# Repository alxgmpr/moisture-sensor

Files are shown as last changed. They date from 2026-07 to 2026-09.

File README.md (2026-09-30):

# moisture-sensor

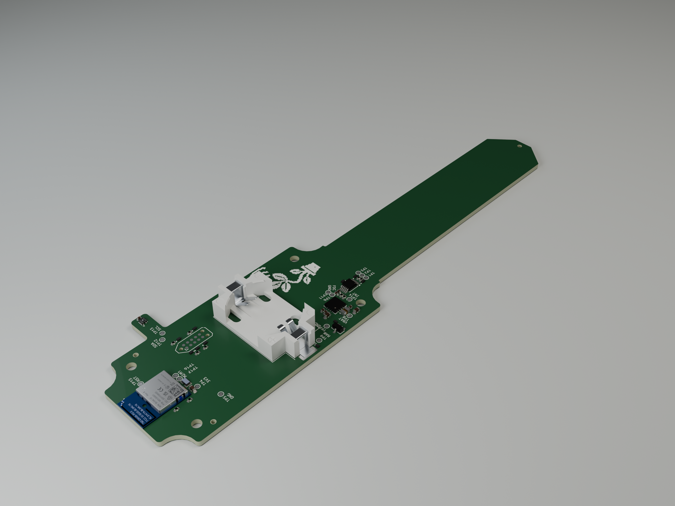
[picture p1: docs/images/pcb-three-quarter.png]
Three-quarter PCB render with the MCU module in the foreground


A CR2032-powered Bluetooth soil-moisture sensor with two capacitive sensing zones. An FDC1004 capacitance-to-digital converter measures the probe, an Ezurio BL54L15 (nRF54L15) broadcasts BTHome v2 readings for Home Assistant, and an SHT40 adds temperature and humidity. Configuration and firmware updates happen over BLE.

**Status:** experimental prototype, firmware 0.2.28. SENSE2 shows a weaker response in soil than SENSE1 ([investigation](docs/sense2-investigation-2026-09-25.md)). Moisture percentages are relative to provisional dry/wet endpoints, and battery life and soil accuracy are not yet characterized.

## How it differs

**Y** = included in the device; **N** = not included. Connectivity reflects stock firmware (the BLE sample for b-parasite); other firmware or an external host can add capabilities.

| Feature | This project | [Seeed XIAO](https://wiki.seeedstudio.com/xiao_soil_moisture_sensor/) | [Adafruit STEMMA](https://www.adafruit.com/product/4026) | [Chirp!](https://wemakethings.net/chirp/) | [b-parasite](https://github.com/rbaron/b-parasite) |
| --- | :---: | :---: | :---: | :---: | :---: |
| Capacitive soil sensing | Y | Y | Y | Y | Y |
| Two independently read soil-sensing zones | Y | N | N | N | N |
| Dedicated capacitance-to-digital converter IC | Y | N | N | N | N |
| Operates without an additional controller | Y | Y | N | Y | Y |
| BLE moisture broadcasting in supplied firmware | Y | N | N | N | Y |
| Wi-Fi reporting in supplied firmware | N | Y | N | N | N |
| Onboard coin-cell power support | Y | N | N | Y | Y |
| Onboard AA battery power support | N | Y | N | N | N |
| Relative humidity measurement | Y | N | N | N | Y |
| Audible watering alarm | N | N | N | Y | N |

## Block diagram

```mermaid
flowchart LR
    BAT[CR2032] --> PMIC[nPM2100<br/>power management]
    PMIC --> MCU[BL54L15<br/>nRF54L15 + BLE]
    PMIC -- switched rail --> FDC[FDC1004<br/>capacitance-to-digital]
    FDC -- SENSE1 --- P1[Soil zone 1]
    FDC -- SENSE2 --- P2[Soil zone 2]
    FDC -- I²C --> MCU
    SHT[SHT40<br/>temp / humidity] -- I²C --> MCU
    MCU -- BTHome v2 / SMP --> HA[Home Assistant<br/>Web Bluetooth dashboard]
```

## Build

### Hardware

Open [nrf-moisture-sensor.kicad_pro](nrf-moisture-sensor.kicad_pro) in KiCad. The maintained schematic and PCB are authoritative. See the [BOM](BOM.md) and [design rationale](HARDWARE.md).

### Firmware

Requires Nordic nRF Connect SDK v3.2.2. From the repository root, in an SDK-configured environment:

```sh
west build --sysbuild -p always -b bl54l15_dvk/nrf54l15/cpuapp \
  -d firmware/sensor/build firmware/sensor
sh firmware/sensor/tests/run.sh
```

Wiring, signing, OTA, and SWD recovery are in the [sensor firmware guide](firmware/sensor/README.md). The SDK signing key is for development only.

### Browser configuration

```sh
node firmware/sensor/dashboard/serve.mjs
```

Open <http://127.0.0.1:8766> in Chrome or Edge. Connect during the sensor's advertising window, or use **Explore with demo data** without hardware. See the [dashboard guide](firmware/sensor/dashboard/README.md).

## Notes

Investigation records are in [docs/](docs/).

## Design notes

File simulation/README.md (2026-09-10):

# Reliability simulations

## openEMS

`openems/return_path.m` compares the old D8 return (two through-board transitions and bottom routing) with the revised nearby via and In1 ground finger in a controlled source-return fixture. It uses PEC conductors, εr=4.2 FR4 and an artificial return plate 3 mm above the board. It is **not** the assembled PCB, an IEC ESD generator, a semiconductor avalanche model, or the module antenna.

```sh
docker build -t moisture-openems:bookworm simulation/openems
docker run --rm -v "$PWD:/work" moisture-openems:bookworm \
  octave --no-gui --quiet simulation/openems/return_path.m baseline 0.2 /work/tmp/em-baseline
docker run --rm -v "$PWD:/work" moisture-openems:bookworm \
  octave --no-gui --quiet simulation/openems/return_path.m revised 0.2 /work/tmp/em-revised
```

The completed runs use openEMS 0.0.35 from Debian bookworm, 118,048 cells, 0.0539 ps time steps and stop below −40 dB residual energy. Floating-point mesh duplicates are rounded before smoothing. Initial discarded runs had an unused excitation or insufficient time span; those are not used in the reported comparison.

Results and exact XML inputs: `docs/reliability-2026-09-07/openems/`. In the 200–500 MHz band the revised fixture shows lower apparent inductance, but no independent mesh convergence run was completed. The baseline's negative extracted resistance near the upper frequency limit is a numerical artifact in a passive model. Do not use these curves to specify clamp voltages, ESD survival, radiated emissions, or antenna matching. A decay criterion alone does not validate port extraction.

## Electrostatic probe sweep

`electrostatics/solver.py` solves 2-D finite-volume electrostatics and passes a parallel-plate field/charge check. `probe_sweep.py` sweeps ideal lossless exterior εr=1/5/20/40 and εr=3 coating of 0.2/0.6/1.0 mm around a 20 mm wide, 1.6 mm thick board. It includes a 16 mm electrode and surrounding four-layer equipotential shield, with no backing copper below the electrode. Charge per length is multiplied by the 30 mm electrode length.

```sh
.venv-cq/bin/python -m unittest discover -s simulation/electrostatics
.venv-cq/bin/python simulation/electrostatics/probe_sweep.py
```

This needs NumPy/SciPy. It omits end fringing, the other electrode, lossy/conductive soil, exact shield cutouts and a finite-impedance shield driver. Reducing grid spacing from 0.2 to 0.1 mm changes results by up to 9.5%; moving the grounded outer boundary from 30 to 50 mm changes them by up to 24.6%. These are sensitivity calculations, not a calibrated moisture prediction. The strong boundary dependence is a reason to measure the finished probe.

A separate conservative surface-coupling calculation in the reliability report covers conductive material immediately outside the coating. Do not apply the benign lossless sweep to saline or conductive wet soil.

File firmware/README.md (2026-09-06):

# Firmware — DK fire-tests

The nRF Moisture Sensor uses BL54L15 453-00001R. See [the module port requirements](BL54L15-port.md); these DK test targets remain unchanged.

Bench tests that run on an **nRF54L15 DK (PCA10156)**, not on our board. They
exist to settle the pin assignment in [HARDWARE.md](../HARDWARE.md) §6 before
the board is fabricated, because those three claims are datasheet readings and
each one moves pins if it is wrong.

Nothing else in the bring-up list can be tested on the DK. Its board-controller
PMIC is not the production nPM2100 and is not on the nRF54L15's bus — see
[NEXT-STEPS.md](../NEXT-STEPS.md) for the DK limitations.

For the BTHome BLE beacon firmware (also DK-only, not a fire-test), see
[bthome-sensor/](bthome-sensor/README.md).

Each test declares its own expected outcome and reports an `*** UNEXPECTED ***`
line when the result disagrees. A negative control that quietly passes is the
result we most need to notice.

## What is being tested

| | Test | Pins | Expect | Claim |
|---|---|---|---|---|
| T1 | `pin-assignment` baseline | SCL P1.11, SDA P1.10 | PASS | our pinout works at all |
| T2 | `pin-assignment` t2 | SCL P1.14, SDA P1.10 | **FAIL** | TWIM SCL needs a dedicated clock pin (Table 77) |
| T3 | `pin-assignment` t3 | SCL P1.11, SDA P0.04 | **FAIL** | peripherals cannot cross ports (§8.8.3) |
| T4a | `systemoff-wake` baseline | P0.04 | wakes | P0 is a wake source (Table 40) |
| T4b | `systemoff-wake` t4b | P2.08 | **cannot arm** | P2 has no SENSE/DETECT/GPIOTE (Table 40) |

T2 and T3 are the tests that matter. T1 only establishes that the harness works
— without it a failure in T2 proves nothing, because it could just be bad
wiring.

## Bench setup

**Set VDD:nRF to 3.3 V in Board Configurator before anything else.**

There is no fixed 3.3 V rail on this board. P6 and the P4 test points carry
VDD:nRF, the programmable 1.8-3.3 V rail, and **the factory default is 1.8 V** —
so an unconfigured DK reads 1.8 V everywhere and there is no 3.3 V to find. The
only fixed supply on the GPIO headers is the 5.0 V on P30/P31/P32 pin 1.

There is no CLI for this: `nrfutil device` exposes board-controller firmware
programming but not the voltage. Open nRF Connect for Desktop, install/open
**Board Configurator**, select the DK, set VDD to 3.3 V, apply. It persists
across power cycles (DK guide §2.9).

**Do not power the breakout from the 5 V pin instead.** Its onboard regulator
would pull SDA/SCL up to 3.3 V against an nRF still running at 1.8 V, which
breaches the VDD + 0.3 V pin limit.

Running the set at 1.8 V would still be valid — none of the three rules under
test is voltage-marginal, and the BME280 die is in spec down to 1.71 V. But it
is not our design point, so a marginal result would be harder to read, and most
breakouts have an LDO on VIN that will not regulate from 1.8 V.

For T1–T3 you need an I²C target. The firmware speaks **BME280/BMP280**,
probing 0x76 and 0x77 and accepting either chip ID. Wire it to header P1:

| Breakout | DK | |
|---|---|---|
| VIN / VCC | VDD:nRF — P6 header (jumper fitted) or a P4 test point, **after** setting it to 3.3 V | not the 5 V on P30/P31/P32 |
| GND | any GND | |
| SCL | P1.11 (T1, T3) / P1.14 (T2) | |
| SDA | P1.10 (T1, T2) / P0.04 (T3) | |

An SHT4x would have been the better target — the SHT45-AD1F is in our BOM
(HARDWARE.md §5), so it would have doubled as driver bring-up, and its 2-byte
CRC gives protocol-level corruption detection. The BME280 has no CRC, so it is
purely a bus target. See "Integrity checking" below.

**Pull-ups.** The overlays do not enable the internal ones, because the board
uses external 4.7 kΩ at 400 kHz and that is the design point under test. Fit
4.7 kΩ to 3.3 V on both lines. Most breakouts carry their own 10 kΩ — that is
a different operating point and a weaker test, so remove them or fit the 4.7 kΩ
in parallel and note what you actually ran.

**Do not press Button 3** during T3 or T4a — it is on P0.04, and a press shorts
the line.

### Integrity checking without a CRC

The BME280 has no checksum, so a corrupt byte is indistinguishable from a real
one at the protocol level. Each pass therefore re-reads the 26-byte factory
calibration block (0x88..0xA1) and compares it against the copy taken at
startup. That block is constant for the life of the part, so any difference is
the bus rather than the sensor — and 26 bytes of known-good data catches more
than a single register would. Mismatches are counted separately from bus
errors, because they mean different things: a NAK is a bus that did not work, a
mismatch is a bus that lied.

Each pass also writes two registers before reading, so a pin that only fails in
one direction still shows up.

## Building and flashing

From `firmware/`, with an nRF Connect SDK environment active:

```bash
west build -p -b nrf54l15dk/nrf54l15/cpuapp pin-assignment
```

```bash
west build -p -b nrf54l15dk/nrf54l15/cpuapp pin-assignment -- -DEXTRA_DTC_OVERLAY_FILE=t2.overlay -DEXTRA_CONF_FILE=t2.conf
```

```bash
west build -p -b nrf54l15dk/nrf54l15/cpuapp pin-assignment -- -DEXTRA_DTC_OVERLAY_FILE=t3.overlay -DEXTRA_CONF_FILE=t3.conf
```

```bash
west build -p -b nrf54l15dk/nrf54l15/cpuapp systemoff-wake
```

```bash
west build -p -b nrf54l15dk/nrf54l15/cpuapp systemoff-wake -- -DEXTRA_DTC_OVERLAY_FILE=t4b.overlay -DEXTRA_CONF_FILE=t4b.conf
```

Then `west flash` and read the console at 115200.

**The console is VCOM1, not VCOM0** — `uart20` is the DK guide's "UART1" on
P1.04/P1.05. On macOS that is the higher-numbered `/dev/cu.usbmodem*` of the
pair. VCOM0 stays silent and looks identical to a dead board.

Flashing without west, from a hex built in the container:

```bash
nrfutil device program --firmware merged.hex --options chip_erase_mode=ERASE_ALL && nrfutil device reset
```

## Reading the results

**T3 is a runtime test.** All five configurations build clean under NCS v3.2.2
— neither dtc nor the pinctrl layer rejects the port crossing, so nothing in
the toolchain knows about §8.8.3. If the rule is real, only the silicon
enforces it.

**T4b's expected result is `-ENOTSUP` from
`gpio_pin_interrupt_configure()`**, not a silent non-wake. A pin that refuses
to arm is a much stronger result than a pin that fails to wake, which is also
what a loose jumper looks like.

**T4a needs the debugger detached.** In Debug Interface mode System OFF is
emulated (datasheet §5.2.1): the CPU keeps running and the device never really
sleeps. The firmware prints a warning if it detects it got past `sys_poweroff()`.

A partial pass in T1–T3 counts as a failure. An intermittent bus is exactly what
a violated timing rule looks like, and it is not something we can design around.

## Results

Run on the DK with a BME280 (chip ID 0x60 at 0x76), VDD:nRF at 3.3 V, the
breakout's own pull-ups, 20 passes per case.

| Case | Pins | Expected | Actual | |
|---|---|---|---|---|
| T1 | SCL P1.11, SDA P1.10, 400 kHz | PASS | **PASS** 20/20 | harness is good |
| T2 | SCL P1.14, SDA P1.10, 400 kHz | FAIL | **PASS** 20/20 | rule not reproducible |
| T2-fast | SCL P1.14, SDA P1.10, 1 MHz | FAIL | **PASS** 20/20 | still not, at the TWIM ceiling |
| T3-control | i2c30, SCL P0.03, SDA P0.04 | PASS | **PASS** 20/20 | sensor + P0.04 wire good |
| T3 | i2c22, SCL P1.11, SDA P0.04 | FAIL | **FAIL** -ENODEV | port rule enforced |
| T4a | wake from P0.04 | wakes | **WOKE** `RESET_LOW_POWER_WAKE` | P0 wakes |
| T4b | wake from P2.08 | cannot arm | **-ENOTSUP** | P2 cannot |

### The port rule holds (§8.8.3)

T3 is the one that would have broken a board. A peripheral-domain TWIM
(`i2c22`) cannot reach a low-power-domain pin (P0.04). The control is what
makes this stand up: same sensor, same P0.04 wire, `i2c30` instead of `i2c22`,
and it passes 20/20. Both lines were verified to carry external pull-ups with
`pin-probe` immediately before the T3 run, so "no device" is not a loose wire.

**Keep SDA and SCL on the same port.** Confirmed by experiment, not just by
reading.

### The clock-pin rule is not reproducible here (Table 77)

A non-clock pin works as TWIM SCL at 400 kHz and at 1 MHz, which is the TWIM
ceiling on this part. There is no faster I²C test available, so via TWIM the
requirement cannot be made to bite at all.

**This does not mean the requirement is void.** Table 77 is a timing-margin
claim — clock pins are "optimized to ensure correct timing between the clock
and data signals". A pass shows the margin was not consumed at this rate, at
room temperature, on 10 cm of jumper wire. Process corners, temperature, and a
real PCB are all outside what was tested.

Worth noting Table 77 also requires a clock pin for SPIM `SCK`, and SPIM00 runs
at 32 MHz where pin-to-pin skew genuinely matters. The requirement is plausibly
dimensioned by the fastest peripheral and applied across the table. That is a
hypothesis these results are consistent with, not something they establish.

**Design call: keep P1.11.** It costs nothing and satisfies a documented
requirement, and a room-temperature bench test that did not fail is not
evidence against one. What the result buys is a known-large margin at our
400 kHz operating point, so deviating later would be a low-risk deliberate
choice rather than a blind one.

### The wake rules hold (Table 40)

T4a produced a genuine System OFF wake from P0.04 — `RESET_LOW_POWER_WAKE` on
the following boot, which only a real wake sets, and the emulated-System-OFF
warning never fired. T4b returned `-ENOTSUP` from
`gpio_pin_interrupt_configure()`: P2 will not even arm a level sense. That is
the stronger of the two possible negative results, since a refusal cannot be
confused with a floating pin.

**PMIC_INT stays on P0.00.**

### Was this worth doing?

Not as much as it looked when proposed. All four claims confirmed what we had
already read and already designed to, so the pinout is unchanged. The prior
probability that Nordic's tables were correct was high, and a test that can only
return "yes, you were right" carries little information.

What it did buy: the pinout is demonstrated rather than assumed; there is now a
working container build, flash and console path plus `pin-probe`, all of which
real bring-up needs and all cheaper to debug against a known answer; two bench
traps are documented; and the clock-pin margin turns out to be large.

The untested risk is entirely in the power chain — boost configuration and the
LDOSW gate for `+3V3_FDC_SW`. Those are our topology decisions rather than
claims established by these DK tests, and they need the production PMIC on the
bench (or the nPM2100 evaluation hardware).

### Bench traps that cost time

- **The P1 header's 00-03 positions are parenthesized on the silkscreen** and
  are not connected without modification (P1.00/P1.01 need SB3-SB6, P1.02/P1.03
  are NFC1/NFC2 and need 0 Ω resistors). P0.00-P0.04 are *not* parenthesized.
  Wiring "03" and "04" on the P1 header instead of the P0 header lands on
  P1.03 (not connected) and P1.04 (`uart20` TXD, the console).
- **The P6 jumper feeds VDD:nRF.** With it out, the SoC is unpowered while the
  debugger stays alive on USB 5 V, and `nrfutil device reset` fails with "debug
  port unavailable" rather than anything mentioning power.
- **Each GPIO header carries its own `VDD:IO` pin** — buffered VDD:nRF, so
  3.3 V once configured, and a more convenient supply for a breakout than P6.
- **`sys_poweroff()` makes the device unprogrammable.** T4a sleeps 5 s then
  enters System OFF, and a device in System OFF does not answer the debugger —
  the next flash simply fails. Press RESET and program inside the 5 s window,
  or `nrfutil device recover`. T4b returns early and never sleeps, so it is
  safe to leave on the board.
- To put the DK back in a sane state, build and flash the stock sample:
  `west build -p always -b nrf54l15dk/nrf54l15/cpuapp $ZEPHYR_BASE/samples/hello_world`.
  It prints on VCOM1.
- Two failures in a row here were bench faults, not results. `pin-probe` exists
  because `-ENODEV` and a loose wire are the same reading; run it before
  banking any negative result.

## What to do with an unexpected result

T2 or T3 passing means the corresponding rule in HARDWARE.md §6 is not what we
read it to be. That does not immediately free the pin — it means the reading is
unreliable and all three need re-checking against the datasheet before the
pinout is frozen. Note it in NEXT-STEPS.md rather than acting on it directly.

## Build status

All five configurations compile under **NCS v3.2.2** and the resolved
devicetree was checked against the intent in each case — `psels` decode to the
pins named in the table above, and the negative controls really do carry
`CONFIG_TEST_EXPECT_*=n`.

**Run on hardware so far:** T1 boots on the DK, `i2c22` initialises, and the
probe correctly reports `-ENODEV` at both addresses with nothing wired. That
exercises the no-device path and shows the harness reports honestly. No test
in the table has produced a real result yet — that needs the BME280 attached.

Notes on choices that the board DTS forced:

- **`i2c22`, not `i2c20`.** UARTE20 and TWIM20 are the same peripheral
  instance, and `uart20` is the Zephyr console on this board.
- **The console is `uart20` on P1.04/P1.05** — the DK guide's "UART1", not the
  P0 UART. P0.00–P0.03 are still claimed by `uart30`, which the board DTS also
  enables, so they stay off limits for a different reason.
- Node labels used by the overlays (`led1` = P1.10, `led3` = P1.14,
  `button3` = P0.04) were read from `nrf54l15dk_common.dtsi`, not assumed.

Editors will flag the Zephyr includes as missing until a build generates
`compile_commands.json`. That is the language server, not the code.

## Reproducing the build without an NCS install

The toolchain image is amd64-only, so this runs under emulation on Apple
silicon — slow but workable for apps this size.

```bash
docker volume create ncs-src && docker run --rm --platform linux/amd64 -v ncs-src:/workdir -w /workdir ghcr.io/nrfconnect/sdk-nrf-toolchain:v3.2.2 'west init -m https://github.com/nrfconnect/sdk-nrf --mr v3.2.2 . && west update --narrow -o=--depth=1'
```

```bash
docker run --rm --platform linux/amd64 -v ncs-src:/workdir -v ncs-build:/builds -v "$PWD:/fw" -w /workdir ghcr.io/nrfconnect/sdk-nrf-toolchain:v3.2.2 'source /opt/toolchain-env.sh; export ZEPHYR_BASE=/workdir/zephyr; west build -p always -b nrf54l15dk/nrf54l15/cpuapp -d /builds/t1 /fw/pin-assignment'
```

The image's entrypoint is `bash -c`, so the whole command has to be one quoted
string — `docker run … uname -m` runs `uname` with `$0` set to `-m`.

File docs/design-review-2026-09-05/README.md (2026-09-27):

# nRF Moisture Sensor — design review, 2026-09-05

The existing 0.4/0.5 mm 3V3 traces have ample modeled current capacity for this board. The significant unresolved power issues are effective capacitance, CR2032 droop, PMIC mode/power limits and radio supply ripple. I²C uses the correct module pads. A smaller outline is feasible to explore, but the proposed lower-right module location cannot simply replace the present placement without mechanical/RF changes.

## Work completed

| Task | Result |
|---|---|
| Sweep checkpoint before edits | `0a7771b`; design, libraries, scripts and review records preserved; scratch/caches omitted |
| Rename | KiCad project/schematic/PCB/rules now `nrf-moisture-sensor`; displayed title **nRF Moisture Sensor**; current tools and tests updated |
| Copper/current review | [Actual widths, polygons, vias, stackup, reproducible sweeps and bench procedure](../power-review-2026-09-05/README.md) |
| Module pins and capacitor review | [Exact pin mapping, capacitor inventory, manufacturer evidence](../component-review-2026-09-05/README.md) |
| Schematic readability | [A2 schematic PDF](../schematic-review-2026-09-05/nrf-moisture-sensor-schematic.pdf), section labels, corrected PMIC graphics; electrical netlist unchanged |
| Shrink assessment | [30 mm trim feasibility](shrink-feasibility.md) and [dimensioned concept](shrink-concept.png); live outline and module placement retained |
| BOM synchronization | [BOM.md](../../BOM.md) regenerated from [KiCad-exported source fields](product-bom.csv) |
| Final verification | Zero DRC errors, zero unconnected items, zero schematic parity issues; zero ERC errors; 43 tests and 261 subtests pass |

The repository directory remains `/Users/alex/moisture-sensor` so the active workspace and existing local integrations continue to resolve. Open `nrf-moisture-sensor.kicad_pro` for future editing. Old root fabrication outputs were moved to `tmp/pre-rename-fabrication`; historical reports/backups retain their original names. No fabrication package was released.

## Findings that affect the design

- **3V3:** actual outer-layer traces are 0.4/0.5 mm on 35 µm copper. IPC-2221 screening gives approximately 1.23/1.45 A at a 10°C temperature rise; deliberately reduced geometry gives 0.89/1.05 A. These are model results, not certified board ratings. The long SHT branch is approximately 4.1–7.5 mV at 100 mA, excluding trunk, return and supply droop.
- **Stackup:** modeled from the board's 35/15.2/15.2/35 µm copper. JLC's standard four-layer designation does not uniquely determine dielectric construction; confirm the selected stack when ordering.
- **I²C:** U1.35 is P1.11/SCL and U1.28 is P1.10/SDA. This is valid for TWIM22. Module land numbering does not imply fixed adjacent pairs; no pin swap is needed.
- **C21:** current 10 µF 0402 selection has insufficient demonstrated DC-bias margin against the 3.5 µF effective minimum. Typical curve plus tolerance screening gives about 3.2 µF at fresh-cell voltage. Qualify or revise it before release.
- **C23:** the exact 22 µF VINT capacitor's worst-case biased value remains unqualified. Obtain the exact manufacturer curve/model and include tolerance, temperature and aging.
- **VOUT:** C3+C25+C27 are 12.3 µF nominal, 14.75 µF at positive production tolerances before bias, temperature and module loading. The effective upper limit is 15 µF. C26/C28 belong to the LDOSW branch from VINT and must not be directly added to VOUT.
- **Peak loads:** nPM2100's 450 mW limit corresponds to about 136 mA at 3.3 V under its specified conditions. The SHT45 heater alone can require 100 mA; stagger radio/heater operation and characterize the real battery. Bulk bypass cannot sustain its 100 ms–1 s heater pulse.
- **Radio:** validate ≤10 mV ripple at the module. HP-mode scheduling and transient behavior need prototype measurements; width calculations cannot establish this.
- **Size:** cutting at Y=70 mm would reduce overall length from 155 to 125 mm. The examined lower-right module placement conflicts with battery-terminal antenna clearance and leaves only 0.2 mm to the mounting-hole edge. A coupled placement/enclosure redesign is required.

## Board cleanup and rule rationale

1. Connected isolated J4 ground pad 3 with a 0.2 mm local trace and 0.5/0.2 mm via; refill verifies connectivity.
2. Removed the overlap between GND via-stitching generator regions while preserving every existing generated via. Future generator areas are disjoint.
3. Renamed the extra board-only fiducial FID4, synchronized FID1–FID3 descriptions, corrected a back-layer text mirror, and moved one conflicting C13 silk segment to fabrication graphics.
4. Made the +3V3 pour explicitly solid-connected to its pads. Its previous zero-clearance, no-pad-connect geometry was not evidence of an open circuit, but obscured the intended connection style.
5. Removed retired bare-chip RF/clock net assignments and added the missing protected probe/debug/battery net classes. This exposed previously unenforced SENSE rules at the local input fanout.
6. Kept the long sensing-channel 0.6 mm separation, 1 mm ground spacing and 3 mm switching separation. A bounded 3.35 × 3.3 mm front-side `FDC_InputFanout` area permits 0.2 mm local SENSE escapes at U3/R30/R31. The two sides of each series input resistor are the same sensing channel and use 0.2 mm separation, rather than being mistaken for separate channels. The existing U3 pad-to-pad package exemption remains last in rule precedence. These are geometric exceptions, not a noise/crosstalk qualification.
7. Moved the 0.4 mm GND diagonal beside the FDC input pads onto B.Cu with two 0.6/0.3 mm vias, preserving its width and endpoints and removing the front-layer sense-to-ground spacing conflict. All-track DRC and refill pass.

No capacitor values, GPIO assignments, module placement, sensing electrode geometry or board outline were changed.

## Verification and limits

- [Final DRC](final-drc.json): **0 errors, 0 unconnected, 0 parity**, with zone refill and all-track error checking enabled. **10 footprint-library mismatch warnings remain** (C13, C21–C27, U2, U4). Customized board copies should be reconciled with approved local library variants before manufacturing; do not blindly replace their geometry.
- [Final ERC](final-erc.json): **0 errors, 10 existing capacitor-symbol library-copy warnings**. These do not imply disconnected nets, but remain library maintenance work.
- [Tests](tests.txt): **43 passed, 261 subtests passed**. Initial failures were stale net-class settings and incomplete expected bare-copper model coverage; recorded in [baseline output](tests-baseline.txt).
- [Schematic preservation](../schematic-review-2026-09-05/verification.json): all **58 nets**, **44 component values/footprints**, and pin numbers/names/types match the baseline.
- [Layer overview](layers-overview.png) and individual [SVGs](layers/) were exported from the final filled board and visually reviewed. The [assembled 3D preview](assembled-preview.png) includes U1 via a review-only copy with its JLC-stage DNP flag removed. The manufacturing source keeps that flag. This is a visual assembly check, not a numerical solid-interference or enclosed RF analysis; the actual cell, screws and enclosure require physical validation.
- [Source hashes](source-sha256.json) identify the final reviewed KiCad sources. Current sweeps are analytical screening only. No hardware, thermal FEA or validated converter transient simulation was run.

## Remaining tasks

1. Qualify C21/C23 and total module-loaded VOUT effective capacitance; revise the reservoir selection if it cannot meet the limits.
2. Implement/verify module firmware pinctrl, regulator mode scheduling, FDC sequencing and heater/radio mutual exclusion as appropriate.
3. Run the bounded battery/load/ripple/I²C bench procedure in the component and power reports, including cold/depleted cells and bus back-power behavior.
4. Reconcile remaining footprint and capacitor-symbol library-copy warnings without overwriting deliberate land changes.
5. Develop a smaller placement jointly with antenna clearance, holder, mounting and sensor-airflow/enclosure constraints; then reroute and repeat DRC/ERC/RF qualification.

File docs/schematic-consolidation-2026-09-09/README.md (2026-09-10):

> Subsequent status: Alex updated the PCB and the regenerated JLC export has zero unconnected items and zero schematic parity issues. See [Rev A checkpoint](../rev-a-checkpoint/README.md). This document records the earlier schematic-only step.

# Consolidated schematic implementation

Implemented all agreed BOM optimizations in `nrf-moisture-sensor.kicad_sch`.
PCB file and routing are unchanged by this work; Alex will update the board.

- C21/C23 now match C3: CL10A106MA8NRNC / C96446, 10 µF 25 V X5R.
  **Their assigned footprints change from 0402 to 0603.**
- C26 now matches C25: CL05A225MQ5NSNC / C12530, 2.2 µF 6.3 V X5R, 0402.
- D1/D2/D3 now match D4–D10: TPD1E01B04DPYR / C779389; symbol library IDs
  and datasheet fields also updated. Existing DPY footprint retained.
- R30/R31 now match the four I²C pull-ups: 0402WGF4701TCE / C25900, 4.7 kΩ.
- U4 is SHT40-AD1B-R2 / C2909890, without the integrated membrane. Existing
  four-pad SHT4x footprint without a central solder pad is retained.
- R1 and C13, their isolated wires/labels and C13's GND symbol are removed.
  Former SWD_RST labels now use NRESET, directly joining U1.7, U2.10, R35.2
  and TP15.1. Keep D7 and R35. The PCB update must bridge former R1 rather
  than leave its series path open. Schematic notes updated to match.

## Verification

- Before/after exported KiCad XML netlists compared pin-by-pin: the only net
  changes are deletion of R1/C13 and merging SWD_RST into NRESET. All other
  component-pin connectivity is preserved.
- ERC: **zero errors, nine existing library-symbol mismatch warnings**.
  Baseline had zero errors and eleven warnings. See [ERC](erc.json).
- Grouped native BOM export has **14 assembly purchase lines**, four capacitor
  SKUs, one diode SKU and two resistor SKUs. U1 remains JLC-stage DNP for manual fit.
  [Review BOM](JLC-BOM-review.csv) and [full product BOM](Product-BOM.csv).
- Rendered schematic exported and visually inspected at module/reset, PMIC,
  sensors and protection sections. No new overlapping changed-value text found.
- PCB SHA-256 before and after this work is identical. No PCB parity/DRC claim:
  board update remains outstanding by user instruction.

The existing suite includes checks of the previous exact reservoir selection and
old schematic/PCB parity; these have not been changed to conceal the intentional
handoff mismatch. Use the netlist/ERC evidence above for this schematic-only step.
Finish board synchronization before updating the coupled board expectations and
running fabrication validation.

Capacitor choices implement the requested development plan; effective-capacitance
corner checks, startup/ripple and sensing measurements remain outstanding as
recorded in the [design decision](../dev-bom-consolidation-2026-09-09.md).
The BOM files here are schematic review exports, not a new routed fabrication package.

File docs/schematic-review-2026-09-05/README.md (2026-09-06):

# Schematic readability review — 2026-09-05

The editable project is `nrf-moisture-sensor.kicad_sch`, titled **nRF Moisture Sensor**. A printable review is `nrf-moisture-sensor-schematic.pdf`; `after/overview.png` and four cropped images show the final layout.

## Changes

- Repacked the previous mostly empty A1 sheet onto A2. Removed an empty legacy section.
- Added consistent colored functional frames for the radio, module support, SWD, crystal/battery, power, protection, and sensors.
- Made hidden rail names visible, hid internal power reference designators, moved overlapping SHT45 and inductor values, and removed duplicate test-point value text.
- Included C28 inside the sensing group, explicitly distinguished the main 3.3 V and switched FDC supplies, and labeled reset support, I2C pull-ups, the primary-cell restriction, and module assembly intent.
- Corrected the nPM2100 symbol's graphical pin direction/body arrangement and widened pin spacing. Pin names now appear inside the body; connection locations and attached objects moved together. Updated `lib/nordic/NPM2100-QEAA.kicad_sym` to match the embedded symbol.
- Kept the existing DNP attribute on U1; its red cross denotes hand fitting after JLC assembly, as noted on the sheet.

## Verification

`verify_netlist.py` compares before/after exported XML netlists. All **58 nets, 44 component values/footprints, and library pin numbers/names/types are identical**. It writes `verification.json` and fails on any difference.

Final ERC: **0 errors, 10 warnings**. All ten are existing `Device:C_Small` library-copy mismatches; the intentional custom capacitor graphics differ from the installed stock symbol. There is no PMIC library-copy mismatch after synchronizing its project library. No electrical connections, component values, footprints, or PCB placement were changed by this readability pass.

Visual inspection included the original overview, four final regional crops, and repeated revisions of the PMIC, support, and sensor sections. The before/after XML and SVG exports are retained for review.

This pass verifies graphical cleanup and preservation of the existing circuit. Datasheet adequacy, rail current capacity, and physical prototype testing are separate reviews.

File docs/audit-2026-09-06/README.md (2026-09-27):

# Board protection, derating and EMC audit — 2026-09-06

The current board passes connectivity checks, but I would not release it as a qualified field product yet. The most actionable additions to the previous reviews are the probe ESD return routing, exposed shield protection, firmware restrictions imposed by the tied shield outputs, and the mismatch between the actual probe copper and the documented sensing geometry.

This is a read-only design audit: no maintained schematic, PCB, BOM, or firmware was changed. KiCad application replacement was coordinated with the updating task. Fresh checks used KiCad 10.99.0-3619-g0ef48b972f. No hardware measurement or full electromagnetic simulation is claimed.

## Findings, in priority order

### 1. Probe ESD returns take a long route through the sensing area — P1, confirmed geometry

D8/D9 at y112.2 sit below the solid electronics ground boundary at y106.9. Their ground vias do **not** drop directly into a ground plane there: both inner layers are SHLD in this region. D8 ground runs 1.96 mm on F.Cu, through a via, 3.82 mm on B.Cu, through another via, then onward to ground. D9 returns through about 5.43 mm of F.Cu before joining that path. This contradicts the older protection report's description of local vias returning directly to In1 ground.

Those conductors can be perfectly connected at DC while allowing substantial ESD ground bounce. ESD current also crosses the analog input region. Relocate the clamp/resistor boundary toward the electronics ground, or deliberately provide a short, broad ground return corridor and recalculate the sensing parasitics. Do not simply convert probe shield vias to ground. Validate both polarities with the finished coating and the FDC powered on and off.

Evidence: [fresh copper layers](layers.png), [geometry extraction](geometry.txt), current D8/D9 ground traces and vias at (68.8,110.238616) and (71.5,107.538616) mm.

### 2. D10 does not establish safe shield-pin voltage — P1, unresolved protection coordination

The netlist connects D10, TP3, U3.1 and U3.6 directly. Unlike the CIN paths, it has no series current limiter. The fitted TPD1E01B04DPY is a bidirectional transient suppressor, not a 3.3 V precision clamp: typical breakdown is 6.4 V, with typical TLP clamp levels of 7 V at 1 A and 15 V at 16 A. Its IEC component rating does not certify this circuit. The exact DPY capacitance is 0.20 pF typical / 0.23 pF maximum at the stated test point; the older 0.18 pF description belongs to DPL. [TI suppressor datasheet](https://www.ti.com/lit/ds/symlink/tpd1e01b04.pdf).

FDC analog pins are limited to −0.3…VDD+0.3 V and 3 mA input current. Review secondary protection and the residual waveform at the IC, especially with VDD discharged. R30/R31 help CIN protection, but 5.1 kΩ is not proof of compliance: for illustration, (15−0.3)/5100 ≈ 2.88 mA when unpowered, before overshoot and tolerance. A resistor also does not establish pin voltage unless a clamp conducts. [TI FDC1004 datasheet](https://www.ti.com/lit/ds/symlink/fdc1004.pdf).

Do not add a large shield resistor blindly: it can spoil shield tracking. Compare revised protection on prototypes against sensing noise, drift and ESD recovery. Ordinary resistor wattage does not establish nanosecond pulse survival.

### 3. C21 is still marginal; C23 and total VOUT remain unqualified — P1

The current source still selects these exact capacitors:

| Node | Parts | Check / action |
|---|---|---|
| VBAT | C21 10 µF 6.3 V X5R, CL05A106MQ5NUNC; C22 1 nF | Require ≥3.5 µF effective. Exact-part typical DC-bias graph gives roughly 40% retention at fresh-cell voltage: 10×0.40×0.8≈3.2 µF, before further allowances. Qualify or revise C21. |
| VINT | C23 22 µF 6.3 V X5R, GRM155R60J226ME11D; C24 1 nF | Require ≥3.5 µF effective. At −20% tolerance it needs ≥19.9% retention before temperature/aging allowance. Exact guaranteed minimum is not established by the retrieved information. |
| VOUT | C3 10 µF + C25 2.2 µF + C27 0.1 µF, plus module | 12.3 µF nominal external; 14.75 µF at positive listed tolerances before bias/temperature/module. Check the complete 0.7–15 µF effective range. This upper screening bound is not proof of failure. |
| FDC switched rail | C26 1 µF X7R + C28 0.1 µF X7R | Values appropriate; C28 is nearer U3.8. This branch comes from VINT through LDOSW and is not directly included in the VOUT sum. Test turn-on load independently. |

Re-inspected the [exact C21 characteristic plot](../component-review-2026-09-05/c21-characteristics.png). Its separate biased-temperature graph is less pessimistic than multiplying separate typical curves, so the calculation above is a screening concern, not a guaranteed failing lot. Obtain combined bias/temperature behavior and aging allowance. Samsung confirms the selected part is 0402, ±20%, X5R to +85°C; do not infer a +125°C product rating from the sensor ICs. [Samsung part page](https://product.samsungsem.com/mlcc/CL05A106MQ5NUN.do).

The 6.3 V capacitors have useful voltage-rating margin on 3.3 V rails, but voltage rating and effective capacitance are separate checks. Sources: local [Nordic hardware guidelines](../../doc/datasheets/nPM2100_HW_Design_Guidelines_nwp_058.pdf), §3.2–3.4, and [nPM2100 datasheet](../../doc/datasheets/nPM2100_Datasheet_v1.0.pdf), Table 10. Component lookup confirmed C23 identity, not its bias curve. Larger capacitance belongs on VBAT/VINT when justified; arbitrary extra VOUT bulk is inappropriate.

### 4. Firmware-dependent safeguards are not implemented in the checked application — P1

[main.c](../../firmware/bthome-sensor/src/main.c) calls `sim_values()` and advertises the result. It has a SoC watchdog, but no actual PMIC/sensor sequence in this path. The [port requirements](../../firmware/BL54L15-port.md) are requirements, not implementation evidence.

The sensor implementation needs to establish 3.3 V before enabling FDC; configure LDOSW as a load switch; force and settle HP for measurement/radio; enforce heater/radio load policy; handle a stuck I²C bus with bounded timeouts; and implement low-cell lockout/retry behavior. Configure the PMIC watchdog/recovery deliberately and reapply configuration after PMIC power-cycle resets. SYSGDEN is grounded, disabling the startup boot monitor. A host watchdog reset alone does not necessarily clear a wedged always-powered peripheral. Test reset causes and recovery, including SHT bus lock and interrupted PMIC writes.

U3.1 and U3.6 are tied together: permit single-ended measurements only; do software subtraction if needed. Differential mode drives the shield outputs for different channels. Also, the FDC's independent 6 V SDA/SCL absolute maximum does **not** specify unpowered leakage. Measure the off-rail voltage/current and obtain manufacturer confirmation before claiming zero back-powering. [TI FDC1004 datasheet](https://www.ti.com/lit/ds/symlink/fdc1004.pdf), §§5.1, 5.6 and 6.3.1.

### 5. Battery capability, fault containment and heater policy need a defined cell — P1 for field release

No fuse, PTC, battery-side current cutoff or sustained overvoltage cutoff is fitted. Q1 blocks reverse insertion; it is not a fuse or complete reverse-current barrier. D1 is directly across the raw cell, and C21/D2 are upstream of the PMIC. A short there bypasses downstream load-switch protection. Do not interpret the PMIC's valley-current limiter as a guaranteed battery safety current cutoff. Review the exact cell's short-circuit behavior and the entire fault path.

A fuse/PTC is a **conditional design decision**, not automatically mandatory or automatically useful. Its guaranteed clearing/trip curve must operate at available cold/depleted-cell fault current while tolerating normal converter pulses and acceptable series drop. A PTC that never trips provides little protection. If fitted, place protection sufficiently close to the positive contact to cover downstream shunts; an upstream D1 short would otherwise remain unprotected. Consider an independently acting low-leakage disconnect if fault tests require it. Do not use a narrow PCB trace as an improvised fuse.

J4.1 connects directly to +3V3: treat it as VTref only. External powering/backfeed with a cell installed requires a separately validated power path; Q1 alone does not guarantee no charging of the primary cell. Specify CR2032 chemistry and exclude rechargeable lookalikes with higher voltage.

The heater can dominate the cell load: 100 mA at 3.3 V is 330 mW, requiring about 194 mA at 2.0 V with an illustrative 85% efficiency, before other loads. A CR2032 label or holder rating does not establish this capability. Keep the heater disabled until qualified; use the lowest effective setting and allowed duty cycle. See [prior load analysis](../power-review-2026-09-05/README.md) and [SHT4x v7.3 Table 4](../../doc/datasheets/sensirion-sht45/HT_DS_Datasheet_SHT4x_V7.3.pdf).

### 6. Probe field geometry and shield load are not qualified — P2

The current filled copper has **zero projected shield overlap beneath either 16×30 mm electrode on all three lower layers**. Shield surrounds the electrodes; it does not cover their backs. Both inner layers carry SHLD around the probe openings. This differs from LAYOUT.md's continuous backing-shield description and its old 6 pF ground-overlap estimate. It is not automatically wrong for soil sensing, but calibration and backside-object sensitivity must match this actual construction.

Projected shield-fill/ground-fill overlap is also zero in this snapshot; that does not imply zero shield load. Fringing, tracks, exposed outer shield, coating and conductive wet soil remain. For scale only, a hypothetical 600 mm² surface facing a conductor through 0.05 mm of εr=3 coating gives C≈319 pF. That is already comparable to the 400 pF shield capability before other contributions. This is a sensitivity example, not an extracted assembled capacitance. Measure shield amplitude/phase and sensing range in dry/wet/saline media with the final coating and mechanical placement.

R30/R31 also alter the measurement transfer function. At 100 pF their RC is 0.51 µs; validate calibration and settling across actual input range instead of assuming a simple DC RC model proves switched-capacitor accuracy. Inspect coating coverage over edges, vias and TP1–TP3; bare test contacts and moisture tracks can defeat otherwise insulated electrodes. Keep sensor airflow and its membrane free of coating/flux contamination.

### 7. Antenna mechanics and supply noise remain release risks — P1 qualification

The module is at the board edge with all-layer copper exclusion. DRC finds no keepout violation. This does not establish enclosure RF performance: cell/holder metal, screw material, lid, coatings and wet soil are outside those copper rules. The holder model is a visualization substitute, so rendered fit is not physical clearance evidence. The prior mechanical review already identified preferred metal-spacing compromises.

Ezurio requires antenna keepout free of copper and metal hardware and specifies a tight supply-noise condition. Compare the actual assembled module supply against 10 mV during TX/RX; nPM2100 LP/ULP's typical 70 mVpp makes HP scheduling necessary to investigate, not sufficient proof. [Ezurio integration datasheet](https://www.ezurio.com/documentation/datasheet-bl54l10-and-bl54l15-series).

Test closed assemblies with the cell, intended screws and representative soil on low/mid/high radio channels and multiple orientations. Do not add a host antenna choke or matching network: this module has an integrated antenna and no host RF feed. Keep mechanical loads off the module and support the probe shoulder so insertion force does not flex the MLCC/IC region. Enclosure seam capture and weather sealing are still unresolved in the [mechanical review](../../output/product-video/enclosure-review.md).

## Ground planes, beads and common-mode chokes

The electronics have continuous GND on both inner layers, no inner signal/power tracks, and extensive stitching. Preserve that. Multiple connections in a ground plane are useful high-frequency returns, not a reason to cut the plane into stars. In normal battery operation there is no wired earth loop; a debugger, oscilloscope and wet environment can introduce new paths during testing.

Signal transition vias are roughly 1.5–2.8 mm from the nearest ground via in this extraction. Add closer return vias where practical at SWD/clock transitions, prioritizing fast edges, without violating the antenna exclusion. Those distances are a review heuristic, not a compliance threshold. The nPM switch route is short and local; wide power traces are not the main remaining limitation.

| Candidate | Recommendation |
|---|---|
| Ground bead / split analog ground | Do not add. It impedes return current and can worsen coupling. |
| Module-supply bead | Optional tuning provision after measuring spectrum. Check impedance at the actual noise frequencies, DC current/bias, DCR, resonance/damping and load transients. Preserve PMIC local output capacitance and qualify the whole network. |
| Bead in VBAT | Avoid an unmodeled input filter: the coin cell already has high impedance. |
| Beads on CIN/SHLD | Do not add by default; they alter a precision capacitive interface. |
| Common-mode choke | No present external differential data/power cable justifies one. SDA/SCL are not a differential pair. Reconsider at a future cable boundary if common-mode testing identifies a problem. |

Ferrite beads can resonate with ceramic capacitors and lose impedance under DC bias; a nominal “600 Ω at 100 MHz” value is not a cure for low-frequency burst ripple. [Analog Devices AN-1368](https://www.analog.com/en/resources/app-notes/an-1368.html).

## Focused prototype and EMC test plan

1. **Power/derating:** exact capacitor model/lot checks at operating voltage and temperature; cold-start and hot-plug waveforms; emulator voltage/impedance sweeps followed by specified real cells; measure rails at C21/C23/C25/U1/U3/U4. Record extrema, source current and mode transitions. Test heater separately before concurrency.
2. **Sensing:** known reference capacitors, both channels, final coating and dry/wet/saline media; inspect shield tracking, full-scale/CAPDAC headroom, hysteresis, temperature drift and radio-on/off error. Repeat with objects behind the electrodes.
3. **Fault/recovery:** staged current-limited fault characterization, reversed battery, FDC off-state leakage, stuck SDA/SCL, failed startup, brownout and watchdog recovery. Battery abuse/short testing belongs in a controlled fixture using the cell supplier's guidance, not an improvised direct short.
4. **EMI pre-scan:** near-field H/E scans at the PMIC/inductor, digital routes and probe; compare sleep, conversion, TX and heater states. Radiated emissions and receiver performance should include final assembly, operating modes and supply extremes. Watch for false measurements and permanent sleep-current increases, not just resets.
5. **Immunity:** agree product-specific ESD and radiated-RF targets with the lab; exercise accessible battery/debug/probe points and enclosure seams, powered and unpowered. Separate direct strikes from indirect coupling. Choose EFT/surge/conducted-RF tests according to actual external ports and environment; a battery-only board does not automatically need every mains-port test.
6. **Product completion:** validate sealing, insertion/drop/bending and cell retention. If sold as a US consumer product, determine applicability of coin-cell compartment and labeling rules even if shipped without a cell. [CPSC guidance](https://www.cpsc.gov/Business--Manufacturing/Business-Education/Business-Guidance/Button-Cell-and-Coin-Battery). Final RF/EMC obligations depend on intended markets and module integration conditions; module approval alone is not a host-product test report.

## Verification record

- [DRC](drc.json): zero errors, zero unconnected items, zero schematic parity issues; ten footprint-library mismatch warnings.
- [ERC](erc.json): zero errors; ten symbol-library mismatch warnings.
- [Fresh netlist](netlist.xml), [schematic render](schematic.png), [all four copper renders](layers.png), [source hashes](source-sha256.json), [geometry details](geometry.txt).
- The [assembled render](assembled.png) uses a temporary copy with U1’s DNP and position-file exclusion flags cleared for visibility. It is visual inspection only, not solid-interference certification; cell/enclosure geometry is not included.
- Existing library-copy mismatches need reconciliation before manufacturing without overwriting deliberate pad modifications. No new tests were written for this read-only audit.

Recommended next design work: resolve C21, shorten the probe clamp returns, qualify shield protection, and implement the real sensor power/sensor sequence. Then use measurements to decide whether a battery cutoff or module-supply filter is warranted.

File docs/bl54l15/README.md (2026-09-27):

# BL54L15 integration — 2026-09-04

**Actual schematic and PCB migrated; routing handoff, not a fabrication release.**
Alex will hand-route the remaining digital/power connections. All unrelated
net connectivity, outline and retained peripheral placement were checked
against the dirty working-tree snapshot taken before this migration.
See [changed files](changed-files.md), [verification](verification.md), [manufacturing workflow](manufacturing.md),
[current BOM](../../BOM.md) and [firmware requirements](../../firmware/BL54L15-port.md).

## Selected module and verified assets

U1 is **Ezurio 453-00001R**, BL54L15 with integrated PCB antenna,
[DigiKey cut tape 776-453-00001RCT-ND](https://www.digikey.com/en/products/detail/ezurio/453-00001R/26224851).
The BL54L15µ and MHF4 versions are not alternatives. Body is nominally
14 × 10 × 1.6 mm; 39 LGA pads on three sides.

Source of truth is the current [Ezurio BL54L10/BL54L15 datasheet](https://www.ezurio.com/documentation/datasheet-bl54l10-and-bl54l15-series),
accessed 2026-09-04, especially Pin-Out, Power Supply, Mechanical Drawings,
Host PCB Land Pattern and Antenna Keep-Out, Circuit Checklist, PCB Layout and
Surface Mount Modules. This is a living HTML datasheet; the source image
identifiers and hashes are in [source-manifest.json](source-manifest.json).

The project-local symbol is `lib/ezurio.kicad_sym`; the footprint is
`lib/footprints.pretty/Ezurio_BL54L15_453-00001.kicad_mod`.
They were constructed from the manufacturer's pin table and dimensioned
**top-view host land drawing**, not from a similarly named module or the old QFN.
The STEP file `lib/BL54L15_453-00001.step` is the detailed Ezurio model from the
user-supplied 453-00001 trace-antenna ZIP, retained byte-for-byte. The board,
local footprint and model repair mapping use offset (0, -10, 0.40116) mm with
unit scale and zero rotation. This seats the underside lands on the host PCB
and aligns pin 1 and the antenna with the land pattern. See
[model provenance and coverage](model.json) and [mechanical drawing](mechanical-453-00001.pdf).
The old envelope file is retained only for historical snapshots.

## What is integrated and what remains external

| Function | In module | Host action |
|---|---|---|
| SoC main DC/DC | Inductor, filter and DECD/DECA/DECRF support shown inside module power diagram | Remove L1, FB1, C1/C2/C4/C5/C7/C8/C10/C12 and their internal-rail nets |
| Supply bypass | Internal rail decoupling does not replace required host input reservoir | Retain C3, mandatory 10 µF at pad26; 0603 16 V X6S |
| High-frequency clock | 32 MHz crystal; load bank inside SoC | Remove X2 and XC1/XC2; configure internal HFXO loading |
| Low-frequency clock | LFRC and configurable LFXO load banks; no fitted 32.768 kHz crystal | Retain X1 at pads25/24 for timed System OFF wake; tune internal bank |
| RF | Matching network and integrated PCB antenna; no host RF pin | Remove L2/L3/L4/C6/C9/C11, AE1, R27/C29, NT1/NT2 and all RF feed/return nets |
| Reset | Internal pull-up/brownout circuitry | Keep series R1 and C13 filter and J4/PMIC reset topology |
| I²C/programming | SoC interfaces only | Retain R22/R23 pull-ups and all J4 connections |

The CR2032/nPM2100, L10 and C21–C28, FDC1004, SHT45, driven shields, sensing
routes, battery removal corridor and enclosure outline remain. C3/R1/C13 lands
were made standard 0603/0402 to match actual orderable passives.

**Power release gate:** the 3.3 V architecture is retained, but Ezurio's 10 mV
noise/ripple condition is tighter than nPM2100 LP/ULP's typical ripple. Firmware
must hold HP through radio windows and the actual board must be measured.
Direct host VOUT capacitance is 12.3 µF nominal; at +20% that is 14.76 µF before
module capacitance. Effective capacitance includes bias loss and tolerance;
verify the converter's 0.7–15 µF range with the complete load. The published
module block diagram does not specify every component's capacitance, so this
upper-limit check is explicitly unresolved. LDOSW is supplied from VINT, so C26/C28 are not directly part of
the VOUT capacitance sum; assess their startup load separately on VINT. Extra capacitors are not a safe
assumed fix. C23's separate VINT bias qualification remains open from before.

## Pin audit

All used GPIO assignments are preserved. NC means intentionally unconnected
in both schematic and PCB; it does not mean a power pin was omitted.

| Pad | Module function | Sensor net / destination |
|---|---|---|
| 1 | GND | GND |
| 2 | P2.09 | NC |
| 3 | P2.08 | NC |
| 4 | P2.07/SWO | P2.07_SWO / J4.6 |
| 5 | SWDIO | SWDIO / J4.2 |
| 6 | SWDCLK | SWDCLK / J4.4 |
| 7 | nRESET | NRESET / R1.1, C13.1 |
| 8 | P2.02 | NC |
| 9 | P2.00 | NC |
| 10 | P2.01 | NC |
| 11 | P2.04 | NC |
| 12 | P2.05 | NC |
| 13 | P2.03 | NC |
| 14 | P1.03/NFC2 | NC |
| 15 | P1.02/NFC1 | NC |
| 16 | GND | GND |
| 17 | P0.00 | PMIC_INT / U2.5 |
| 18 | P0.01 | NC |
| 19 | P0.02 | NC |
| 20 | P1.07 | MARK1 / TP16 (timing marker) |
| 21 | P1.06 | MARK2 / TP17 (timing marker) |
| 22 | P1.05 | FDC_SDA |
| 23 | P1.04 | FDC_SCL |
| 24 | P1.01/XL2 | XL2 / X1.2 |
| 25 | P1.00/XL1 | XL1 / X1.1 |
| 26 | VDD_nRF | +3V3 / C3.1 |
| 27 | GND | GND |
| 28 | P1.10 | SDA / PMIC, FDC1004, SHT45 |
| 29 | P1.09 | NC |
| 30 | P1.08 | NC |
| 31 | P0.04 | NC |
| 32 | P1.14 | NC |
| 33 | P1.13 | NC |
| 34 | P1.12 | NC |
| 35 | P1.11 | SCL / PMIC, FDC1004, SHT45 |
| 36 | P0.03 | NC |
| 37 | P2.10 | NC |
| 38 | P2.06 | NC |
| 39 | GND | GND |

## Land geometry, orientation and keepouts

See the [current zone simplification](../zone-simplification/README.md): the
antenna rule area now follows only the hatched region in Figure 11.

Local footprint origin is the top-left of the manufacturer's top-view body.
Body x=0..14, y=0..10 mm; the antenna is toward x=14. All lands are
0.45 × 0.60 mm. Pad1 is (11.8,9.497), then pads2..16 step −0.75 mm in x;
left-side pads17..27 are (0.5,8.75) stepping −0.75 mm in y, rotated 90°;
pads28..39 are (0.55,0.503) stepping +0.75 mm in x. Pin39=(8.8,0.503).
The pin-1 dot is beside pad1 on the antenna-side end of the bottom row.

The PCB transforms this with origin **(72,54), rotation90°**:
`board_x=72+local_y`, `board_y=54−local_x`. Thus the body is x72..82, y40..54,
antenna end y40 flush with the host edge, centered at x77. Pin1 is
(81.497,42.2), VDD26=(74,53.5), XL1=(74.75,53.5), XL2=(75.5,53.5).

The manufacturer's hatched keepout is local x9..14, y0..8.5, extended
15 mm beyond local y=0. Figure 11's lower ≥15 mm dimension does not identify
another copper-free region below the pad row. The previously added right-hand
exclusion was an incorrect interpretation and has been removed.

The rotated rule area is x57..80.5, y39..45, on all four copper layers, banning
tracks, vias, pads and fills. Ground extends to the right of x80.5, including
the module ground-land strip. The existing pad-39 notch is retained.

Drawing edge case: pad39's 0.45 mm width reaches local x9.025 while the nominal
keepout starts at x9.0. The rule area has a **0.026 mm notch only at that exact
manufacturer ground land** (board x72.196..72.810), retaining the full land and
avoiding a contradictory pad-in-keepout check. It is not permission to put other
copper in the antenna area. All other copper stays outside the defined areas.
No vias may expose solder mask under the module except the required LGA lands.

The fixed 34 mm sensor is smaller than Ezurio's antenna characterization board.
The outline, 1.6 mm thickness, mounting reliefs and Hammond enclosure were
preserved. Keep antenna-end screws nylon and keep wires, metal coatings and
hardware out of the antenna zone. Manufacturer guidance recommends metal
separation of 40 mm above/below and 30 mm left/right in its antenna drawing;
metal within 20 mm is particularly detrimental. The nearest holder body is
about 25.5 mm from the antenna region (about 16.5 mm from the module body).
**The fixed enclosure/battery design does not satisfy all preferred metal
clearances.** No unqualified RF-compliance claim is made. Test the closed
assembly with cell, lid, screws and representative soil; redesign enclosure
metal spacing if performance is inadequate. Module certification alone does
not qualify the finished host product.

## Hand fitting with paste and hot air

U1 is required in the finished product, but schematic and PCB mark it DNP for
JLC. It is absent from JLC BOM/positions and JLC paste; all copper and mask lands
remain. The module-only paste export provides a local stencil pattern.
The module has underside LGA pads; an iron cannot reliably reach the joints.

C3 and X1 are immediately behind the module, with room to approach from the
board edge. SHT45 remains on its jut, about 18 mm from the module body. This
separation helps shield it, but does not establish a safe thermal exposure.
Fit U1 before the battery holder if consignment/assembly sequencing permits;
otherwise protect the holder and confirm its thermal limit. **Never heat with
a CR2032 cell installed.** Keep programming and battery-removal access clear.

Use a local stencil (Ezurio recommends thickness ≥0.1 mm), controlled paste
volume, ESD handling, clean lands, exact pin-1 alignment and low airflow.
A nozzle with controlled preheating should bring every underside joint to
reflow without displacing C3/X1. Shield SHT45 and its PTFE membrane from direct
heat and flux; do not wash/contaminate its opening. Use a thermocouple at the
module and a qualification coupon/representative board to establish the joint
profile; nozzle setpoint is not package temperature. Inspect for alignment,
bridges and opens, then check resistance and current-limited power/SWD. For
hidden-joint confidence, use X-ray where available; visual edge inspection
alone cannot establish every LGA joint's quality.

Ezurio specifies a reflow profile measured at the IC surface: ramp 40–130°C
under 2.5°C/s, preheat 130–180°C for 60–120 s, ramp 180–220°C under 3°C/s,
peak ≤250°C with 225–250°C for 30–50 s, cooling under 3°C/s. Adapt the paste
process within all component limits. The datasheet's hot-air instructions are
for **module removal**, not a validated hand-assembly recipe; do not copy the
330°C nozzle or 280°C hotplate removal settings as an assembly profile.
Manual hot-air attachment is the intended prototype process and remains to be
qualified; a reflow oven is not assumed.

The module is MSL4. Track exposure after opening (72 hours maximum under the
specified dry-pack conditions), keep unused cut tape dry, and follow the
supplier humidity indicator and baking instructions if exceeded. Any module
bake is before assembly and must not be applied indiscriminately to the sensor,
cell, holder or humidity sensor. See the vendor's current material-handling
section for its 125°C/48 h bake condition and packaging restrictions.

## Routing handoff

The [In2 ground conversion](../in2-ground/README.md) now provides ground
beneath bottom-layer signals. All +3V3 connections are routed; 11 existing
signal connections remain. Its endpoint list and DRC report supersede the
power-routing status and anchors below.

Only short XL1/XL2, C3-to-VDD and local ground connections were completed.
Remaining ratlines are deliberate at Alex's request. Preserve the crystal
routes without signal vias, minimize clock loop area, and avoid clocks/SW nodes
under them. Complete module power, reset, SWD/SWO, I²C and PMIC interrupt routes;
join retained trunk anchors or delete obsolete stubs after rerouting. The
current DRC report lists each endpoint. Do not route any layer through the
antenna keepouts or split In1 GND beneath the module.

Useful preserved anchors in absolute mm: SCL on B.Cu at (72.197,68.803), SDA on
B.Cu at (71.1,68.5), PMIC_INT on B.Cu at (80.3,61.4), SWD_RST on F.Cu at
(85.0405,58.725), main +3V3 near (67.8325,68.2), and the J4 +3V3 branch at
(81.24,61.6625). They are routing starting points, not evidence of connectivity.

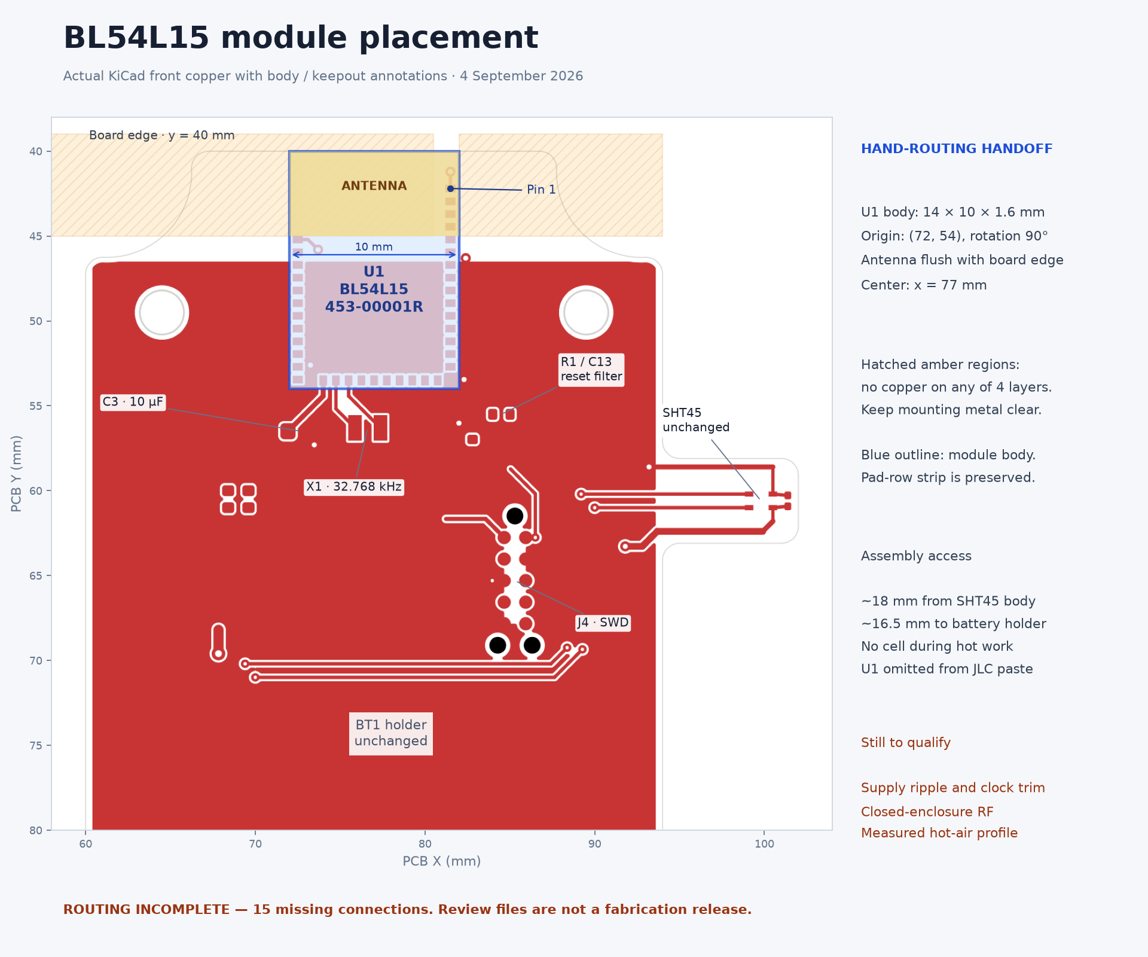
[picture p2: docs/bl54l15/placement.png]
Module placement from actual KiCad copper


## Vendor model preview

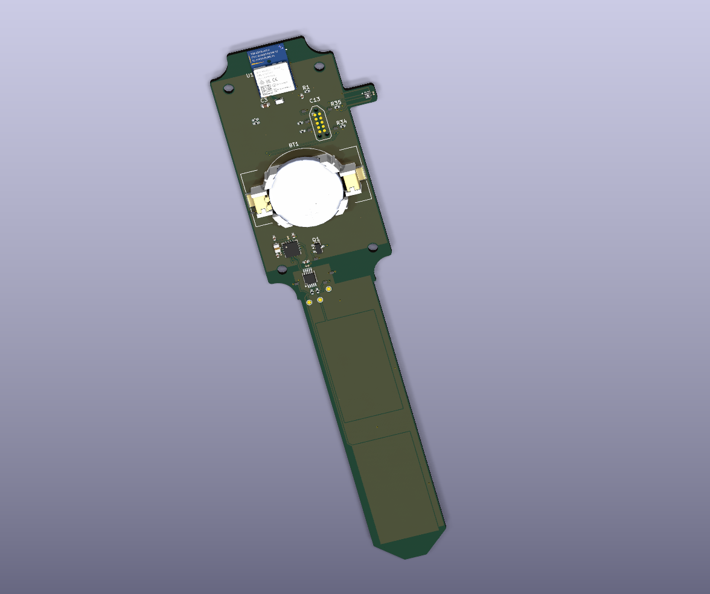
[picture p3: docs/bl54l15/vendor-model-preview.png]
Fitted board with vendor Ezurio model


Preview uses a derived board with assembly exclusions cleared for display.
The maintained board retains U1’s separate hand-fit/JLC exclusion flags; enable
excluded/DNP models in the 3D viewer to display it. All 39 module lands were
checked against the footprint (maximum XY difference 0.00321 mm). Nine model
coverage tests pass; PCB content changed only in U1’s model path and offset.

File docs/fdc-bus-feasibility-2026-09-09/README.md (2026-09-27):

# Dedicated FDC I²C bus feasibility — 2026-09-09

Recommendation: use U1 pad 22 (P1.05) for FDC_SDA and pad 23 (P1.04) for FDC_SCL, on hardware TWIM20. Both pins are unused and emerge from the module edge facing the FDC. Local escape is demonstrated without moving components. This is an evaluation, not an implemented circuit change or completed route.

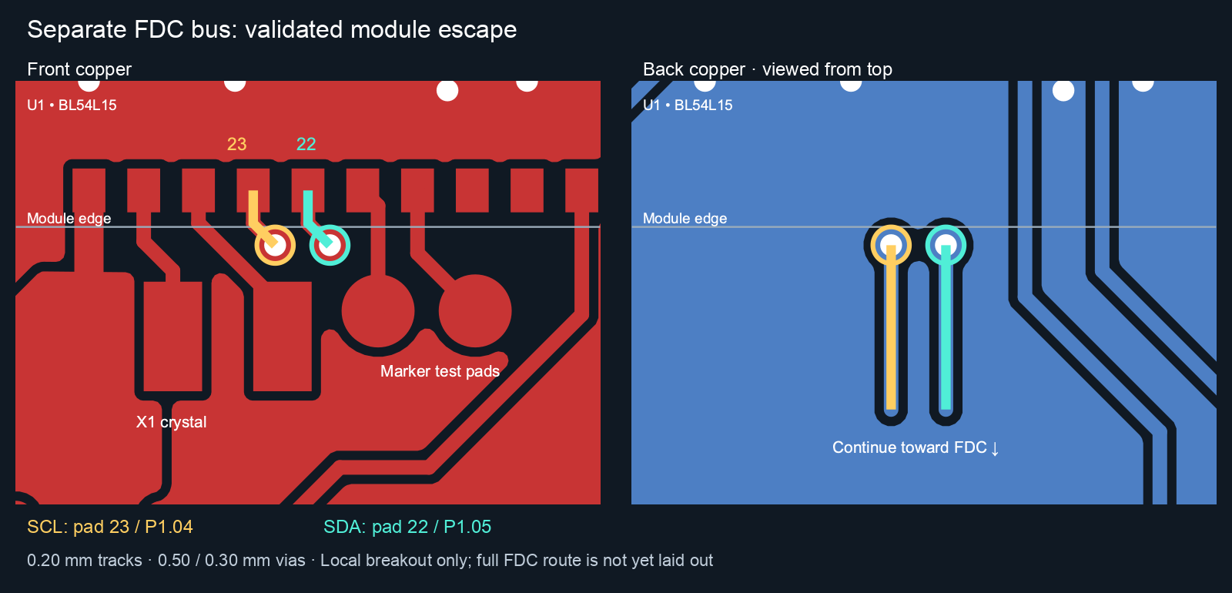
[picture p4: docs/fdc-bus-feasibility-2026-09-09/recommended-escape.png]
Recommended local escape


## Pin and controller selection

| Choice | SDA | SCL | Assessment |
|---|---|---|---|
| Preferred | U1.22 / P1.05 | U1.23 / P1.04 | Adjacent bottom-edge pads, toward FDC; two short front traces and two vias escape to back copper. |
| Alternative | U1.29 / P1.09 | U1.30 / P1.08 | Left-edge pads; validated westward escape, but requires turning south beside the existing bus. |

Module pin mapping: [Ezurio BL54L10/BL54L15 datasheet](https://www.ezurio.com/documentation/datasheet-bl54l10-and-bl54l15-series). P1.04 and P1.08 support the clock function: [Nordic pin table](https://docs.nordicsemi.com/r/bundle/ps_nrf54l15/page/chapters/pin.html-qfn48). TWIM20/21/22 use port P1: [Nordic TWIM documentation](https://docs.nordicsemi.com/r/bundle/ps_nrf54l15/page/twim.html-topic?contentId=ZCNrRd3TXd2U_Zlq48Iw7Q).

Existing main bus uses TWIM22 on P1.10/P1.11. The bring-up overlay and archived built devicetree show TWIM20 is available, with SPI20/UART20 disabled. Keep those shared-instance peripherals disabled when enabling TWIM20. No software I²C is necessary.

## Tested escape geometry

All coordinates are board millimetres. Both traces are 0.20 mm wide; vias are 0.50 mm diameter / 0.30 mm drill (0.10 mm radial annular ring).

- SCL: pad 23 (76.25, 53.50), front trace to (76.25, 53.95), then via at (76.55, 54.25), back trace to (76.55, 56.50).
- SDA: pad 22 (77.00, 53.50), front trace to (77.00, 53.95), then via at (77.30, 54.25), back trace to (77.30, 56.50).

The small diagonal jog matters: a straight SCL escape with a via at (76.25, 54.35) collided with XL2. The recommended placement clears XL2 and the marker pads. The short back traces pass beneath the crystal region; the two intervening ground layers provide separation. Keep those planes continuous in the eventual route.

Both disposable studies ran native KiCad DRC with zone refill, all track errors, and all severities: **0 errors, 106 warnings each**. Only two warnings involve new items: their deliberately unfinished back-track ends. This is not the full-board release/parity check: the studies reuse the existing unused-pin net names, omit the schematic, and do not connect the FDC. Copper exports were separately refilled before visual inspection.

Artifacts: [preferred DRC](study/drc.json), [preferred new-item findings](study/new-item-violations.json), [alternative DRC](left-study/drc.json), [alternative new-item findings](left-study/new-item-violations.json). Scripts reproduce these disposable studies; do not use these boards for fabrication.

## Remaining layout and circuit work

U3 is about 52 mm south of the module pads. A complete trunk still needs routing around ground stitches and existing back-layer debug/reset/PMIC interrupt traces. The local breakout is proven; end-to-end clearance, exact length, pull-up placement, and FDC fanout are not yet proven. Use outer-layer routing while retaining the inner ground planes, and keep away from the converter switching node and sensitive FDC input traces.

Disconnect only the FDC branch from the main bus. Current front-copper spurs are:

- SDA: (68.175, 102.20) → (70.00, 104.025) → U3.10 (70.00, 104.91).
- SCL: (68.825, 101.80) → (70.402, 103.377) → (70.402, 104.812) → U3.9 (70.50, 104.91).

Retain the main bus and R22/R23 for the PMIC and SHT. Add two nominal 4.7 kΩ pull-ups to **+3V3_FDC_SW**, near U3/C26/C28, and connect the new bus exclusively to U3. Confirm final rise time at the intended 100 kHz bus rate on hardware. No isolator IC or switched-rail route up to U1 is required.

## Leakage and firmware implications

This removes the existing always-powered shared-bus pull-ups as a source of FDC back-power. It does not establish a guaranteed zero system leakage current.

1. At boot and while FDC power is off, leave both dedicated pins disconnected/high impedance, with internal pull-ups disabled.
2. Use the main bus to enable the FDC supply; wait for its required startup time, then enable the dedicated bus and configure/read the FDC.
3. Complete transfers and suspend/disconnect TWIM20 pins before turning the FDC supply off. Verify pinctrl sleep and System OFF behaviour, including error paths.
4. Update the sensor transport, currently sharing one bus context, to select TWIM20 for FDC address 0x50 and TWIM22 for PMIC/SHT, or explicitly split those contexts.
5. Measure FDC rail voltage and battery current while off, including main-bus traffic, MCU reset and wake/sleep transitions. A dedicated bus addresses the external pull-up path; residual pin/rail leakage still needs measurement.

The maintained schematic, PCB, rules and firmware were not edited for this feasibility evaluation. D8/D9 remain accepted as previously directed. The fabrication-rule review is recorded separately in ../jlc-vias-i2c-2026-09-09/README.md.

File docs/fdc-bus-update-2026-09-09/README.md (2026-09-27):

# Dedicated FDC bus — wiring and routing handoff

Implemented 2026-09-09 at the user's request. New connections are intentionally unrouted.

| Net | Module | FDC | Pull-up |
|---|---|---|---|
| /FDC_SDA | U1.22 / P1.05 | U3.10 | R36, 4.7 kΩ to +3V3_FDC_SW |
| /FDC_SCL | U1.23 / P1.04 | U3.9 | R37, 4.7 kΩ to +3V3_FDC_SW |

R36/R37 reuse the existing qualified pull-up part, UNI-ROYAL 0402WGF4701TCE / LCSC C25900, and the same 0402 footprint. Initial PCB positions are (75.0, 103.7) and (77.0, 103.7) mm. Their placement clears existing copper and courtyards; adjust to suit the final route. Both signals use the existing I2C net class.

The PMIC and SHT stay on /SDA and /SCL with R22/R23 pulled up to +3V3. Five former FDC-only branch segments were removed. No new tracks or vias were added. All other footprints, vias and zones are unchanged relative to the saved pre-change board.

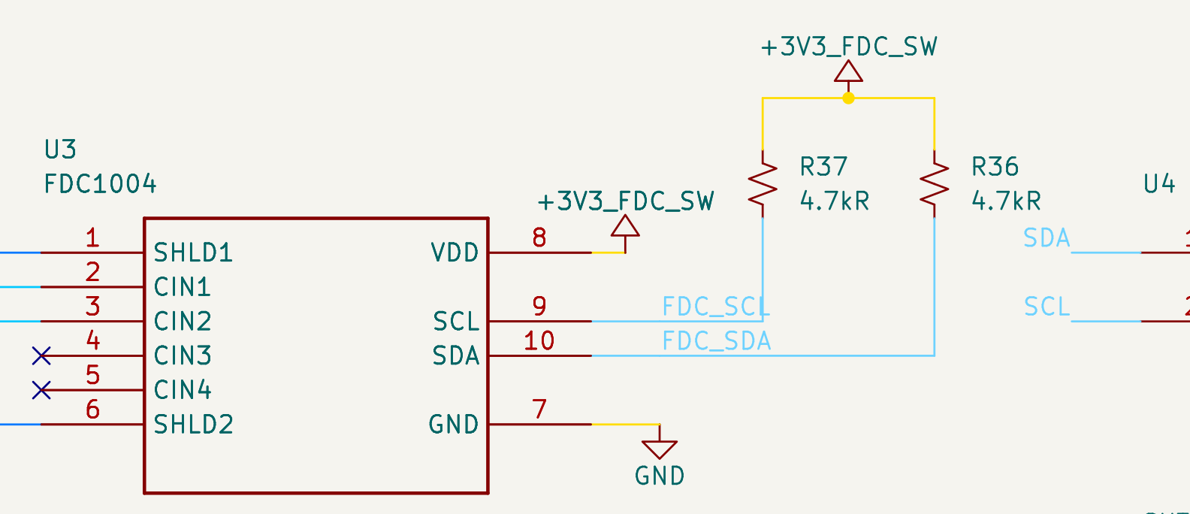
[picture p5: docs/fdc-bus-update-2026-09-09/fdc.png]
FDC schematic


## Routing notes

Six ratsnest connections remain: two connections per signal (MCU, FDC and pull-up) and two connections joining the pull-ups to the switched rail. Route these and refill zones before fabrication.

**Upward escape is an option:** leave pads 22/23 toward decreasing board Y, into the module footprint, then change layers to avoid the crystal area below the module. Verify underside clearance and the module land-pattern restrictions; keep outside the antenna keepout and retain continuous inner ground planes. This direction has been documented, not routed or DRC-qualified. The earlier downward escape was only a disposable feasibility study and has not been copied into the maintained PCB. Avoid digital traces running alongside XL1/XL2 and keep the long trunk away from /SW and the FDC CIN inputs.

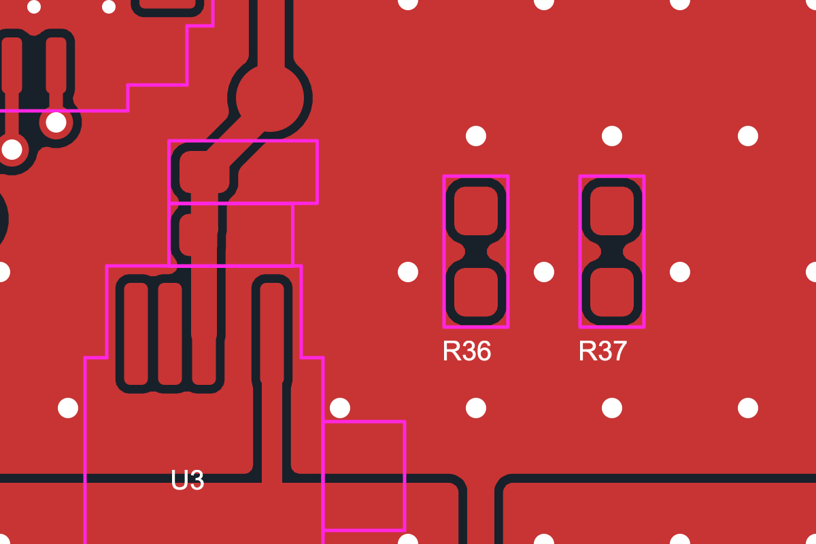
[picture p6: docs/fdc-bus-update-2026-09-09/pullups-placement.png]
Initial pull-up placement


## Firmware

The sensor qualification image uses TWIM20 for address 0x50 and TWIM22 for PMIC/SHT. SPI20 and UART20 are disabled. TWIM20 has runtime device PM enabled and starts in its sleep state; both default and sleep pinctrl explicitly disable internal bias, and sleep disconnects the pins. The SDK driver resumes for each transfer and synchronously suspends after it, including error returns. FDC transfers begin only after the existing supply-enable/settling sequence. Startup and shutdown both verify runtime PM is enabled and the bus is suspended; failure retains watchdog recovery instead of switching off beneath active pins.

Nordic SDK v3.2.2 build passed: [build log](firmware-build.log), [devicetree](firmware/zephyr.dts), [configuration](firmware/.config), [merged image](firmware/merged.hex). This image targets the updated wiring after routing; the earlier shared-bus binary is obsolete. Electrical leakage and sleep/reset transitions still require bench measurement.

## Verification

- Native schematic netlist comparison shows only the intended bus split and two new pull-ups: [exact changes](net-changes.json).
- Native schematic/PCB parity: **0 mismatches**.
- Refilled native PCB DRC: **0 physical-rule errors**, **6 intentional unrouted errors**, 91 warnings. [Report](drc.json).
- Native ERC: **0 errors, 11 warnings**. Ten concern existing C_Small library copies. One reports a no-connect/GND connection involving unchanged #PWRTP8 and an unchanged no-connect marker; it is outside the changed nets and remains for broader schematic review. [Report](erc.json).
- Sensor host tests passed for measurement, CRC, range, bounded waits and bus-fault cleanup.
- Hardware regression selection: 15 of 16 tests passed. The remaining pre-existing assertion expects SENSE clearance 0.20 mm, but the project already used 0.60 mm before this change (also captured in the previous feasibility study). That clearance was preserved. [Test log](tests.log).
- Visually checked the FDC schematic, module pin labels, and refilled copper/courtyard placement.

No fabrication outputs were regenerated. BOM and hardware/firmware/layout documentation now describe the separate bus. The before directory is an audit snapshot; its copied project settings were added after the edit to support checks and are not a pristine pre-change project-settings snapshot.

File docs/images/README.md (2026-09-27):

# PCB product render

`pcb-three-quarter.png` is a 2400 × 1800 Blender Cycles render of the maintained KiCad board, with the MCU module nearest the camera. It uses procedural solder-mask texture, metallic component finishes, three area lights, up to 96 samples, and denoising. The holder body uses white molded plastic with metallic electrical contacts. The empty battery holder is shown as exported; no battery or enclosure is synthesized.

The export includes the MCU module even though its footprint is marked DNP in the design. Including it is intentional for this assembled-board illustration. Existing component-model substitutions remain visualization approximations; see the model-source notes under `lib/footprint-sources/`. Materials and lighting are presentation choices, not measured surface properties.

PCB SHA-256: `15fb16698dda97d8ae5c5b4ddb6095a8edb0759da1a4a20add4bf374184158e5`.

## Rebuild

From the repository root, with KiCad 10 and Blender installed:

```sh
mkdir -p output/pcb-render
kicad-cli pcb export glb --force --subst-models \
  --include-pads --include-silkscreen --include-soldermask \
  --output "$PWD/output/pcb-render/board.glb" nrf-moisture-sensor.kicad_pcb
blender --background --threads 4 --python scripts/render_pcb.py
```

The script also saves an editable scene to `output/pcb-render/moisture-sensor.blend`. Use `-- --preview` for a 1200 × 900, 24-sample composition preview. Rendering is serial and limited to four CPU threads, with a 240-second sampling limit. The GLB and Blender scene remain local generated artifacts; the final PNG and rendering script are committed.

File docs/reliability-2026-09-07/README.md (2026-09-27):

# Reliability changes — 7 September 2026

The maintained PCB, schematic, BOM, assembly package and a new real-hardware qualification application have been updated. This closes concrete layout, component-selection, firmware and export issues from the [audit](../audit-2026-09-06/README.md). It does **not** establish first-pass hardware qualification: there is no assembled board available for measurement, and the actual coating, soil conductivity and final enclosure are not specified.

## Implemented

| Finding | Change | Verification / remaining limit |
|---|---|---|
| D8/D9 ESD ground paths ran through the sensing region | Each clamp now has a 0.5 mm top connection to a nearby ground via and a dedicated 0.9 mm wide In1 ground finger connected to the electronics plane. Conflicting shield stitching was removed locally. | Filled-plane regression, native DRC and visual copper inspection. The return still has finite inductance; this is not an ESD survival guarantee. |
| Marginal or unqualified reservoir selection | C21 **and** C23 now use Murata **GRM158R60J226ME01D**, 22 µF, 6.3 V, X5R, 0402, LCSC **C3894351**, the exact part listed in Nordic nwp_058 tables 6/8. | PCB/schematic/BOM agree. Nordic-reference selection is stronger evidence than nominal µF; a guaranteed bias/temperature/aging minimum is still not established. No automatic substitutions. |
| PMIC/sensor behavior existed only as requirements | Added [sensor bring-up firmware](../../firmware/sensor/README.md): real FDC1004/SHT45 reads, correct load-switch configuration, 3.3 V selection, force-HP through sensing/radio with actual-state confirmation, voltage checks, 40 mA sensor-output OCP, no heater, bounded I²C/conversion waits, automatic CAPDAC selection in single-ended mode, MCU and PMIC watchdogs, verified shutdown before System OFF. | Host conversion/fault-injection tests and complete nRF Connect SDK 3.2.2 build pass. Hardware timing, noise, power and wake behavior remain to be measured. |
| Sensor could be mistaken for the simulated DK application | New sensor-specific devicetree removes DVK peripheral conflicts, sets actual I²C pins and provisional crystal loading; raw readings go to RTT and `ProbeQA` advertises after successful measurements. | Generated devicetree/config retained. No invented soil percentage or battery SOC; calibrated BTHome integration remains future work. |
| Fiducials included in component placement export | FID1–FID4 now excluded from position files while retained as copper/mask fiducials. | Placement regression and exact BOM/CPL reference match. |
| Stale Gerbers could enter a new archive | Exporter now selects exactly the 13 required current-board files rather than every matching extension in a reused directory. | Regression includes a complete stale board set and a missing required file. |
| Documentation described backing shield absent from actual copper | Corrected LAYOUT.md, capacitor BOM and hardware status. | Current layers have no shield directly below either electrode on any lower layer. |

The two ground fingers add **8.721 mm²** of F.Cu shield / In1 GND projected overlap and **8.902 mm²** of In2 shield / In1 GND overlap. Using εr=4.2 and the 0.0994/1.265 mm dielectric gaps gives approximately **3.5 pF combined**, before fringing. Do not double-count bottom shield behind In2 as another independent parallel plate.

[Four copper layers](layers.png) · [ESD return detail](layers/nrf-moisture-sensor-GND-detail.png) · [schematic](schematic.png) · [assembly rendering](assembled.png). The battery-holder model remains a substitute, so rendering cannot certify the actual holder/enclosure fit.

## What simulation established—and did not

[Simulation inputs and reproduction instructions](../../simulation/README.md) · [plots](simulation.png) · [probe sweep CSV](probe-sweep.csv).

**openEMS:** Both source-return fixture runs reached −40 dB energy decay. At 200/300/500 MHz the baseline apparent inductance is 8.19/8.46/8.30 nH and the revised fixture is 6.29/6.24/6.10 nH. These are fixture values, including the artificial reference conductor. There is no mesh-convergence proof, and the baseline port extraction becomes non-passive near the high-frequency limit. The numerical result supports investigation of the shorter path; it does not quantify immunity improvement. Do not infer IC pin voltage or IEC pass levels from it.

**Probe electrostatics:** A separate 2-D finite-volume solver, checked against an analytical parallel-plate problem, gives approximately 0.45–14.6 pF across the lossless cases with a 30 mm outer ground boundary. A finer mesh changes estimates by up to 9.5%; moving that boundary changes them by up to 24.6%. End effects and soil conductivity are absent. The range is not evidence that a wet/saline probe will remain within the FDC range.

**Conductive-soil case:** Current exposed front/back SHLD zone area is approximately 546 + 595 = **1,141 mm²**. If both faces see grounded conducting material through a uniform coating, `C ≈ ε₀ εr A / t`. This deliberately strong coupling case gives:

| Minimum coating thickness | Shield coupling at εr=3 | Shield coupling at εr=4 |
|---|---:|---:|
| 0.05 mm | 606 pF | 808 pF |
| 0.10 mm | 303 pF | 404 pF |
| 0.25 mm | 121 pF | 162 pF |
| 0.50 mm | 61 pF | 81 pF |

These estimates omit edge fringing and other loads. At εr=4, a single 480 mm² sense face through 0.10 mm coating is about **170 pF**, beyond the nominal CAPDAC plus measurement range. At 0.25 mm it is about **68 pF**, before other coupling. This is why coating is part of the electrical design.

A useful **provisional process target is ≥0.25 mm actual cured thickness**, with a known low-water-absorption material whose wet permittivity remains ≤4, covering faces, edges and probe test points. It is not a guaranteed specification: verify thickness after cure, adhesion, abrasion, voids, water uptake and the assembled electrical load. Do not coat the SHT45 membrane. If the material/process cannot sustain these assumptions, change electrode/guard area or coating thickness before treating the design as qualified.

The integrated BL54L15 antenna lacks an available conductive geometry/feed/material model here. A STEP visualization is not an antenna model. openEMS cannot honestly supply its enclosed S11/efficiency from the supplied files.

## Still open before calling this a reliable field design

1. **Exposed SHLD protection:** D10's TVS clamp voltage is above FDC1004 pin limits, with no shield series limiter. Existing CIN resistors also need transfer-function and ESD testing. Adding an arbitrary diode/resistor can load or destabilize the driven shield; no unverified replacement was fitted. Test both polarities and powered-on/off conditions with the actual coating.
2. **FDC powered-off I²C leakage:** SDA/SCL remain pulled to the always-on rail. Absolute maximum pin tolerance does not prove low leakage with VDD=0. Measure the off rail/current; add a qualified isolation arrangement if it back-powers. Firmware shutdown alone cannot establish this.
3. **Radio supply:** HP scheduling is implemented, but measure at U1 during TX and sensor switching against Ezurio's 10 mV supply-noise requirement. C3/C25/C27 plus the module must remain within the PMIC's output capacitance window. Reservoir DC-bias verification and output-load stability are not replaced by the PMIC ADC.
4. **Battery fault protection:** Q1 handles reverse insertion; there is still no battery fuse, rechargeable-cell OVP or whole-board cutoff. The new LDOSW current limit covers only FDC power. A fuse that cannot trip from a CR2032 is not useful protection. Use the specified primary cell and validate short/fault behavior with the chosen cell. J4 is voltage reference, not an authorized supply input with a coin cell fitted.
5. **Mechanics/RF:** Check the actual battery holder, lid, screws and wet probe against antenna clearances; use strain relief at the probe shoulder and verify seals. Measure OTA performance on low/mid/high channels with the closed enclosure. Retain solid electronics ground planes; no ground bead or common-mode choke was added because the present design has no external differential cable requiring one.
6. **Calibration and aging:** Characterize raw C and CAPDAC transitions, dry/wet/saline media, coating absorption and temperature. The current qualification image does not implement calibrated BTHome moisture reporting.

## Verification and deliverables

- Native KiCad **10.99.0-3619-g0ef48b972f**: zero DRC errors, zero unconnected items, zero schematic-parity issues; zero ERC errors. Ten library-geometry DRC warnings and ten library-symbol ERC warnings remain. Existing ignored rule categories are recorded in the JSON; a clean check is not product certification.
- Repository tests, host firmware tests (including undefined-behavior sanitizer) and the electrostatic analytical check pass. Firmware builds to **84,608 bytes flash / 21,624 bytes RAM**.
- [Flashable qualification image](firmware/sensor.hex), generated [devicetree](firmware/zephyr.dts), configuration and build log retained. No board was flashed or physically tested.
- Refreshed [JLC quote package](../../production/jlc-economic-quote/QUOTE.md): 36 fitted components, 20 BOM groups, matching CPL, 13-file Gerber ZIP, schematic and source hashes. U1 remains separately sourced/hand fitted and absent from JLC BOM/CPL/paste. No order has been placed.

For the first assembly, record battery-equivalent current-limited startup, U1 supply ripple, FDC off-state leakage, watchdog recovery from a stuck bus, repeated independent one-minute wakes, and raw capacitance/shield behavior across the intended environments. Perform ESD and RF checks with the final mechanics. These measurements are the remaining evidence needed to turn a plausible first revision into a dependable sensor.

## Primary references

- [Nordic nPM2100 datasheet and design resources](https://www.nordicsemi.com/Products/nPM2100/Documentation); local nwp_058 hardware design guidelines tables 6/8 for the reservoir selection.
- [Murata exact capacitor reference specification](https://search.murata.co.jp/Ceramy/image/img/A01X/G101/ENG/GRM158R60J226ME01-01A.pdf).
- [TI FDC1004 datasheet](https://www.ti.com/lit/ds/symlink/fdc1004.pdf), single-ended/CAPDAC configuration, pin limits and 400 pF shield limit.
- [Sensirion SHT4x datasheet](https://sensirion.com/resource/datasheet/sht4x), conversion/CRC and heater commands.
- [Ezurio BL54L10/BL54L15 datasheet](https://www.ezurio.com/documentation/datasheet-bl54l10-and-bl54l15-series), supply and antenna integration.
- [Nordic nPM2100 timer](https://docs.nordicsemi.com/r/bundle/ps_npm2100/page/chapters/core_components/timer/doc/frontpage.html), watchdog versus sleep-mode behavior.

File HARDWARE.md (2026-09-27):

> 2026-09-09: D8/D9 clamp the protected CIN nets after R30/R31. Both electrodes now occupy all four copper layers, with all-layer SHLD rings closed at the tip. See [probe revision and electrical limits](docs/probe-review-2026-09-09/README.md).

> 2026-09-07: C21/C23 use GRM158R60J226ME01D; D8/D9 have dedicated In1 ground returns. Real board qualification firmware is in `firmware/sensor`. See [implemented reliability changes](docs/reliability-2026-09-07/README.md) for current limits and required measurements.

# nRF Moisture Sensor — Hardware Design

Ezurio BL54L15 453-00001R · nPM2100 (QFN16) · FDC1004 · SHT40 · BTHome v2 over BLE · CR2032

All values below are cited from the source that was checked. Anything marked
**[assumed]** has not been verified and needs your sign-off.

**Revision note.** The requirements changed: this is now board 1 of a two-board
system, a moisture sensor powered by a single user-replaceable CR2032, with
the data emitted as BTHome over BLE. The primary-cell nPM2100 architecture is
the production design; USB-C input, solar input and the rechargeable pack are
deleted from this board. The superseded charging analysis is retained only in
git history for the separate pump-controller board.

---

## 1. Power tree

```
CR2032 ──► Q1 reverse PMOS ──► nPM2100 VBAT ──► BOOST ──► VINT ──► VOUT 3.3 V ─┬─► BL54L15
                                   (SW/L1)                ├─► SHT40 (always on)
                                                          └─► I²C pull-ups (always on)
                    VINT ──► LDOSW ──► +3V3_FDC_SW ──► FDC1004 (gated)
```

One primary cell, no charging path; Q1 provides reverse-polarity protection (§3). The entire
input section of the old design — USB-C, solar pre-regulator and diode, rechargeable
pack, NTC — is deleted with the architecture change.

**VOUT = 3.3 V is a firmware write, not a strap.** The VSET pin selects only the
*startup* voltage: not connected = 3.0 V, grounded = 1.8 V (PS §6.1.1). It is
left not connected. On battery insertion the board comes up at 3.0 V — exactly
the FDC1004's minimum, which is harmless because the FDC1004 is gated off at
that moment (LDOSW defaults OFF) — and firmware then writes `BOOST.VOUT` +
`BOOST.VOUTSEL` to raise the rail to 3.3 V. Registers survive Hibernate (PS
§7.4: "Register content remains") and the SoC's System OFF (the PMIC never
sleeps), so this is one write per battery insertion, not per wake. It must be
redone after a Hibernate_PT wake or a watchdog power cycle, both of which reset
the PMIC.

**There is no OTP.** The nPM2100 has no factory-programmed
configuration option (PS §10.5 lists only package/build variants), so runtime
configuration is mandatory and the battery-insert boot path must configure the
PMIC in a known sequence before any rail-dependent peripheral is enabled.

**Pass-through never engages.** BOOST enters pass-through only when VBAT is
≥ 100 mV above the target VOUT (PS §6.1.2) — 3.4 V at a 3.3 V target, which a
CR2032 never reaches (2.0–3.3 V over its discharge, ngl_002 Table 1). The
converter regulates at every state of charge, so VOUT accuracy is identical
throughout the discharge.

**Boost mode is Auto.** ULP at our µA-level sleep load (IQULP 300 nA typ),
LP/HP as load rises, all automatic (PS §6.1.2, Figure 4). Forced High Power is
applied transiently around each capacitance measurement — see §5, where the
LP/ULP ripple injects ~0.95 fF of error through the FDC1004's PSRR. Forcing HP
costs 7.2 mA for ~20 ms, ≈ 0.35 mAh/yr.

**VINT carries no external load** (PS Table 22: "No external load is allowed")
— it exists for the boost output capacitor and feeds LDOSW internally. Bulk
capacitance belongs on VINT, not VOUT (nwp_058 §3.2), and CVOUT is capped at
15 µF effective (PS Table 10).

---

## 2. Ezurio BL54L15 module and external support

U1 is **453-00001R**, the 14 × 10 mm PCB-antenna BL54L15. The µ module
and MHF4 external-antenna variants are not substitutes. The verified 39-pad
symbol, footprint coordinates, all-layer keepouts and assembly plan are in
[the integration record](docs/bl54l15/README.md).

The module integrates the nRF54L15, its DC/DC inductor/filter and internal-rail
decoupling, 32 MHz crystal, RF matching and PCB antenna. The oscillator load
banks are inside the SoC and still require firmware configuration. No host
DCC/DECD/DECA/DECRF, XC1/XC2 or RF feed is exposed.

| Ref | External support retained | Connections |
|---|---|---|
| C3 | 10 µF nominal, 25 V X5R, standard 0603 (C96446) | U1.26 VDD_nRF to GND |
| X1 | CM8V-T1A, 32.768 kHz, CL 7 pF, ±20 ppm | U1.25 XL1 → X1.1; U1.24 XL2 → X1.2 |
| R1 / C13 | 1 kΩ series reset / 3.9 pF C0G filter, standard 0402 | SWD_RST → R1 → NRESET; C13 to GND; U1.7 NRESET |
| R22 / R23 | Existing 4.7 kΩ I²C pull-ups | SDA / SCL to VOUT |
| J4 | Existing Tag-Connect programming contacts | SWDIO, SWDCLK, reset, SWO, VDD, GND |

X1 is retained for timed System OFF/GRTC wake. No discrete crystal load
capacitors are fitted. **The old claim that the firmware capacitance parameter
is simply the crystal's 7 pF CL is superseded:** current Nordic guidance defines
it as the internal capacitor value. Select internal loading, calculate the
series-equivalent load including module/host parasitics, and measure startup
and frequency. A 12 pF bank target is an initial estimate for 2 pF additional
capacitance per leg, not a validated trim. See
[firmware port notes](firmware/BL54L15-port.md). The old X2 load value must not
carry over to the module's integrated HFXO.

**Supply qualification is open.** Ezurio specifies at most 10 mV ripple/noise
for undisturbed radio operation. nPM2100 LP/ULP ripple is typically 70 mVpp;
force HP for radio activity as well as FDC measurements and measure at U1.26.
HP mode alone is not proof of compliance. At nominal values, directly attached
host VOUT capacitors total 12.3 µF (C3+C25+C27), before module input capacitance;
verify the nPM2100's 0.7–15 µF effective VOUT range over bias/tolerance including
the module. Do not add bulk capacitance indiscriminately. Include the switched FDC rail
capacitance when assessing the enabled load-switch state. Keep the existing
3.3 V architecture; prototype validation may identify a required supply-filter
change. This layout is a routing handoff, not a fabrication release.

---

## 3. PMIC — nPM2100

**Package: QFN16 4×4 mm, part `nPM2100-QEAA`.** Not the WLCSP — that variant
is sensitive to visible and near-IR light (PS §5.2) and its GPIO0/SYSGDEN pins
cannot be routed without microvias on our stackup (nwp_058 §4.1). QFN16 also
has the better thermal path (R_θJA 40 °C/W vs 58 °C/W, PS Tables 8–9), which
matters little at our dissipation but costs nothing. Order code
`nPM2100-QEAA-R7`, MOQ 1500 from Nordic (PS Table 38) or singles from a
distributor.

The design follows Nordic's **reference circuit Configuration 2 — the CR2032
case** (PS §9.3.2): VSET not connected, CVINT 22 µF, LDOSW fed off VINT. One
deliberate deviation: Nordic's configuration runs LDOSW as an LDO at reduced
voltage; we run it as a **load switch passing the boost rail** to +3V3_FDC_SW,
because the FDC1004 wants 3.3 V, not ≤ 3.0 V (§5).

### Pinout — verified against PS Table 22 (QFN16)

| Pin | Name | Net | Notes |
|---|---|---|---|
| 1 | VSET | — (NC) | internal pull-up to VINT; NC = 3.0 V startup. No strap resistor |
| 2 | SW | /SW | boost switch node → L10 |
| 3 | VBAT | /VBAT | from the CR2032 holder |
| 4 | SHPHLD | — (NC) | ship/wake button input; unused — see below |
| 5 | GPIO0 | /PMIC_INT | event interrupt output → nRF P0.00 (§6) |
| 6 | SDA | /SDA | TWI data, external pull-up to VOUT |
| 7 | SCL | /SCL | TWI clock, external pull-up to VOUT |
| 8 | SYSGDEN | GND | grounded: boot monitor disabled at startup |
| 9 | GPIO1 | — (NC) | spare: boost-force / LDOSW pin-control option |
| 10 | PG/RESET | /SWD_RST | open-drain, internal pull-up to VINT; watchdog host-reset output — joins the nRF RESET net |
| 11 | AVSS2 | GND | |
| 12 | LSOUT/VOUTLDO | /+3V3_FDC_SW | load switch output → FDC1004 |
| 13 | VOUT | /+3V3 | boost output for the load |
| 14, 15 | VINT | /VINT | boost decoupling only — no external load |
| 16 | PVSS | GND | power ground, boost return |
| EP | AVSS1 | GND | |

**SHPHLD stays unconnected.** Ship mode (35 nA) exists for factory storage with
the cell installed; this product ships without a cell, and battery removal is
the off switch. The pin may be left NC (PS Table 22), and its absolute maximum
is only **1.9 V** (PS Table 5) — nothing on this board may ever touch it. If a
user button is wanted later, it is a button to ground on this pin (2 s press =
ship, press = wake, 10 s = reset, PS Table 17) and costs one enclosure hole.

**PG/RESET joins the nRF RESET net.** It is open-drain with an internal pull-up
to VINT (PS Table 22) — wired-OR compatible with the R1/C13 filter and the SWD
connector already on that net (§2, §6). This lets the PMIC watchdog issue a host
reset, or in power-cycle mode reset the SoC *and* the PMIC — a stronger recovery
path than the SoC's own watchdog for a device that cold-boots hourly with the
radio up.

### Configuration

| Function | Setting | Notes |
|---|---|---|
| BOOST VOUT | 3.3 V, TWI-set after startup | VSET NC gives 3.0 V at cold start; see §1 |
| BOOST mode | Auto (ULP/LP/HP/PT automatic) | forced HP around conversion and all radio activity — §§2,5 |
| LDOSW | **Load switch**, TWI-enabled per wake | OFF by default (PS §6.2); active discharge built in |
| Watchdog | configurable: host reset or power cycle | covers hangs the SoC's own WDT cannot see |
| Boot monitor | disabled — SYSGDEN grounded | otherwise arms 10 s after every timer wake (PS §7.2.3) and must be stopped in software; the configurable watchdog replaces it |
| Ship / Break-to-wake | unused | battery-out is the off switch |
| TWI | address 0x74, 100 kHz–1 MHz | pull-ups to VOUT (PS §7.6) |

### Support components — PS §9.3.2 (Configuration 2) and nwp_058 §3

| Des | Value | Description | FP | Net |
|---|---|---|---|---|
| U2 | nPM2100-QEAA | PMIC | QFN16 4×4 | — |
| L10 | Murata DFE201210U-2R2M=P2, 2.2 µH | **I_sat 2 A, DCR 228 mΩ max, ±20%** — no other inductance permitted (nwp_058 §3.1) | 2.00 × 1.20 mm | SW (2) → protected VBAT (3) |
| C21 | 22 µF | X5R 6.3 V ±20% | 0402 | VBAT (3) |
| C22 | 1 nF | X7R 50 V, FH 0402B102K500NT | standard 0402 | VBAT (3) |
| C23 | 22 µF | X5R 6.3 V ±20% | 0402 | VINT (14/15) |
| C24 | 1 nF | X7R 50 V, FH 0402B102K500NT | standard 0402 | VINT |
| C25 | 2.2 µF | X5R 6.3 V ±20% | 0402 | VOUT (13) |
| C26 | 1 µF | local decoupling at the FDC1004 | 0402 | +3V3_FDC_SW (12) |

Capacitor notes, from nwp_058 §3.2–3.4 and PS Table 10:

- **Effective capacitance is what matters.** CVBAT and CVINT each need
  ≥ 3.5 µF *effective*, CVOUT 0.7–15 µF effective, after DC bias, tolerance and
  temperature. A 10 µF 0402 X5R at 3 V bias is not 10 µF — check the derating
  curve for the specific part ordered.
- **The 1 nF caps are the RF decoupling** Nordic specifies for RF-sensitive
  applications (nwp_058 §3.2/§3.3). This board has a 2.4 GHz radio and a 25 kHz
  capacitive front end; both are fitted.
- **C26 on +3V3_FDC_SW:** load-switch mode needs no output capacitor for the switch
  itself (nwp_058 §3.4), but the FDC1004 still gets local decoupling. 1 µF was
  already the value on the old gated rail (§5); the hourly recharge cost is
  negligible.
- **The inductor is not a free choice.** 2.2 µH ±20% only — other values break
  the control loop (nwp_058 §3.1). Inductor peak current in hysteretic ULP/LP is
  typ. 150 mA with startup transients above that, hence the 550 mA I_sat floor.
  Candidates with measured efficiency on the EK (nwp_058 Tables 4–5, VBAT
  2.9 V → VOUT 3.3 V): **Murata DFE201210U-2R2M=P2** (2012, 91.9% at 100 µA,
  94.7% at 120 mA), TDK MLP2016H2R2MT0S1 (2016, 91.5%/95.0%).
  The Murata part is locked. Its board footprint uses two 0.55 × 1.20 mm pads
  on 1.45 mm centres, a 0.90 mm inner gap, and a 2.70 × 1.90 mm courtyard.

### Cold start, EOL pulses, and the reservoir question

Cold start requires the battery to supply **≥ 10 mA typ during startup** (PS
Table 4) — trivial for a fresh CR2032 (10–25 Ω ESR), marginal at end of life
where ESR rises steeply at the knee (ngl_002 Table 1: CR2032 ESR 10–80 Ω over
the discharge). Two consequences:

1. **The TX pulse rides on CVBAT.** Nordic's own CR2032 BLE test (nwp_058 §3.5)
   measured **+11.6% battery life from 100 µF added at VBAT** and +17.9% from
   100 µF at both VBAT and VINT — input-side capacitance cuts the I²·R ESR loss
   during pulses. The reference circuit ships 10 µF + 1 nF at VBAT; the 100 µF
   upgrade is a bring-up measurement to make, not a default to fit. Leave a
   footprint for it if placement allows.
2. **A deeply discharged cell may fail to restart.** VBATCOLD_START is 0.8 V
   *loaded*. The ADC's VOUT droop detector plus the fuel gauge's low-SoC output
   give firmware the signal to degrade gracefully — shorter wakes, then stop
   advertising — rather than brown-out looping at the cell's knee.

### Reverse battery and ESD — implemented 2026-09-04

The former accepted reverse-insertion risk is superseded by Q1 (DMG2305UX-7).
Drain pin 3 connects to raw BT1 positive, source pin 2 to VBAT, gate pin 1 to GND.
C21/C22 remain on protected VBAT. D1/D2 clamp raw/protected battery inputs;
D3–D7 protect the programming interface; D8–D10 cover sense/shield connections.
R30/R31 add 5.1 kohm sense-input isolation and R32–R35 add 100 ohm debug isolation.
See [protection implementation and qualification limits](docs/protection/README.md).

BT1 is Lian Xin CR2032-BS-6, LCSC C22363833, with positive pad 1 on the left
and negative pad 2 on the right in the footprint's unrotated top view. D1 is
on F.Cu beside the positive contact. The part-specific stepped courtyard
preserves at least 0.25 mm body clearance; Q1 clears that courtyard. No PTC or sustained-OVP
cutoff is fitted. Prototype ESD, leakage, cold-start and sensing validation are
still required. A single PMOS is not guaranteed reverse-current isolation from
an externally powered rail into the primary cell; J4 remains a voltage reference.

### Hibernate vs System OFF — the wake architecture

The nPM2100 can own the wake cycle itself: Hibernate mode (boost holds VINT,
VOUT discharged, LDOSW optionally alive) draws **320 nA typ with the timer
running** at VINT = 1.8 V (PS Table 4; 175 nA in Hibernate_PT), and the wakeup
timer spans up to **3 days** at ±3% typ accuracy (PS Table 16) — an hourly cycle
fits in one shot.

This design keeps the **SoC System OFF + GRTC wake** architecture:

| | System OFF + GRTC (chosen) | PMIC Hibernate timer |
|---|---|---|
| Battery draw between wakes | ~1.5 µA (nRF SO + GRTC/LFXO, PMIC 300 nA, SHT40 80 nA) | 320 nA typ, PMIC only |
| Wake timing accuracy | ±20 ppm (LFXO) | ±3% typ, ±20% over temperature |
| Fuel gauge state | survives in retained RAM | lost with VOUT — persist to RRAM/flash every wake (nan_048 §4.1) |
| PMIC configuration | written once per battery insert | re-written after every Hibernate_PT wake |
| Firmware | already implemented and DK-verified | same cold-boot model, new driver path |

The ~1.2 µA difference is ~10 mAh/yr on a budget where the cell's own shelf
life binds first (§7) — not worth re-architecting a working, verified wake path,
and the fuel-gauge state persistence tips it further (nan_048 §4.1:
reinitializing from scratch each wake degrades accuracy). The hibernate path
stays available in firmware at any time with zero schematic changes; it is the
fallback if the measured sleep current disagrees with the budget.

---

## 4. Solar input — deleted with the architecture change

This board is coin-cell powered now. The solar branch (Voltaic P126 panel,
TPS7A1650 pre-regulator, D5, J3) and the USB-C input belong to the charging
architecture this board no longer has.

Board 2 — the pump controller, which is battery *or* mains powered — inherits
all of it. The superseded analysis (panel selection, pre-regulator comparison,
the barrel-jack placement argument, the 100 mA VBUS current-limit firmware
dance) is preserved in this file's git history at commit 1753c18, alongside
the archived charging-design datasheets. Do not carry any of it forward into
this board's BOM or layout.

## 5. Sense front end — FDC1004
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

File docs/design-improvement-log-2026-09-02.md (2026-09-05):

# PCB design improvement log — 2026-09-02

This is the working review and implementation log for the CR2032 + nPM2100
revision. The older `audit-2026-07-31.md` describes the retired
nPM1300/rechargeable/solar layout and is retained only as design history.

## Working rules

- Make small, reviewable batches and run ERC/DRC after each batch.
- Lock exact orderable parts before final placement and routing.
- Use the matching Nordic nRF54L15 reference revision for the selected silicon.
- Do not waive electrical or clearance errors that can be fixed at the source.
- Preserve a solid In1.Cu ground plane; keep switching and sensing loops local.
- Validate RF, capacitance, temperature, and battery behavior in the final
  enclosure with the production coating and mechanical stack.
- Production assembly will use PCBA; 0201 passives are acceptable. Prefer the
  Nordic reference packages wherever they improve RF or decoupling geometry.

## Current baseline

- [x] Synchronize schematic and PCB for the nPM2100/CR2032 architecture.
- [x] Remove obsolete nPM1300, solar, USB, and rechargeable-power footprints from the PCB.
- [x] Remove obsolete routing, vias, and power-section copper left by the update.
- [x] Resolve all schematic/PCB parity errors before detailed placement work.
- [x] Resolve ERC errors in the custom nPM2100 symbol and PG/RESET circuitry.
- [x] Re-run ERC and DRC and record the new baseline below.

Baseline observed before implementation:

- ERC: 23 violations, including 2 electrical errors and 21 library mismatches.
- DRC after zone refill: 38 violations and 43 unconnected items.
- Schematic/PCB parity: 85 issues.

Baseline after schematic/PCB synchronization:
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

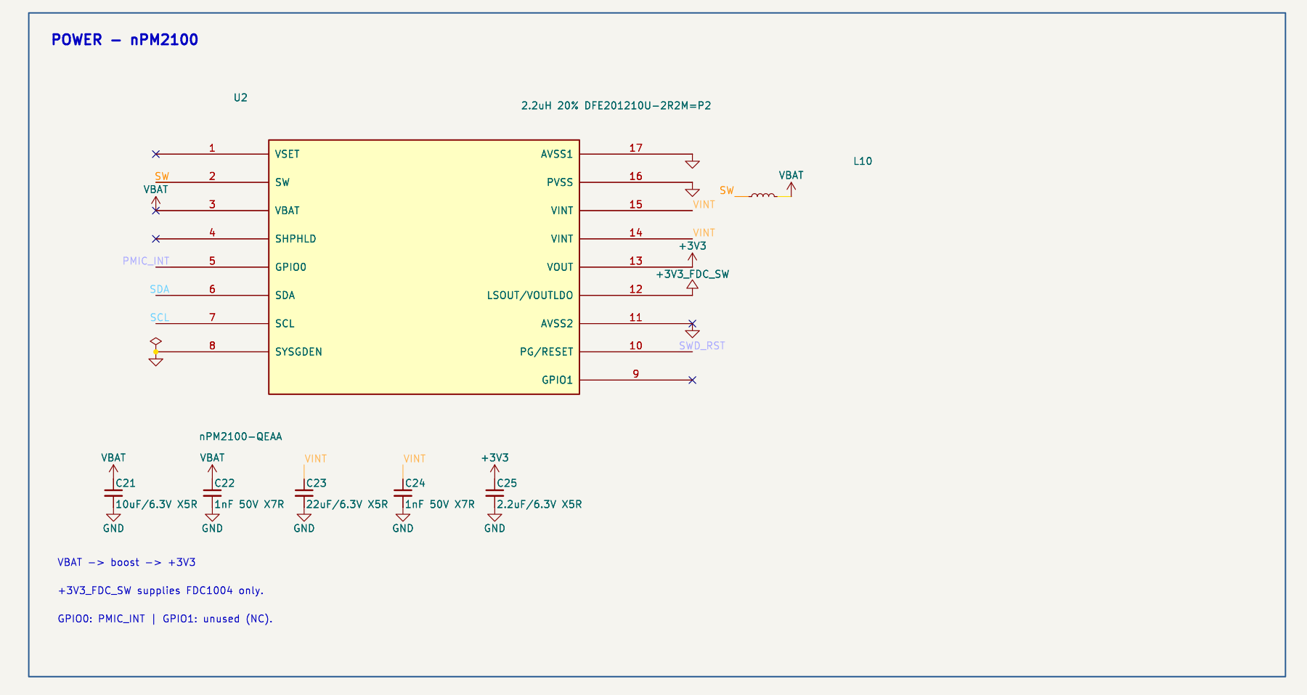
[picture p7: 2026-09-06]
docs/schematic-review-2026-09-05/after/power.png

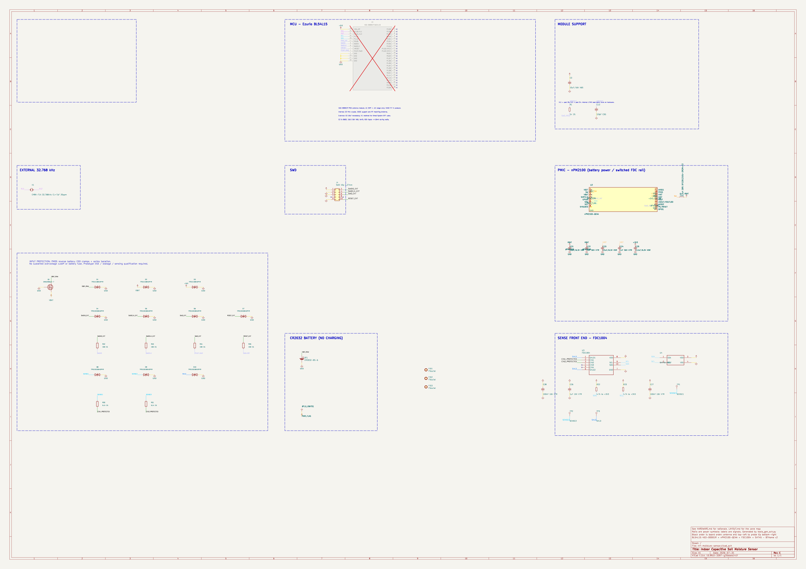
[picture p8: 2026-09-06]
docs/schematic-review-2026-09-05/before/overview.png

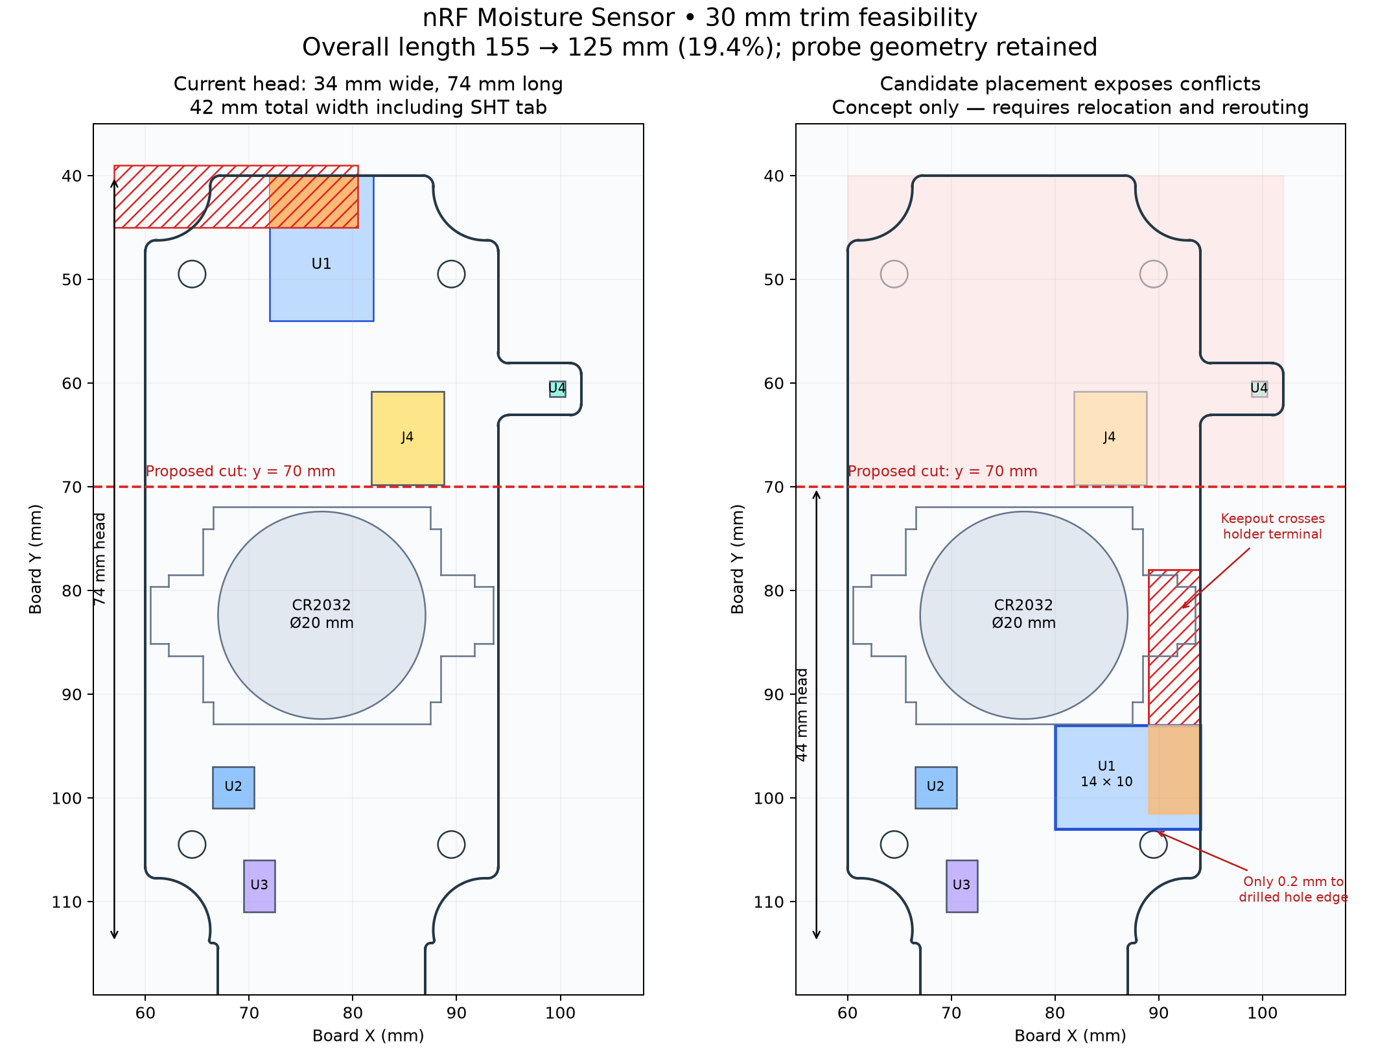
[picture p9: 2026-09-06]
docs/design-review-2026-09-05/shrink-concept.png

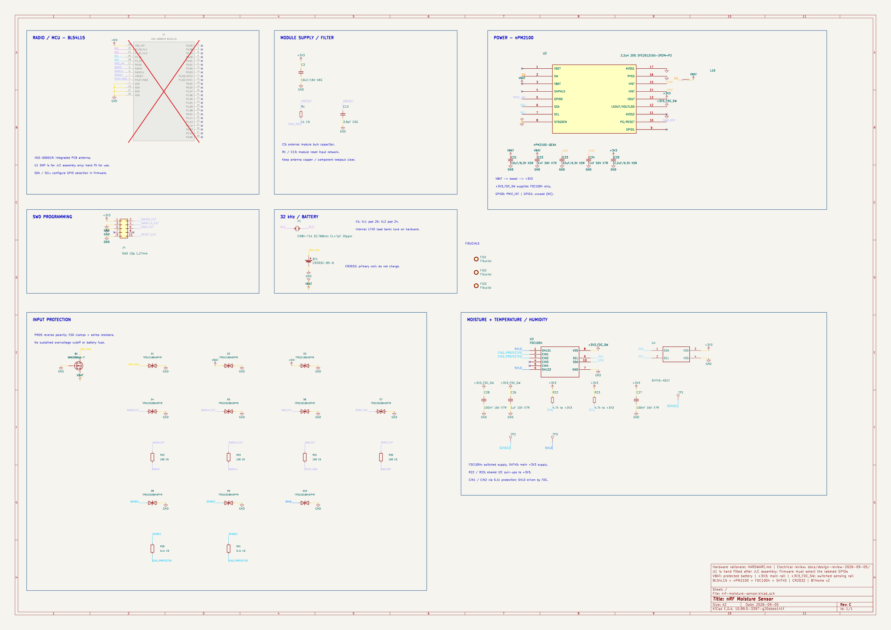
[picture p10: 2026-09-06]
docs/schematic-review-2026-09-05/after/overview.png

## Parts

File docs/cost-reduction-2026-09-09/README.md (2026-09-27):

# Cost reduction — 9 September 2026

The user accepted SHT40 as the reference sensor and requested implementation
of the cost recommendations. The starting ten-board quote is $33.00 PCB plus
$191.37 assembly = $224.37, excluding BLE, shipping and tax. Components are
$138.55 and Extended feeder fees are $39.91.

## Implemented selections

| Ref | Previous | Selected | Reason |
| --- | --- | --- | --- |
| Q1 | DMG2305UX-7 / C150470 | Diodes DMG2305UX-13 / C144153 | Same device and SOT-23 footprint; 10,000-piece reel instead of 3,000-piece reel. JLC purchases individual quantities. |
| U4 | SHT45-AD1F-R2 / C5360602 | Sensirion SHT40-AD1F-R2 / C7461846 | Lower accuracy accepted for reference use; retains integrated membrane, 0x44 address, pinout and footprint. |
| C3 | CL10X106MO8NRNC / C3039688 | Samsung CL10A106MA8NRNC / C96446 | Basic part removes one feeder fee; retains nominal 10 µF and 0603 footprint. |
| R22/R23/R36/R37 | Two different value strings, same C25900 | Common value `4.7k 1%`, same C25900 | One unambiguous BOM row with all four references. Supply nets remain separate. |

Values, MPNs and LCSC fields are synchronized in the schematic and PCB.
The export now labels the procurement column `JLCPCB Part #` to avoid relying
on automatic matching. All 38 JLC-fitted references are present in 20 BOM rows.
U1 remains DNP for separate BLE-module fitting. BT1 remains factory assembled.

## Electrical and mechanical checks

**Q1:** The [Diodes ordering table](https://www.diodes.com/datasheet/download/DMG2305UX.pdf)
lists both suffixes against the same electrical specifications and package.
The existing reverse-battery topology and low-voltage RDS(on) rating remain.

**U4:** [Sensirion SHT4x v7.3](https://sensirion.com/resource/datasheet/sht4x)
gives SDA=1, SCL=2, VDD=3, VSS=4 for both accuracy variants. The membrane
package and land pattern are shared. The existing SHT45-named STEP model
is retained as the same package geometry, not a new procurement selection.
The no-central-pad footprint, copper keepout and assembly orientation stay intact.
The current datasheet describes the filter as polyimide; older product pages
call it PTFE. Select the exact Sensirion AD1F ordering code in either case.

Typical reference accuracy becomes ±0.2 °C / ±1.8 %RH under the specified
conditions. If using the earlier illustrative 20–60 fF/°C soil coefficient,
temperature-sensor uncertainty becomes 4–12 fF, versus 2–6 fF with SHT45.
This is not a calibrated system specification. Ambient-to-soil temperature
differences and enclosure effects must be assessed on the prototype.
The existing firmware uses 0x44, command 0xFD, a 10 ms wait and the common
SHT4x CRC/conversion algorithm. No firmware protocol change is required.

**C3:** The [Samsung part page](https://product.samsungsem.com/mlcc/CL10A106MA8NRN.do)
identifies CL10A106MA8NRNC as 10 µF, ±20%, 25 V, 0603, X5R (−55…+85 °C).
The higher voltage rating alone is not evidence of better capacitance retention.
The exact manufacturer DC-bias curve was extracted and interpolated:

| Part | Typical capacitance at 3.0 V | At 3.3 V | At 3.6 V |
| --- | ---: | ---: | ---: |
| New C3, CL10A106MA8NRNC | 7.01 µF | 6.60 µF | 6.21 µF |

Previous C3 is approximately 6.85 µF at 3.3 V, so the new part has about
3.6% less typical capacitance at this operating point. The nominal value stays
10 µF as required by the module design. Applying −20% tolerance and −15%
temperature factors to the new part's typical 3.3 V curve gives an illustrative
4.49 µF; this is a screening estimate, not a guaranteed combined corner or
an aging-qualified lower bound. Other retained X5R parts already have an
85 °C limit. Existing module transient/ripple and PMIC total effective
0.7–15 µF output-capacitance qualification is still open; this substitution
does not establish that the entire board is qualified.

**C26 retained:** Samsung CL05A105KA5NQNC / C52923 was screened, not fitted.
Its [manufacturer curve](https://product.samsungsem.com/mlcc/CL05A105KA5NQN.do)
shows 0.576 µF typical at 3.3 V before tolerance, temperature and aging.
TI's [FDC1004 example](https://www.ti.com/lit/ds/symlink/fdc1004.pdf) pairs a
1 µF tantalum with 100 nF ceramic. This cheap candidate is not a verified
equivalent to that reservoir, so retain the existing GRM155Z71A105KE01D and
C28. This does not claim that the old capacitor has been newly qualified.
C21/C23, the inductor, crystal, and protection components are otherwise retained.

Manufacturer page HTML and extracted curve data are saved in `sources/`.
These curves are typical reference data, not production limits.

## Price estimate

Database pricing at the ten-piece tier is $6.1227 → $2.1950 per sensor and
$0.6606 → $0.3613 per Q1. C3 below 100/200 pieces is $0.1034 → $0.0552.
Using ten charged pieces of each, the component reduction is $42.752 and
one removed feeder fee adds $3.07, for approximately $45.82 saved.
Applying that delta to the user's quote gives **about $178.55 total,
$17.85 per board**, before BLE, shipping and tax. This is a comparative
estimate; actual charged quantities, attrition, price tiers and stock can
change the checkout result. Requote the exported BOM. Expected Extended
types fall from 13 to 12, with fees $39.91 → $36.84 at $3.07/type.

## Verification

- Exported netlists have identical net names and reference/pin memberships.
- Only seven footprint property blocks changed. All pads, copper, routing,
  placement, keepouts, zones, footprints and 3D transforms are preserved.
- ERC is unchanged: zero errors, 11 existing warnings.
- DRC has the same rule/severity/item identities: 38 existing warnings,
  two previously accepted +3V3-via keepout errors, zero unconnected items
  and zero schematic-parity issues. The existing export gate accepts only
  those exact two vias; no exceptions were added.
- Four existing BOM/export unit tests passed.
- Sensor host tests passed: measurements, CRC, range, bounded waits and
  bus-fault cleanup. This is not hardware validation or a new SDK build.
- Rendered schematic checked for legible changed values and unchanged wiring.

## Quote files

Use the coherent package in `production/jlc-cost-reduced/`:
`JLC-BOM.csv`, `JLC-CPL.csv`, and `JLC-Gerbers.zip`.
The PCB geometry is unchanged; this package regenerates all three from the
same sources. `Product-BOM.csv`, `schematic.pdf`, source hashes and check
reports are included. No order was submitted.

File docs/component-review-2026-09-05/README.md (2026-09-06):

# I²C and capacitor review — 2026-09-05

Reviewed the current nRF Moisture Sensor schematic using a freshly exported
[netlist](netlist.xml), and checked PCB pad net/function assignments in
[pad-audit.json](pad-audit.json). This is a design review and analytical check;
no assembled-board measurement or converter transistor-level simulation was run.

## I²C pin assignment is correct

| Signal | Module U1 pad | nRF54L15 GPIO | Internal QFN pad | Other bus pins |
|---|---|---|---|---|
| SCL | 35 | P1.11, dedicated clock | 39 | U2.7, U3.9, U4.2, R23.2 |
| SDA | 28 | P1.10 | 38 | U2.6, U3.10, U4.1, R22.2 |

The [Ezurio pin table](https://www.ezurio.com/documentation/datasheet-bl54l10-and-bl54l15-series)
confirms this mapping. The two signals are adjacent on the silicon package;
the module redistributes them to lands 5.25 mm apart. Module pad numbering does
not define a mandatory I²C pair. No pin swap is needed.

Nordic nRF54L15 Product Specification v1.0 §8.8.3–8.8.5 (pp.276–278)
requires a peripheral-compatible port and a clock-capable clock pin. §8.23.10
(p.659) assigns TWIM20/21/22 to P1 and TWIM30 to P0. **TWIM22 with SCL=P1.11,
SDA=P1.10 satisfies these constraints.** Use separate PSEL settings for SCL and
SDA; do not use TWIM30 for this pair. Local source:
[Product Specification](../../doc/datasheets/nRF54L15.pdf).

The existing [pin test overlay](../../firmware/pin-assignment/boards/nrf54l15dk_nrf54l15_cpuapp.overlay)
sets exactly this pair on `i2c22`. [Bench records](../../firmware/README.md)
report 20/20 successful DK transactions for this configuration. Those are
historical DK results, not a test of the present module PCB. The BTHome app still
targets the DK; the [module firmware port requirements](../../firmware/BL54L15-port.md)
remain applicable. Peripheral sharing (for example TWIM20/UARTE20) must also
be considered when creating the actual board target.

R22/R23 are 4.7 kΩ. Using the first-order I²C relation
`t_r = 0.8473 R C`, 400 kHz's 300 ns rise-time limit allows about **75 pF** per
line (74.6 pF at resistor +1%); 100 kHz's 1 µs allows about **251 pF**.
These are analytical budgets, not extracted bus capacitance. Verify rise times
at the farthest device with all devices fitted. Do not add capacitors to SDA or
SCL. Power sequencing must also prevent the always-on pull-ups from back-powering
the switched-off FDC1004.

## Current capacitor inventory

This table comes from the current schematic, not the older BOM prose. All power
capacitors below return to GND.

| Ref | Actual schematic selection | Rail / function | Assessment |
|---|---|---|---|
| C3 | Samsung CL10X106MO8NRNC; 10 µF 16 V X6S, 0603, ±20% | +3V3, module input | Correct nominal host reservoir; include in total VOUT effective capacitance. |
| C13 | FH 0402CG3R9C500NT; 3.9 pF C0G, 0402 | NRESET RF filter | Not supply bypass or a millisecond reset delay. No capacitance increase indicated. |
| C21 | Samsung CL05A106MQ5NUNC; 10 µF 6.3 V X5R, 0402, ±20% | VBAT | **Marginal at fresh-cell DC bias; not qualified**, see below. |
| C22 | FH 0402B102K500NT; 1 nF 50 V X7R, 0402 | VBAT HF bypass | Within Nordic's 1–100 nF supplementary range. |
| C23 | Murata GRM155R60J226ME11D; 22 µF 6.3 V X5R, 0402, ±20% | VINT boost reservoir | Nominally reasonable; exact biased minimum still unresolved. |
| C24 | FH 0402B102K500NT; 1 nF 50 V X7R, 0402 | VINT HF bypass | Within Nordic's supplementary range. |
| C25 | Samsung CL05A225MQ5NSNC; 2.2 µF 6.3 V X5R, 0402, ±20% | +3V3, converter output | Matches recommended nominal value; check effective local capacitance and total load. |
| C26 | Murata GRM155Z71A105KE01D; 1 µF 10 V X7R, 0402, ±10% | +3V3_FDC_SW | Correct nominal value/dielectric for TI recommendation. |
| C27 | Samsung CL05B104KO5NNNC; 100 nF 16 V X7R, 0402, ±10% | +3V3, SHT45 | Appropriate local HF bypass; not an energy reservoir for heater pulses. |
| C28 | Samsung CL05B104KO5NNNC; 100 nF 16 V X7R, 0402, ±10% | +3V3_FDC_SW | Correct TI bypass paired with C26; must be closest to U3 VDD. |

At review time BOM.md still calls C26–C28 unresolved and lists obsolete 0201
parts for C22/C24/C27/C28. **Synchronize published BOM/readme prose with these
actual source selections.** The electrical fields already contain order codes.
BOM.md has now been regenerated from KiCad source fields (see the 2026-09-05 product CSV).
No part substitutions were made by this review.

## Power findings

**1. C21 lacks adequate demonstrated margin.** Nordic requires at least 3.5 µF
effective capacitance on VBAT. The exact-part
[Samsung characteristic sheet](https://media.digikey.com/pdf/Data%20Sheets/Samsung%20PDFs/CL05A106MQ5NUNC_Char.pdf)
shows approximately 60% loss around 3.2–3.3 V in its DC-bias graph. A screening
estimate gives `10 µF × 0.40 × 0.80 ≈ 3.2 µF`, below 3.5 µF. The separate
biased-temperature graph is somewhat less severe; this typical-only sheet does
not establish a guaranteed worst case. Confirm the current manufacturer model
and minimum capacitance at fresh-cell voltage, temperature and aging; otherwise
revise the input reservoir selection. A 1 nF bypass does not close a microfarad
shortfall. [Locally inspected plot](c21-characteristics.png).

**2. C23 cannot be approved from “22 µF” alone.** VINT also requires at least
3.5 µF effective. At −20% tolerance, C23 needs at least 19.9% of nominal
capacitance remaining before additional temperature/aging allowances. Obtain
its exact bias curve at actual VINT voltage (including operating modes), not a
curve from a similarly named Murata part. The schematic's part is not the exact
22 µF example printed in Nordic's application note. VINT is the preferred node
for additional output energy storage if analysis shows more is needed.

**3. Main +3V3 has an unresolved maximum-capacitance budget.** Nordic specifies
0.7–15 µF effective capacitance on VOUT. Direct external loading is
`C3 + C25 + C27 = 12.3 µF` nominal. Using listed production tolerances alone
and zero bias reduction gives **14.75 µF**; this excludes module-internal
input capacitance, temperature increases, parasitics and any attached debugger.
The FDC load-switch branch is supplied from **VINT**, explicitly stated in
nPM2100 §6.2 (p.42); C26/C28 must **not** be added directly to the VOUT
15 µF budget. Their switching load can disturb the common boost/VINT source,
so test that transient independently. The direct-VOUT arithmetic is a screening
bound, not proof of failure: real MLCC bias loss affects the result. Quantify the
module's input capacitance and full operating temperature range.
Blindly adding a large capacitor to +3V3 could violate the converter limit.

**4. Radio supply ripple needs hardware qualification.** Ezurio specifies at
most 10 mV supply noise/ripple for undisturbed radio operation and calls for
10 µF at the host supply. Nordic's nPM2100 LP/ULP typical output ripple is
70 mVpp. Hold HP through radio activity and settling, then measure at module
pad26; HP is a mitigation, not a guaranteed compliance result. This is a larger
open power issue than nominal microfarads alone.

**5. FDC bypass values match TI.** The
[TI FDC1004 datasheet](https://www.ti.com/lit/ds/symlink/fdc1004.pdf),
§7.5 in the local revision, recommends 0.1 µF and 1 µF X7R, with the smaller
capacitor nearest VDD. C28/C26 satisfy the value/dielectric requirement.
The PMIC output is used as a load switch, so the LDO-specific output-capacitor
minimum does not impose an additional capacitor here. Preserve local bypass
placement and test switched-rail start-up/back-power behavior.

**6. The SHT45 heater is a separate load case.** The local
[SHT4x v7.3 datasheet](../../doc/datasheets/sensirion-sht45/HT_DS_Datasheet_SHT4x_V7.3.pdf),
Table 4, lists highest-heater current as 60 mA typical and **100 mA maximum**;
normal measurement is at most 500 µA. Use the table's 100 mA maximum for power
budgeting, rather than the approximate 75 mA sentence later in the document.
C27 is ordinary local decoupling. At 100 mA, 100 nF supports a 10 mV drop for
only 10 ns (`dt=C·dV/I`); it cannot supply a 0.1 s heater cycle. If heater use
is intended, qualify converter and depleted/cold CR2032 behavior independently
and avoid simultaneous radio bursts. No need to enlarge C27 simply to match
the heater current.

The fitted X1 uses the SoC's internal load banks, so adding arbitrary discrete
crystal load capacitors is inappropriate. Follow the existing port calculation
and trim/start-up verification; its initial 12 pF internal-per-leg estimate is
not a measured calibration.

## Simulation and bench tests to close the findings

1. Sweep exact capacitor bias/temperature models, tolerance and aging across
   battery voltage and PMIC modes. Confirm VBAT/VINT minima, local VOUT minimum,
   and aggregate VOUT maximum. Check FDC switching transients separately on the
   VINT-derived branch. Use the actual assembled module's
   input capacitance. Typical curves provide engineering estimates, not lot limits.
2. Model CR2032 open-circuit voltage and series impedance versus temperature and
   depletion, converter response, actual routing resistance and load pulses.
   Sweep module TX/RX, FDC turn-on and 10/55/100 mA heater maxima. A behavioral
   load-step simulation can bound droop, but cannot prove converter loop stability
   or RF noise without a validated converter/module model.
3. On prototypes, use a short ground spring at module pad26 and U3/U4 supplies;
   capture startup, HP/LP transitions, radio bursts and FDC switching. Check
   radio supply noise against 10 mV and FDC supply staying within 3.0–3.6 V.
4. Verify I²C rise times, transactions and idle current with the FDC rail off/on;
   repeat at minimum battery voltage and relevant temperatures. Compare radio
   performance with the PMIC forced HP versus automatic mode.

Nordic sources for the capacitance/mode findings:
[nPM2100 Datasheet v1.0](../../doc/datasheets/nPM2100_Datasheet_v1.0.pdf),
Table 10 (pp.17–18), and
[Hardware Design Guidelines nwp_058](../../doc/datasheets/nPM2100_HW_Design_Guidelines_nwp_058.pdf),
§3.2–3.4 (pp.9–10). All manufacturer documents were read locally or retrieved
on 2026-09-05. Extracted full-document text was temporary and is not retained.

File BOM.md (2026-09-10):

> Rev A checkpoint: consolidated schematic and updated PCB match the JLC export. See [checkpoint and Rev B follow-ups](docs/rev-a-checkpoint/README.md).

# nRF Moisture Sensor — Bill of Materials

Generated from the maintained schematic on 2026-09-09 using KiCad's BOM exporter.
The [source CSV](docs/schematic-consolidation-2026-09-09/Product-BOM.csv) includes manufacturer and assembly-stage DNP fields.
This supersedes the earlier manually maintained selection table; historical selections remain in Git.

U1 is required in the finished product but marked DNP for the JLC assembly stage and fitted separately.
The CR2032 cell is not included as a schematic component. Bare PCB features are excluded from purchasing.
No stock, price, or fabrication approval is implied by this export.

| Ref | Value | Footprint | MPN | Manufacturer | LCSC | JLC DNP |
| --- | --- | --- | --- | --- | --- | --- |
| BT1 | CR2032-BS-6 | footprints:BatteryHolder_LianXin_CR2032-BS-6 | CR2032-BS-6 | Lian Xin Technology | C22363833 |  |
| C3 | 10uF/25V X5R | Capacitor_SMD:C_0603_1608Metric | CL10A106MA8NRNC | Samsung | C96446 |  |
| C21 | 10uF/25V X5R | Capacitor_SMD:C_0603_1608Metric | CL10A106MA8NRNC | Samsung | C96446 |  |
| C22 | 1nF 50V X7R | Capacitor_SMD:C_0402_1005Metric | 0402B102K500NT | FH | C1523 |  |
| C23 | 10uF/25V X5R | Capacitor_SMD:C_0603_1608Metric | CL10A106MA8NRNC | Samsung | C96446 |  |
| C24 | 1nF 50V X7R | Capacitor_SMD:C_0402_1005Metric | 0402B102K500NT | FH | C1523 |  |
| C25 | 2.2uF/6.3V X5R | Capacitor_SMD:C_0402_1005Metric | CL05A225MQ5NSNC | Samsung | C12530 |  |
| C26 | 2.2uF/6.3V X5R | Capacitor_SMD:C_0402_1005Metric | CL05A225MQ5NSNC | Samsung | C12530 |  |
| C27 | 100nF 16V X7R | Capacitor_SMD:C_0402_1005Metric | CL05B104KO5NNNC | Samsung | C1525 |  |
| C28 | 100nF 16V X7R | Capacitor_SMD:C_0402_1005Metric | CL05B104KO5NNNC | Samsung | C1525 |  |
| D1 | TPD1E01B04DPYR | Package_SON:Texas_DPY0002A_0.6x1mm_P0.65mm | TPD1E01B04DPYR | Texas Instruments | C779389 |  |
| D2 | TPD1E01B04DPYR | Package_SON:Texas_DPY0002A_0.6x1mm_P0.65mm | TPD1E01B04DPYR | Texas Instruments | C779389 |  |
| D3 | TPD1E01B04DPYR | Package_SON:Texas_DPY0002A_0.6x1mm_P0.65mm | TPD1E01B04DPYR | Texas Instruments | C779389 |  |
| D4 | TPD1E01B04DPYR | Package_SON:Texas_DPY0002A_0.6x1mm_P0.65mm | TPD1E01B04DPYR | Texas Instruments | C779389 |  |
| D5 | TPD1E01B04DPYR | Package_SON:Texas_DPY0002A_0.6x1mm_P0.65mm | TPD1E01B04DPYR | Texas Instruments | C779389 |  |
| D6 | TPD1E01B04DPYR | Package_SON:Texas_DPY0002A_0.6x1mm_P0.65mm | TPD1E01B04DPYR | Texas Instruments | C779389 |  |
| D7 | TPD1E01B04DPYR | Package_SON:Texas_DPY0002A_0.6x1mm_P0.65mm | TPD1E01B04DPYR | Texas Instruments | C779389 |  |
| D8 | TPD1E01B04DPYR | Package_SON:Texas_DPY0002A_0.6x1mm_P0.65mm | TPD1E01B04DPYR | Texas Instruments | C779389 |  |
| D9 | TPD1E01B04DPYR | Package_SON:Texas_DPY0002A_0.6x1mm_P0.65mm | TPD1E01B04DPYR | Texas Instruments | C779389 |  |
| D10 | TPD1E01B04DPYR | Package_SON:Texas_DPY0002A_0.6x1mm_P0.65mm | TPD1E01B04DPYR | Texas Instruments | C779389 |  |
| L10 | 2.2uH 20% DFE201210U-2R2M=P2 | footprints:IND_Murata_DFE201210U | DFE201210U-2R2M=P2 | Murata | C2049745 |  |
| Q1 | DMG2305UX-13 | Package_TO_SOT_SMD:SOT-23 | DMG2305UX-13 | Diodes Incorporated | C144153 |  |
| R22 | 4.7k 1% | Resistor_SMD:R_0402_1005Metric | 0402WGF4701TCE | UNI-ROYAL | C25900 |  |
| R23 | 4.7k 1% | Resistor_SMD:R_0402_1005Metric | 0402WGF4701TCE | UNI-ROYAL | C25900 |  |
| R30 | 4.7k 1% | Resistor_SMD:R_0402_1005Metric | 0402WGF4701TCE | UNI-ROYAL | C25900 |  |
| R31 | 4.7k 1% | Resistor_SMD:R_0402_1005Metric | 0402WGF4701TCE | UNI-ROYAL | C25900 |  |
| R32 | 100 1% | Resistor_SMD:R_0402_1005Metric | 0402WGF1000TCE | UNI-ROYAL | C25076 |  |
| R33 | 100 1% | Resistor_SMD:R_0402_1005Metric | 0402WGF1000TCE | UNI-ROYAL | C25076 |  |
| R34 | 100 1% | Resistor_SMD:R_0402_1005Metric | 0402WGF1000TCE | UNI-ROYAL | C25076 |  |
| R35 | 100 1% | Resistor_SMD:R_0402_1005Metric | 0402WGF1000TCE | UNI-ROYAL | C25076 |  |
| R36 | 4.7k 1% | Resistor_SMD:R_0402_1005Metric | 0402WGF4701TCE | UNI-ROYAL | C25900 |  |
| R37 | 4.7k 1% | Resistor_SMD:R_0402_1005Metric | 0402WGF4701TCE | UNI-ROYAL | C25900 |  |
| U1 | 453-00001R BL54L15 | footprints:Ezurio_BL54L15_453-00001 | 453-00001R | Ezurio |  | DNP |
| U2 | nPM2100-QEAA | Package_DFN_QFN:QFN-16-1EP_4x4mm_P0.65mm_EP2.7x2.7mm_ThermalVias | NPM2100-QEAA-R7 | Nordic Semiconductor | C46968654 |  |
| U3 | FDC1004 | Package_SO:MSOP-10_3x3mm_P0.5mm | FDC1004DGSR | Texas Instruments | C2865994 |  |
| U4 | SHT40-AD1B | Sensor_Humidity:Sensirion_DFN-4_1.5x1.5mm_P0.8mm_SHT4x_NoCentralPad | SHT40-AD1B-R2 | Sensirion | C2909890 |  |
| X1 | CM8V-T1A 32.768kHz CL=7pF 20ppm | footprints:XTAL_CM8V-T1A_2012 | CM8V-T1A-32.768KHZ-7PF-20PPM-TA-QC | Micro Crystal | C5136974 |  |

All resistors and capacitors use standard KiCad reflow footprints. D1–D10 use
`Package_SON:Texas_DPY0002A_0.6x1mm_P0.65mm`. The module, crystal, inductor,
and battery holder retain their verified part-specific footprints.

## Qualification items

- C21/C23 now use CL10A106MA8NRNC, 10 µF 0603. Verify ≥3.5 µF effective over actual VBAT/VINT bias, temperature, tolerance and aging; these are development selections, not newly qualified capacitors.
- Qualification and current firmware: [reliability work](docs/reliability-2026-09-07/README.md).
- VOUT: C3 + C25 + C27 total 12.3 µF nominal, before module loading. Check both 0.7 µF minimum and 15 µF maximum effective limits. LDOSW draws from VINT; C26/C28 do not directly add to VOUT.
- C26/C27/C28 are now selected in the schematic as listed above; earlier TBD and 0201 descriptions were stale.
- Preserve the exact BL54L15 antenna module, SHT40-AD1B opening (no integrated membrane), inductor footprint, and X1 load/drive requirements. Keep the cell out during hot work.
- Qualify module supply ripple and low-battery radio/heater transients before release.

See the [component review](docs/component-review-2026-09-05/README.md) and [power review](docs/power-review-2026-09-05/README.md) for evidence and test procedures.

Current schematic revision implements the consolidated development BOM. PCB update and layout are assigned to Alex. See [implementation record](docs/schematic-consolidation-2026-09-09/README.md); older cost-review selections are historical.

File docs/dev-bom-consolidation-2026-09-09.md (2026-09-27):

> Subsequent status: schematic changes and Alex’s PCB update are complete; source files match the regenerated JLC quote package. See [Rev A checkpoint](rev-a-checkpoint/README.md). Earlier implementation-stage notes below are historical.

# Consolidated development-board BOM

Status: **implemented in the schematic only** at Alex’s request. PCB update and routing
are assigned to Alex. [Implementation and checks](schematic-consolidation-2026-09-09/README.md).
The rationale and original quote estimates below remain the design record; capacitor
qualification and a refreshed assembly quote are still pending.
Baseline: `f6205a2`. See [checkpoint tests](sweep-2026-09-09.md).

## Decision

Alex wants fewer unique capacitor and diode parts for these development boards.
Keep ESD suppressors fitted, consolidate all ten to one part, and accept reduced
power-rail clamping performance. This build is not an intensive ESD qualification
run. Select consolidated capacitors after checking effective capacitance and fit.
The development ESD tradeoff does not imply production qualification.

This is the most consolidated practical target identified using existing quoted
parts while preserving distinct circuit functions, not a proven global optimum
across all available parts. Seven capacitor SKUs become four; two diode SKUs
become one. Merge the 4.7 kΩ and 5.1 kΩ groups onto 4.7 kΩ, omit C13 and
bypass R1 with copper per the supplied module integration guidance.
JLC purchase lines drop from 20 to 14, Extended lines from 12 to eight.
U1 remains a separate manual-fit purchase: 15 unique parts for the complete
product, excluding the battery cell and mechanical enclosure.

## Proposed complete purchase list

| References | Qty/board | Value/function | Proposed MPN | LCSC | Quote library | Action |
| --- | ---: | --- | --- | --- | --- | --- |
| BT1 | 1 | CR2032 holder | CR2032-BS-6 | C22363833 | Extended | Retain |
| C3, C21, C23 | 3 | 10 µF, 25 V, X5R, 0603 | CL10A106MA8NRNC | C96446 | Basic | C21/C23 change from 22 µF 0402; qualify and check fit |
| C22, C24 | 2 | 1 nF, 50 V, X7R, 0402 | 0402B102K500NT | C1523 | Basic | Retain PMIC RF bypass |
| C25, C26 | 2 | 2.2 µF, 6.3 V, X5R, 0402 | CL05A225MQ5NSNC | C12530 | Basic | C26 changes from 1 µF; qualify |
| C27, C28 | 2 | 100 nF, 16 V, X7R, 0402 | CL05B104KO5NNNC | C1525 | Basic | Retain local bypass |
| D1–D10 | 10 | Bidirectional low-capacitance ESD, DPY | TPD1E01B04DPYR | C779389 | Extended | Change D1–D3; retain D4–D10 |
| L10 | 1 | 2.2 µH PMIC inductor | DFE201210U-2R2M=P2 | C2049745 | Extended | Retain |
| Q1 | 1 | Reverse-battery PMOS | DMG2305UX-13 | C144153 | Extended | Retain |
| R22, R23, R30, R31, R36, R37 | 6 | 4.7 kΩ, 0402 | 0402WGF4701TCE | C25900 | Basic | Retain pull-ups; change R30/R31 from 5.1 kΩ |
| R32–R35 | 4 | 100 Ω, 0402 | 0402WGF1000TCE | C25076 | Basic | Retain debug series resistance |
| U2 | 1 | PMIC | NPM2100-QEAA-R7 | C46968654 | Extended | Retain |
| U3 | 1 | Capacitance converter | FDC1004DGSR | C2865994 | Extended | Retain |
| U4 | 1 | RH/T sensor, no integrated membrane | SHT40-AD1B-R2 | C2909890 | Extended | Dev cost option; retain AD1F if membrane protection is needed |
| X1 | 1 | 32.768 kHz, CL 7 pF crystal | CM8V-T1A-32.768KHZ-7PF-20PPM-TA-QC | C5136974 | Extended | Retain |
| U1 | 1 | BL54L15, manually fitted | 453-00001R | — | Outside JLC quote | Required in finished product |

This planning table is not the manufacturing BOM. The schematic fields remain
authoritative; regenerate BOM/CPL after implementing the revision.

## Why combining the diodes is reasonable here

Both existing MPNs are bidirectional and share the DPY footprint. There is no
unidirectional/bidirectional mix to resolve. Bidirectional D1 avoids a forward
shunt across a reversed raw battery; Q1 provides reverse-battery isolation.

Choose **TPD1E01B04DPYR at all ten locations**. It preserves the current sensing
and shield loading. Its DPY capacitance is 0.20 pF typical, 0.23 pF maximum;
the often-quoted 0.18 pF typical figure is for DPL. Its leakage maximum is 10 nA
at ±2.5 V. TPD1E1B04 instead has 1 pF typical capacitance and a 100 nA leakage
maximum at that bias. Using the stronger part everywhere changes the sensitive
nodes and is less attractive for a sensing development board.

The tradeoff is at D1/D2/D3: the common low-capacitance part clamps at 9.2 V
at 5 A TLP versus 6.8 V for the former rail part; the 8/20 µs surge-current
rating is 2.5 A versus 6.3 A. These are device test conditions, not guaranteed
voltages at the IC pins. Both have ±3.6 V standoff; that is not their clamping
voltage. Neither supplies sustained-overvoltage protection.

This is an acceptable development tradeoff, not a polarity incompatibility or
removal of all ESD protection. Survival of a particular discharge is unproven.
Consolidation also does not fix the existing D8 ground-via test failure.

Sources: [TPD1E01B04](https://www.ti.com/lit/ds/symlink/tpd1e01b04.pdf),
[TPD1E1B04](https://www.ti.com/lit/ds/symlink/tpd1e1b04.pdf).

## Capacitor checks before implementation

- **C21/C23 to common 10 µF:** each needs at least 3.5 µF effective over actual
  VBAT/VINT bias, tolerance, temperature and aging. Prior C3 screening found
  6.60 µF typical at 3.3 V and an illustrative 4.49 µF after tolerance and
  temperature factors. These are not guaranteed combined corners. Check VINT
  in every relevant mode, startup and transient droop. The change grows both
  footprints from 0402 to 0603; review physical fit and decoupling return loops.
- **C26 to common 2.2 µF:** verify C25's part at 3.3 V and the FDC switched-rail
  startup/supply behavior. TI's example uses a 1 µF tantalum plus 100 nF ceramic;
  nominal 2.2 µF ceramic alone does not establish equivalence. Retain C28.
  C26/C28 draw from the VINT-derived switched rail, not directly from VOUT.
- **Keep C3 at 10 µF:** moving it to the existing 22 µF part saves no Extended
  fee and increases cost. Any alternative must meet the 0.7–15 µF effective
  total VOUT limit including C3/C25/C27 and the module. Nominal 22 µF alone
  neither proves nor disproves compliance.
- **Keep 1 nF and 100 nF separate:** PMIC RF bypass and local bypass
  functions differ. C13 is now proposed for omission per the module review below. Making dielectric labels identical
  would not combine different-value SKUs. Moving the 2.2 µF roles to common
  10 µF could be studied separately, but changes output loading, area and inrush;
  it is not an established substitution in this target.

Sources: [prior Samsung curve screening](cost-reduction-2026-09-09/README.md),
[Nordic circuitry](https://docs.nordicsemi.com/r/bundle/ps_npm2100/page/chapters/hw_layout/ref_circuitry/doc/frontpage.html),
[Nordic hardware guidelines](https://docs.nordicsemi.com/r/bundle/nwp_058/),
[FDC1004 datasheet](https://www.ti.com/lit/ds/symlink/fdc1004.pdf).

## Five-board quote and savings

Source: supplied `JLC-BOM-JLCPCB Assembly Order (2).xls`, sheet
`JLCPCB BOM Tool - BOM Matching`, download time printed as 2026-09-10 09:32:38.
The file contains OOXML despite its extension. Screenshot charges: PCB $30.04,
PCBA $104.09, displayed total $134.13. Components sum to $55.2252, matching the
displayed $55.23. See [archived quote inputs](dev-bom-quote-inputs.json) for source
hashes, row numbers, quoted prices, library types and screenshot charges.

Twelve Extended lines and a $36.84 fee imply $3.07 per line. That is an inferred
uniform fee for this order, not a general JLC pricing rule. Library status and
unit prices are quote-specific. Hold the other displayed charges constant.

| Change | Component calculation | Parts savings | Fee savings | Order savings |
| --- | --- | ---: | ---: | ---: |
| C21/C23 to C3 part | $2.676 − 10 × $0.0552 | $2.1240 | $3.07 | $5.1940 |
| C26 to C25 part | $1.720 − 5 × $0.0058 | $1.6910 | $3.07 | $4.7610 |
| All diodes to TPD1E01B04 | $1.4977 + $2.8275 − 55 × $0.0725 | $0.3377 | $3.07 | $3.4077 |
| R30/R31 to common 4.7 kΩ | $0.026 − 10 × $0.0029 | −$0.0030 | $0 | −$0.0030 |
| Omit C13 | Eliminate quoted 20-piece purchase | $0.0700 | $3.07 | $3.1400 |
| Remove R1 and bridge with copper | Eliminate five-piece purchase | $0.0195 | $0 | $0.0195 |
| Combined | | $4.2392 | $12.28 | **$16.5192** |

C26's original purchase is 20 pieces for five fitted capacitors. Original diode
purchases are 17 + 39 = 56 for 50 fitted parts. The common-diode estimate assumes
55 purchased pieces including allowance; with 56, combined savings are $16.4467.
Re-quote for actual attrition quantities, MOQs and price tiers.

New components: approximately $50.9860. New Extended fees: $24.56. New displayed
PCB + PCBA total: **$117.61**, saving **$16.52/order**, **$3.30/board**, about
**12.3%**. Checkout rounding can move cents. This excludes unshown shipping,
tax, manual module purchases, battery and enclosure costs.

Other scenarios discussed: C25/C26 plus common low-capacitance diodes alone saves
$8.17. Adding the 10 µF consolidation saves another $5.19. Using the stronger
diode everywhere saves about $2.55 instead of $3.41 and changes sensing loading.
Replacing C3 with existing 22 µF costs about $1.06 extra with no feeder-fee saving.

## Common 4.7 kΩ resistors

Propose **0402WGF4701TCE / C25900** for all six R22/R23/R30/R31/R36/R37.
Retain the four existing I²C pull-ups and change only the two sense series
resistors from 5.1 kΩ to 4.7 kΩ. Their package and 1% tolerance stay the same.

This lowers sense series resistance by 7.84%. At an illustrative 100 pF load,
RC changes from 0.51 µs to 0.47 µs, modestly improving settling. For the same
voltage across the resistor, current rises by 8.51%; this is a simple Ohm's-law
comparison, not a prediction of ESD current with a nonlinear clamp. Neither value
establishes pulse survival or measurement settling by itself. The development
tradeoff is reasonable and aligns with retaining basic ESD protection while
prioritizing sensing and a simpler BOM. Check sensor repeatability after the change.

Both resistor lines are Basic. The supplied quote charges $0.058 for 20 of the
4.7 kΩ part ($0.0029 each) and $0.026 for ten of the 5.1 kΩ part ($0.0026 each).
At unchanged unit prices, consolidating onto 4.7 kΩ raises the five-board parts
cost by $0.003, effectively zero, and saves no feeder fee. Its benefit is one
fewer SKU. A refreshed quote might change the combined-quantity price tier.

Using 5.1 kΩ everywhere instead would save $0.006 at these prices but weaken the
I²C pull-ups (roughly 8.5% longer RC rise time at fixed bus capacitance). Prefer
4.7 kΩ to preserve the reviewed bus pull-ups and slightly reduce sense settling
resistance. Retain the 100 Ω debug group. R1 is now proposed for removal and a copper
bridge, as explained in the module-datasheet review below.

Source topology and existing settling limitations: [probe review](probe-review-2026-09-09/README.md).
The quoted resistor inputs are rows 19–20 in the archived source data. The current
TI support link returned HTTP 403 during this follow-up; no new manufacturer
approval of either value is claimed.

## R1 and C13: original screening, superseded by supplied module datasheet

Alex asked whether R1 could join the 4.7 kΩ group and C13 could join another
capacitor group. Review found a functional reason not to adopt either as a
routine BOM substitution. The initial proposal retained R1 = 1 kΩ and C13 = 3.9 pF. The later module
datasheet review below supersedes that decision and the purchase table is updated.

The maintained netlist is programmer RESET_EXT → R35 (100 Ω) → SWD_RST →
R1 (1 kΩ) → module NRESET. PMIC PG/RESET also connects to SWD_RST; C13
shunts NRESET to GND. R1 is a series resistor, not a pull-up. Ezurio specifies
a 13 kΩ internal reset pull-up in BL54L15.

With an ideal zero-volt programmer output, ignoring the PMIC pull-up and other
nonidealities, the nominal module reset level is approximately:

- Existing: VDD × 1.1 kΩ / (13 kΩ + 1.1 kΩ) = 0.078 VDD, or 0.26 V at 3.3 V.
- Proposed R1 = 4.7 kΩ: VDD × 4.8 kΩ / (13 kΩ + 4.8 kΩ) = 0.270 VDD,
  or 0.89 V at 3.3 V.

These are screening calculations, not guaranteed reset thresholds or a worst-case
model. Pull-up tolerance, reset input threshold, programmer/PMIC output-low voltage,
PMIC pull-up and module internal circuitry must be included before approving
4.7 kΩ. The substantial reduction in low-level margin makes it a poor automatic
substitution. It would save only $0.005 per five-board order at the quoted prices
($0.0195 old R1 purchase minus five × $0.0029), with no Extended fee saving.

Nordic explicitly identifies the 1 kΩ / 3.9 pF QFN reset network as suppression
of TX second-harmonic emissions coupled onto RESET. The RF fundamental is around
2.4 GHz; the second harmonic is around 4.8 GHz. At these frequencies capacitor
ESL, self-resonance, package and layout matter; more nominal capacitance does not
mean more suppression. Nordic specifically rejects replacing 3.9 pF with 10 nF.
The ideal RC corner (~41 MHz for 1 kΩ and 3.9 pF) alone does not explain or
validate the GHz behavior. C13 is neither a crystal load capacitor nor a generic
reset-delay capacitor.

Our board uses an Ezurio module rather than a bare QFN reference design. The
Nordic evidence explains the inherited values but does not prove an additional
host-side C13 is required if the module already provides the relevant internal
filtering. Confirm that with Ezurio/module circuit evidence before removing the
host capacitor or replacing it with 1 nF. Current module documentation inspected
here does not establish the internal filtering implementation. Do not claim this
host layout is RF-qualified merely because the nominal values match Nordic's.

Replacing C13 with the existing 1 nF part would theoretically save $3.11/order
($0.07 old purchase plus $3.07 fee minus five × $0.006), and omitting it would
save $3.14. At this stage these were unapproved scenarios. The later module-specific
review below now includes omission (not a larger capacitor) in target totals.
The dev decision to accept weaker ESD protection does not automatically accept
changed reset reliability or radio-emission behavior. The initial recommendation was to keep the pair pending module-specific evidence;
that evidence is evaluated below.

Sources: [Ezurio reset pull-up and integration documentation](https://www.ezurio.com/documentation/datasheet-bl54l10-and-bl54l15-series),
[Nordic explanation and rejection of 10 nF substitution](https://devzone.nordicsemi.com/f/nordic-q-a/121811/nrf54lxx---reset-circuitry),
[Nordic confirmation of the tested 1 kΩ / 3.9 pF network](https://devzone.nordicsemi.com/f/nordic-q-a/127632/nrf54l15-reference-design-onboarding-questions/564599).

## Supplied BL54L15 datasheet review: omit the external reset RC

Source: user-supplied `453-00001R_new.pdf`, BL54L15/BL54L10 Series v1.8,
42 pages. Text searched across the document; pages 9, 20 and 21 visually inspected.
Source SHA-256: `1968a812ea2bd265636c7432667eabbafa98503b96df2c7493b6a96265f017b6`.

Section 7.1, printed page 20, identifies one mandatory external 10 µF capacitor
for module integration. Its reset bullet says to wire nRESET to a push button
or drive it from the host. The continuation on page 21 identifies the internal
13 kΩ pull-up. No external series resistor or reset shunt capacitor is specified.
The block diagram on page 9 is functional, not an internal passive schematic;
it does not establish whether the exact Nordic 1 kΩ / 3.9 pF pair exists inside.

**Revised development recommendation: omit C13 and remove/bypass R1 using copper.**
This follows the module integration guidance instead of imposing the bare-SoC
reference RC on the sensor. Do not replace R1 with 4.7 kΩ or C13 with a much
larger capacitor. R1 is in series: simply marking it DNP without bridging it
would disconnect reset and is incorrect. Retain R35 (100 Ω), D7, and the existing
PMIC PG/RESET connection. The remaining 100 Ω debug resistor is our sensor
protection choice, not an Ezurio requirement.

This is a module-specific engineering inference from its documented integration
requirements, not proof of the internal filter implementation or RF/ESD testing
of this sensor. Verify programming, connect-under-reset, PMIC-triggered reset,
power-up and normal radio operation on the development boards. The earlier
voltage-divider objection still applies to adding 4.7 kΩ in series; removing
R1 avoids that objection instead of trying to tolerate the larger voltage drop.

Omission saves $3.14 for C13 and $0.0195 for R1 in the five-board quote; reduced
placement charges, if any, are not included. The target is now four capacitor
SKUs and two resistor SKUs (4.7 kΩ and 100 Ω), with one diode SKU. Total: 14 JLC
purchase lines, eight Extended lines, plus the required manual-fit module.
No schematic or PCB edits were made during this document review.

## Additional U4 cost option requested during review

Use genuine **Sensirion SHT40-AD1B-R2, C2909890** as the proposed clean-bench
development option. Current KiCad remains SHT40-AD1F-R2, C7461846. This is a
unit-cost substitution, not a further reduction in unique parts or feeder fees.
Both options are Extended in the available data.

The AD1B retains the SHT40 accuracy class, 0x44 I²C address, commands, supply
range and four-pin assignment. Its 1.5 × 1.5 mm body uses the same recommended
land pattern, with a lower body height because it lacks the membrane. Existing
firmware needs no protocol change. Retain the no-central-pad footprint: the
distributor's DFN-4-EP label is not an instruction to solder the die pad.
Sensirion advises against soldering that pad or exposing copper underneath it.

The tradeoff is loss of the AD1F integrated protective membrane. AD1B is reasonable
for clean bench development; retain AD1F or provide suitable breathable external
protection for exposure to soil, dust or splashes. Keep the humidity opening free
of coating and assembly contamination. Earlier project notes preferred retaining
the membrane; this newly requested dev option is explicitly an exception under
consideration, not an unnoticed equivalent substitution.

Sensirion datasheet v7.3 (June 2026) calls the membrane polyimide; the catalog page
and older revisions call it PTFE. The functional distinction here is the presence
or absence of an integrated membrane, irrespective of that naming discrepancy.

PCBParts `jlc_get_part(mpn="SHT40-AD1B-R2")` returned genuine Sensirion C2909890,
Extended, database price $1.9053, stock 22,892. These are cached database values;
the quantity tier was not established and no live checkout price was available.
The current quoted AD1F is $12.80 for five, or $2.56 each. **If five AD1B parts
price at $1.9053 with no additional procurement fees**, the saving is
5 × ($2.56 − $1.9053) = **$3.2735**. There is no additional feeder-fee saving.
With all capacitor/diode proposals, this illustrative scenario totals **$114.34**,
or **$19.79/order ($3.96/board)** saved. Keep the quote-backed capacitor/diode
estimate above separate from this conditional sensor-price estimate. Ordering
directly from LCSC for hand assembly also has separate shipping/procurement costs.

Sources: [Sensirion SHT4x datasheet, sections 5, 6, 9 and 10](https://sensirion.com/resource/datasheet/sht4x),
[JLC C2909890 listing](https://jlcpcb.com/partdetail/Sensirion-SHT40_AD1BR2/C2909890),
[LCSC part link](https://www.lcsc.com/product-detail/C2909890.html).
The JLC page confirms MPN, manufacturer, assembly compatibility and Extended type;
price above comes from PCBParts, not from a completed quote.

## Next steps

1. Validate capacitor bias/corner behavior and 0603 fit; record final MPNs or fallbacks.
2. Implement common diodes, common 4.7 kΩ resistors and accepted capacitor changes
   in schematic and PCB. Omit C13 and remove R1 with a copper bridge, retaining
   R35/D7 and the PMIC reset connection; verify both reset sources on hardware.
3. Update intentional selection checks only after review: `test_reservoir_selection.py`
   currently enforces Nordic-listed 0402 parts. Do not bypass it merely to pass a test.
4. Reconcile the three checkpoint failures; run connectivity, ERC/DRC and repository
   checks; regenerate JLC BOM/CPL and obtain an updated quote.
5. Check cold/aged-cell startup, radio droop, FDC power-up and sensing repeatability
   on prototypes. Intensive ESD qualification remains a separate production task.

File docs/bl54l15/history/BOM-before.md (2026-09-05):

# BOM & Part Selection

Generated from the netlist. Regenerate the component table after any schematic
change. Companion to [HARDWARE.md](HARDWARE.md) and [LAYOUT.md](LAYOUT.md).

**Footprint policy:** hand-solder variants everywhere they exist. The one
exception is the RF matching network — **L2, L3, L4, C6, C9, C11 stay 0201
standard pads**. Nordic's component values are matched to their reference land
pattern, and hand-solder pads add enough parasitic capacitance at 2.4 GHz to
shift a 0.3 pF capacitor. Don't "fix" those to hand-solder.

MCU support passives are 0402 rather than Nordic's 0201, for assembly. That
needs slightly more room around the QFN48 than the reference layout uses — get
them as close to their pins as the larger pads allow.

---

## Parts still to select

### Crystals — the datasheet constrains these harder than expected

**X1 is selected: Micro Crystal CM8V-T1A, 32.768 kHz, C_L 7 pF, ±20 ppm, TA, QC.**
Verified against the nRF54L15 LFXO table (§11.9.2), every parameter:

| nRF54L15 requires | Spec | CM8V-T1A 7 pF | |
|---|---|---|---|
| Load capacitance C_L | 6–9 pF | **7.0 pF** | mid-range, margin both ways |
| Shunt capacitance C0 | typ 1.0, max 2.0 pF | 1.2 pF typ | ok |
| Equivalent series resistance R_S | typ 60, max 100 kΩ | 55 typ / 70 max kΩ | ok |
| Drive level P_D | max 0.5 µW | 0.5 µW max | exactly matched |
| Frequency tolerance (BLE) | ±500 ppm | ±20 ppm | far tighter than needed |
| Package | 2012 2-pin | 2.0 × 1.2 × 0.60 mm | ok |

7 pF is a better choice than the 9 pF the reference BOM suggested — 9 sits at the
hard maximum, 7 sits mid-window with room for PCB stray either side. Ordering
code pattern: `CM8V-T1A 32.768 kHz 7.0 pF ±20 ppm TA QC`.

Footprint is Micro Crystal's own land pattern (`XTAL_CM8V-T1A_2012`, 0.8 × 1.5 mm
pads on 1.5 mm centres). KiCad's generic 2012 footprints do not match it — the
hand-solder variant uses 1.05 mm pads on 1.85 mm centres and the nominal uses
0.6 mm on 1.4 mm.

| | X1 (LFXO) — SELECTED | X2 (HFXO) |
|---|---|---|
| Frequency | 32.768 kHz | 32 MHz |
| **Load capacitance C_L** | **6–9 pF — 9 pF max** | **6–9 pF, use 8 pF** |
| Shunt capacitance C0 | 1.0–2.0 pF | see Figure 17 |
| **Max drive level** | **0.5 µW** | 100 µW |
| Frequency tolerance | ±20 ppm (Nordic ref) | **±40 ppm total for BLE** |
| Package | 2012, 2-pin | 2016, 4-pad |

**The C_L ≤ 9 pF limit rules out most 32.768 kHz crystals**, which are commonly
12.5 pF. Filter on load capacitance first, everything else second.

ESR is not a single number — the datasheet gives it as a curve of maximum
allowable ESR against C0 for a given C_L (Figure 17, §5.5.1.2). Check the
candidate's ESR and C0 against that curve rather than looking for a spec line.

Candidate family for X2, **ordering code not confirmed**:
- X2: Abracon ABM8W-32.0000MHZ-8-B1U-T3, or NDK NX2016SA-32M

No discrete load caps — both oscillators use internal trim banks. See
HARDWARE.md §2.

---

## Connector heights — resolved

With the retired rechargeable pack removed, the available internal height is
**11.70 mm** above the PCB over the electronics band. The tallest items are the
CR2032 retainer and installed cell (~5.6 mm). Only the debug contact pattern remains:

| Ref | Part | Height | Note |
|---|---|---|---|
| J4 | Tag-Connect `TC2050-IDC-NL` | 0 | nothing soldered; needs the TC2050 cable + retaining clip |

J2 (battery) and J3 (solar) are deleted with the architecture change — the
CR2032 sits in an on-board retainer and there is no external power input at all.

Tag-Connect uses the standard 10-pin Cortex debug pinout, which is what J4 was
already wired to, so no net changes.
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

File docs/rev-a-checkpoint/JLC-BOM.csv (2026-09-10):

Comment | Designator | Footprint | JLCPCB Part #
CR2032-BS-6 | BT1 | footprints:BatteryHolder_LianXin_CR2032-BS-6 | C22363833
10uF/25V X5R | C3,C21,C23 | Capacitor_SMD:C_0603_1608Metric | C96446
1nF 50V X7R | C22,C24 | Capacitor_SMD:C_0402_1005Metric | C1523
2.2uF/6.3V X5R | C25,C26 | Capacitor_SMD:C_0402_1005Metric | C12530
100nF 16V X7R | C27,C28 | Capacitor_SMD:C_0402_1005Metric | C1525
TPD1E01B04DPYR | D1,D2,D3,D4,D5,D6,D7,D8,D9,D10 | Package_SON:Texas_DPY0002A_0.6x1mm_P0.65mm | C779389
2.2uH 20% DFE201210U-2R2M=P2 | L10 | footprints:IND_Murata_DFE201210U | C2049745
DMG2305UX-13 | Q1 | Package_TO_SOT_SMD:SOT-23 | C144153
4.7k 1% | R22,R23,R30,R31,R36,R37 | Resistor_SMD:R_0402_1005Metric | C25900
100 1% | R32,R33,R34,R35 | Resistor_SMD:R_0402_1005Metric | C25076
nPM2100-QEAA | U2 | Package_DFN_QFN:QFN-16-1EP_4x4mm_P0.65mm_EP2.7x2.7mm_ThermalVias | C46968654
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

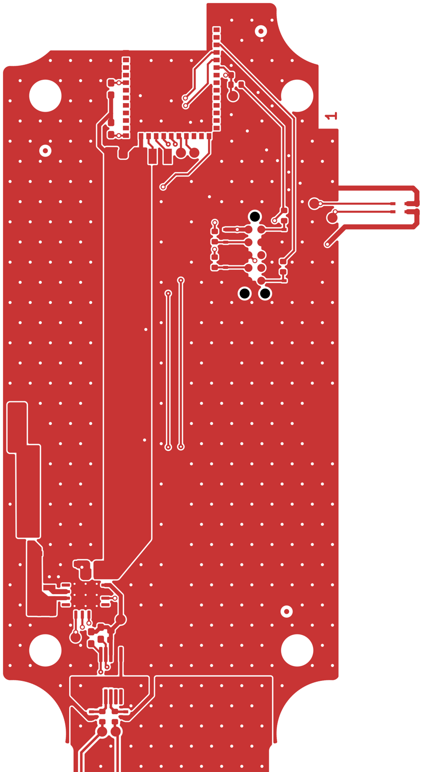
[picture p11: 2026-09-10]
docs/footprint-review-2026-09-09/front-copper-components.png

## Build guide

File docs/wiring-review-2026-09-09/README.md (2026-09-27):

# Wiring and pre-fabrication review — 9 September 2026

**Follow-up supersedes the fabrication-blocker conclusion below:** [JLC via capability and I²C leakage review](../jlc-vias-i2c-2026-09-09/README.md). JLC's rigid four-layer via limits permit the reported geometry. Correcting the overly conservative rules removes those errors without changing copper. The user also accepted the D8/D9 return layout. The original measurements below remain a historical record, not the current release decision.

**Do not release the current files to fabrication unchanged.** No unintended net short, missing routed connection, or schematic/PCB connectivity mismatch was found. There are concrete fabrication-rule failures and a probe-protection layout regression, plus electrical behaviors that need prototype qualification.

This review does not modify the maintained design or firmware. It checks the current files rather than relying on older audit conclusions. Source identifiers are in [source-sha256.json](source-sha256.json). Evidence: [DRC](drc.json), [ERC](erc.json), [netlist](netlist.xml), [schematic](schematic.png), [copper](copper.png), [assembly view](assembly.png), [hardware tests](tests.txt), [firmware host tests](firmware-tests.txt).

## Fix or resolve before sending fabrication files

### 1. P1 — Via geometry fails the board's fabrication rules

Fresh native KiCad DRC with zone refill, schematic parity and all severities reports **205 errors**:

- **199 annular-width errors:** 0.100 mm measured against the project's 0.130 mm minimum. Examples include PMIC_INT vias at (67.52,102.69) and (76.19,58.54) mm and numerous ground stitching vias. A 0.50 mm pad around a 0.30 mm drill has a nominal 0.10 mm ring. For that drill, a 0.56 mm diameter is the arithmetic minimum for the present rule; 0.60 mm provides additional nominal margin. Any resizing needs a fresh clearance check.
- **Six hole-to-copper clearance errors:** 0.227–0.240 mm against 0.250 mm. These occur around the SCL via at (68.825,101.800), reset via at (71.410,99.325), and SDA via at (68.175,102.200) mm, involving SDA, PMIC_INT and the switched FDC supply traces.

Resolve the geometry or obtain explicit fabrication capability for the intended stackup and make the rules accurately reflect it. A netlist match does not establish adequate drill registration margin. Do not simply suppress these failures.

### 2. P1 — D8/D9 local ESD ground returns have regressed

The clamps remain correctly connected to ground electrically, but the nearby ground-plane vias/fingers from the 7 September implementation are absent. Their present 0.4 mm front-layer traces are:

- D8 ground: (69.080,111.290) → (68.842,111.290) → (66.400,108.848) → (66.400,106.370), about **6.17 mm** of drawn trace.
- D9 ground: (72.480,111.290) → (72.730,111.290) → (75.070,108.950) → (75.070,106.410), about **6.10 mm**.

The traces meet the electronics ground before their final endpoints, so those lengths are not an extracted high-frequency return impedance. Nevertheless, they clearly replace the former local plane connections with a long return through the analog region. The existing `test_esd_return_planes` test fails at D8; direct inspection confirms the missing local return for D9 too. See [four-layer detail](esd-returns.png).

Restore a short, broad return to electronics ground or move the protection boundary toward that ground. Recheck added sensor/shield capacitance. The signal topology itself is now electrode → R30/R31 → CIN with D8/D9 on the CIN side, consistent with [TI's placement guidance](https://e2e.ti.com/support/sensors-group/sensors/f/sensors-forum/527553/fdc1004-esd-protection).

### 3. P1 — Saved manufacturing package is from a different design

Every hash in `production/jlc-economic-quote/source-sha256.json` differs from the corresponding current PCB, schematic, project and rule file. Its 7 September clean-DRC statement cannot release this revision. Regenerate Gerbers/drills/BOM/CPL and assembly instructions together after the fixes, then inspect those actual outputs. U1 is deliberately DNP for JLC assembly and must still be sourced and fitted separately.

### 4. P2 — Silkscreen and regression expectations need reconciliation

The remaining **90 DRC warnings** comprise 39 silk-over-copper, 38 silk overlaps, one silk-edge clearance, ten footprint-library mismatches, one dangling +3V3 track, and one NRESET via connected on only one layer. They are not reported unrouted nets. The TP13 reference is clipped near the board edge; old M1/M2 legends remain near the former marker positions, whereas TP16/TP17 have moved to (79.29,55.15)/(77.96,55.15). Clean the labeling before generating assembly/probing instructions.

Of 17 selected hardware regression tests, 15 pass. The second failure is the SENSE routing-class test expecting 0.2 mm clearance while the project specifies 0.6 mm. A more conservative clearance is not an electrical defect; reconcile the intent and test rather than reducing clearance merely to pass it. Review intentional library differences before any library update.

## Unintended behaviors to qualify

### Probe protection is not yet coordinated with the IC limits

D10 connects directly to both shield outputs, without a series limiter. D8/D9 also clamp directly at the protected CIN nodes. The selected TVS typically breaks down at 6.4 V and has a 7 V typical TLP clamp at 1 A; it is not a precision 3.3 V clamp. These exceed the FDC analog-pin DC limits, especially with its supply off. R30/R31 limit electrode current but do not sit between the TVS node and CIN. This is an unresolved protection risk, not proof of a particular ESD failure. Review residual voltage/current at the IC and test both polarities, powered and unpowered, with the final coating. [TVS datasheet](https://www.ti.com/lit/ds/symlink/tpd1e01b04.pdf).

### A wet probe can saturate or settle poorly

Both 16 × 30 mm electrodes occupy all four layers; both outer faces sense the environment. A deliberately strong-coupling estimate for one electrode's two external faces, with grounded conductive material and coating εr=4, is about **136 pF at 0.25 mm coating**, or **68 pF at 0.50 mm**. These are screening calculations, not predictions for actual soil. The thinner example exceeds the approximate CAPDAC-plus-conversion range. The earlier front-only simulation cannot qualify this geometry.

With 5.1 kΩ input resistors, 100 pF gives RC=0.51 µs. That is not comfortably below TI's recommended sub-microsecond input settling scale. Sweep raw capacitance, CAPDAC headroom, noise and settling in wet/saline soil using the actual coating and insertion depth. Also check shield loading; the specified drive limit is 400 pF. Keep measurements single-ended: externally tied SHLD1/SHLD2 preclude differential operation. [FDC1004 datasheet](https://www.ti.com/lit/ds/symlink/fdc1004.pdf), [TI resistor guidance](https://e2e.ti.com/support/sensors-group/sensors/f/sensors-forum/527553/fdc1004-esd-protection).

### Powered-off FDC leakage remains unknown

SDA/SCL stay pulled up to the always-on rail while the FDC supply is discharged. Their independent 6 V absolute maximum does not guarantee negligible leakage at VDD=0. The old statement in HARDWARE.md that this proves no back-powering is too strong. Measure both off-rail voltage and battery current; active discharge can hide leakage by keeping the rail near zero while wasting current. Do not move the shared pull-ups onto the switched rail: that would prevent the PMIC from receiving the command to enable it. [FDC1004 ratings](https://www.ti.com/lit/ds/symlink/fdc1004.pdf).

### Radio supply and battery margins require real measurements

The BL54L15 receives VOUT directly. Ezurio specifies 10 mV maximum ripple/noise; Nordic lists 70 mVpp typical LP/ULP ripple. The real sensor application requests and verifies HP before sensing and radio, which is appropriate, but measure the rail at U1.26 during TX and supply transitions. [Ezurio supply requirements](https://www.ezurio.com/documentation/datasheet-bl54l10-and-bl54l15-series), [local Nordic datasheet, Table 10](../../doc/datasheets/nPM2100_Datasheet_v1.0.pdf).

C3+C25+C27 total 12.3 µF nominal directly on VOUT, plus the module's input capacitance. Verify 0.7–15 µF effective over bias/tolerance/temperature. C21/C23 now use the exact Nordic-reference GRM158R60J226ME01D part, but effective capacitance still matters. C26/C28 are on the separate VINT-fed LDOSW branch, not directly on VOUT; test their turn-on transient separately.

Use a depleted/cold-cell equivalent with realistic source resistance to test startup, repeated wake and TX. Keep the SHT45 heater disabled until the cell/load is qualified. Q1 correctly protects reverse insertion, but is not a fuse or a complete reverse-current barrier. J4.1 is directly connected to +3V3: use it as target-voltage reference, not as an unqualified external supply with a primary cell installed.

## Wiring that checked out

| Path | Current connections / conclusion |
|---|---|
| Battery and reverse PMOS | BT1.1 → Q1 drain 3; Q1 source 2 → VBAT; gate 1 → GND. Holder positive pad is the left contact per its archived drawing. |
| Boost power stage | L10 connects protected VBAT to U2.2 SW. U2.14/.15 share VINT with C23/C24. U2.13 supplies +3V3. No functional external load is wired directly to VINT; TP10 is measurement access. |
| PMIC defaults | VSET/SHPHLD/GPIO1 are unused; SYSGDEN is grounded. Cold boot requires software to select 3.3 V and load-switch mode before enabling FDC. |
| FDC power and inputs | U2.12 → U3.8; CIN1/.2 and CIN2/.3 have their separate series resistors/clamps. CIN3/4 are NC. GND is U3.7. |
| I²C | U1.28=P1.10 SDA; U1.35=P1.11 SCL; both reach PMIC/FDC/SHT with separate 4.7 kΩ pull-ups to +3V3. Firmware uses these pins at 100 kHz. Addresses 0x74/0x50/0x44 do not collide. |
| SHT45 | SDA1, SCL2, VDD3, GND4; main-rail supply and local C27. |
| Programming/reset | J4 pins 2/4/6 reach SWDIO/SWDCLK/SWO through 100 Ω; pin 10 reaches reset through R35 then R1. PMIC PG/RESET joins between those resistors; U1 reset is pin 7. J4 grounds are pins 3/5/9. |
| Crystal and markers | XL1 U1.25 → X1.1; XL2 U1.24 → X1.2. TP16 → U1.20 P1.07; TP17 → U1.21 P1.06. Marker nets are routed in this snapshot. |

ERC reports zero errors and ten symbol-library warnings. Native refilled DRC reports zero unconnected items and zero schematic-parity issues; its existing ignored categories are preserved in the report. The sensor host tests pass, and source inspection confirms real sensor reads, 3.3 V configuration, HP scheduling, shutdown and watchdog handling. This review did not rebuild the SDK image or exercise physical hardware.

## First-article checks after the layout corrections

1. Inspect final Gerber copper/mask/drill/paste layers and assembly rotations. Confirm U1 hand-fitting instructions, U2 exposed-pad paste/via treatment, BT1 polarity and all labeled test points.
2. Check unpowered rail resistance and battery polarity, then start with a current-limited battery-equivalent supply. Scope main and FDC rails through startup, shutdown and repeated wake cycles.
3. Measure sleep current, FDC-off leakage, I²C levels/rise time, radio ripple, and cold/depleted-cell behavior. Inject a stuck bus and verify the PMIC actually power-cycles the peripherals.
4. Measure crystal startup/frequency with the selected internal load setting. Test SWD attach/reset and use the correct sensor image; the older BTHome demo advertises simulated values.
5. Qualify coated-probe range, shield waveform, temperature drift, salinity, abrasion and water absorption; test ESD on the finished assembly. Keep coating off the SHT45 sensing membrane.
6. Verify the actual holder, installed cell, enclosure, screw and programming-cable clearances. The rendered holder is a visualization substitute and this render does not include the final enclosure. Test BLE performance with the closed enclosure and wet probe; footprint keepout compliance alone does not qualify the antenna.

The concrete fab-rule failures and return-layout regression should be resolved before a prototype order. Wet-soil, supply, leakage, ESD and RF measurements are first-article qualification work; until those pass, treat an order as an engineering prototype run rather than a production release.

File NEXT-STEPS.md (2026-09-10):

> Rev A checkpoint: consolidated schematic and updated PCB match the JLC export. See [checkpoint and Rev B follow-ups](docs/rev-a-checkpoint/README.md).

> 2026-09-09 cost revision: U4 is now Sensirion SHT40-AD1F-R2. The existing SHT4x footprint, membrane handling, geometry, and legacy SHT45-named model/rule areas are retained. See [cost revision](docs/cost-reduction-2026-09-09/README.md).

> Current nRF Moisture Sensor work: [2026-09-05 review and remaining tasks](docs/design-review-2026-09-05/README.md). This supersedes older routing and unresolved-order-code notes below.

# Where this stands, and what's next

**Current state — 2026-09-04 BL54L15 migration:** U1 is 453-00001R; X2,
the discrete nRF DC/DC/RF support and the host antenna are removed. X1 and all
product GPIO assignments are retained. Routing is deliberately left for Alex.
Use [the current checklist](BOARD-FINISH-TODO.md) and
[the integration / verification record](docs/bl54l15/README.md).
Manufacturing outputs are review-only. Supply ripple, module input capacitance,
clock trim and the enclosure's incomplete preferred metal separation remain
prototype gates.

## Earlier engineering journal (historical state)

The following entries preserve prior work. Their bare-QFN, X2, AE1/R27/C29,
RF-return, routing-complete and BOM counts are superseded by the module migration.
Unrelated enclosure, PMIC, sensing and DK experiment findings remain references.

Companion to [HARDWARE.md](HARDWARE.md), [LAYOUT.md](LAYOUT.md) and [BOM.md](BOM.md).
Written at the end of the placement session.

**Schematic ERC 0 errors, 0 warnings.** The production board is physically
routed, including the RF launch and matching network; the remaining gate is the
final DRC result and review of any intentional warnings. The maintained board,
not a generator or route table, is the source of truth for all copper.

19/19 DRU fire-tests pass. Round-trip verified after every bulk edit: board
graphics come back bit-identical, and footprint positions differ only by the
two deliberate moves in `tools_place_fixups.py`.

---

## Diagrams

`doc/enclosure-fit.png`, `doc/enclosure-corner.png` and `doc/enclosure-section.png`
show how the board sits in the box. Regenerate with
`.venv-cq/bin/python tools_encl_draw.py` — the cavity in them is the real
measured cross-section from Hammond's STEP at the height the board actually sits,
not a reconstruction from radii, which is what made the corner-relief error
visible in the first place.

---

## Read this first

The one-shot generators and historical route writers are retired and fail-safe:
`tools_gen_pcb.py`, `tools_gen_sch.py`, `tools_route.py`,
`tools_finish_routes.py`, `tools_add_zones.py`, and `tools_place_fixups.py` exit
before reading or writing project data. Do not run them as part of production
work. The maintained KiCad files and the physically routed board are the source
of truth; only review/measurement helpers that explicitly write scratch output
remain in use.

---

## The board

**42.0 × 155.0 mm**, four layers, **JLC04161H-3313**, 1.6 mm nominal (see §3).

| Zone | y | |
|---|---|---|
| A antenna | 0 – 10.0 | AE1 copper radiator and all-layer keepout |
| B electronics | 10.0 – 74.0 | 34.0 mm wide, in the enclosure, solid In1.Cu |
| — SHT45 jut-out | 18.1 – 23.1 | x 34 → 42, through the side wall |
| C probe | 74.0 – 155.0 | 20 mm wide, no ground on any layer |

The maintained board now uses AE1, an integrated PCB monopole, with R27/C29
antenna tuning provisions. J5 and the external flex antenna are removed.
This geometry is provisional until RF tuning is complete. See LAYOUT.md §3.

---

## Blocking, in rough order

### 1. Routing — incomplete; antenna connected

The antenna conversion adds no DRC errors or unconnected items. The existing
board still has 11 track-width errors and 3 unconnected items; resolve them
before fabrication. The RF path is:
U1 pin 31 → L2/C6/L3/C9/L4/C11 → R27 → AE1, all on F.Cu with no RF vias; C6 returns
locally through `RF_PA_RETURN_LOCAL` under U1's VSS_PA/centre-pad tie, and C9
uses the B.Cu-only `RF_C9_RETURN_BOTTOM` return. Zone B retains the continuous
In1.Cu ground and matching cutouts; the F.Cu RF corridor remains via-free.

Do not use the retired route table to regenerate copper. Review the maintained
board in KiCad and complete the final DRC pass before release. `tools_add_zones.py`
and `tools_place_fixups.py` remain historical records/helpers only; do not run
them against the production board unless their output is first reviewed in a
scratch copy.

The remaining status is electrical verification rather than route generation:
inspect the final DRC report and resolve any intentional warnings before fab.
The stacked ground structure is deliberate: Zone B GND on F.Cu/In1.Cu, +3V3
on In2.Cu, and driven guard on the probe layers.

Watch what the DRU cannot catch. **NT1 needs no copper** — its pads physically
overlap U1 pad 32 and pad 49, so the tie is made by the land pattern; that is
what the NT1 clearance exemption in the `.kicad_dru` is for. **NT2 must stay on
B.Cu.** And the U1 centre-pad via array must not bridge RF_PA_RETURN_LOCAL to GND anywhere
except at NT1 — the nearest via is 0.345 mm from NT1's `/RF_PA_RETURN_LOCAL` pad and DRC
reports no short, so that holds.

### 1a. C6 return geometry (record)

Routing found a hard blocker. U1 pins 33 (DECRF), 34 (XC1) and 35 (XC2) all
have to escape westward, and the only corridor was the band between C6 and the
bottom pad row. `/RF_PA_RETURN_LOCAL` ran diagonally from C6.2 at (75.22, 58.5) up to pad
32 at (76.4, 60.079), straight across it. Solving the point-to-line distance
for pin 33 at x = 76.0 gives a legal 0.15 mm track only at **y ≥ 59.814 or
y ≤ 58.459** — the first is inside the pad row, the second is on the far side
of `/RF_PA_RETURN_LOCAL`. **Pin 33 had no legal escape at any width.**

The crossing is structural rather than a width problem: C6's ground pad has to
reach pin 32, and unless it sits directly under pin 32 that return path
separates pins 33/34/35 from everything below them.

**C6 is now rotated 270° at (76.10, 57.50)**, in the 0.91 mm gap between L3 and
L2, ground pad under pin 32. `/RF_PA_RETURN_LOCAL` becomes a straight climb up x = 76.35
and the corridor opens from y 57.7 to 59.698 — room for all three lanes.

**And the old position was wrong on RF grounds independently.** C6 is the
1.5 pF shunt on the L2/L3 node at x = 76.8. From (74.58, 58.5) its stub to that
node ran 3.02 mm, roughly 2 nH in series with the capacitor:

| | Z at 2.4 GHz |
|---|---|
| ideal 1.5 pF | −j44.2 Ω |
| with the old 3.02 mm stub (~2 nH) | +j30.2 − j44.2 = **−j14.0 Ω** |
| with the new 0.39 mm stub (~0.3 nH) | +j4.5 − j44.2 = **−j39.7 Ω** |

A 3× error in the shunt reactance is not a rounding difference — the stub was
doing more to the match than the capacitor was.

**What it costs.** `/RF_PA_RETURN_LOCAL` is now squeezed between pin 33's pad at x = 76.102
and the `/ANT` run at x = 76.62, so it narrows from 0.4 mm to 0.2 mm over most
of its length: about 2.0 mm of 0.2 mm track, ~1.9 nH against ~1.2 nH before.
Roughly **+0.7 nH in the VSS_PA return**, traded for taking ~1.7 nH out of the
shunt branch. Both are inside the VNA session that was already budgeted.

### 1b. What the layer plan actually is now

| Layer | Zone A | Zone B | Zone C |
|---|---|---|---|
| F.Cu | ground pour | ground pour, **not** in the RF corridor | electrodes + guard |
| In1.Cu | ground plane | ground plane | **nothing** |
| In2.Cu | — | **+3V3 plane** | guard |
| B.Cu | — | signal (debug bus) | guard |

`RFPourKeepout` holds the F.Cu ground pour ≥ 1.1 mm off the x = 76.8
controlled RF corridor. The 0.1565 mm width is JLCPCB's official non-coplanar
L1/L2 calculator result; coplanar ground would change the impedance. The In1.Cu
reference under the run is untouched — the stitching
generator bans vias in the whole RF corridor for the same reason.

Both new pours use **solid** pad connections, not thermal relief. Spokes cannot
resolve two-per-pad on the QFN ground pins, which
DRC reports as `starved_thermal`, and a spoke in series with a QFN ground pin
is inductance this board does not want. The cost is that GND pads are harder to
hand-solder.

### 2. Power-input architecture — retired from this board

The production board is CR2032-only. USB-C, solar, rechargeable-pack, charger,
NTC, and charge-status circuitry are not fitted and have no nets or footprints
in the production PCB. Do not place, route, or reintroduce those legacy blocks;
they belong to the separate pump-controller board.

### 3. Stackup and fab action

Order **JLC04161H-3313**, 4-layer, 1.6 mm nominal, with impedance control.
The symmetric 3313 dielectric is 0.0994 mm (εr 4.1), the 1.265 mm core is εr
4.42, and the official calculator width is **0.1565 mm** for 50 ohm
non-coplanar L1/L2. Confirm the pressed stack and impedance result on the fab
acknowledgement. See LAYOUT.md §1–2.

### 4. ~~The board does not fit the enclosure~~ — fixed

Measured from Hammond's STEP with cadquery (`tools_encl_check.py`). The 1551WK
cavity is not a rounded rectangle: it has four corner bosses running the full
cavity height, **R4.4193 mm at the board's bottom face**, centred at
**(±35.75, ±15.75)** from the box centre. The board's old R4.5 corners were
entirely inside them — 4.32 mm of interference at all four corners.

This also resolved the drawing figures that "did not reconcile": `R4.42` is the
boss radius and `62.00 × 22.00` is the flat edge span left *between* the reliefs.
Hammond's "Maximum PCB 74.50 × 34.50" assumes the corners are scalloped.

**Fixed — at R5.0, not the R4.669 first tried.** All four corners carry a concave
relief arc centred on the boss, meeting the board edge **6.091 mm** in from each
corner. At the probe end there is a **0.409 mm flat at y = 74** between the
relief and the shoulder fillet, and the fillet is **R0.5** — see below.

**The first attempt at R4.669 did not fit, and it is worth recording why.** It was
solved against the boss circle alone. The real cavity corner is not just that
arc: an **R1.0 blend** joins each wall to the boss, and it intrudes slightly
further than the boss circle does. Measured against the *actual* cavity boundary,
R4.669 gave **−0.028 mm** — interference, not the intended +0.25 mm clearance.
Solving against the measured boundary instead gives R ≥ 4.986, so R5.0 is used.

| | cut-back | clearance to the real cavity |
|---|---|---|
| R4.669 (boss circle only) | 5.749 mm | **−0.0278 mm** — interferes |
| **R5.0 (measured boundary)** | **6.091 mm** | **+0.2624 mm** |
| R5.5 | 6.606 mm | +0.5348 mm (saturates — limited by the 0.545 mm side gap) |

Hammond's own numbers agree with the corrected figure and not the first one: their
`62.00 × 22.00` flat span on a 74.50 × 34.50 PCB implies a **6.25 mm** cut-back.
Ours is 6.091 mm on a 74.0 × 34.0 board, which scales to 6.34 mm. The old 5.749 mm
scaled to 5.999 mm and undershot it.

Verified by sampling the whole Edge.Cuts outline against the measured cavity at
both the board's bottom and top faces: **0 points outside, 0.2624 mm tightest at
the bottom face** (the worst case — the bosses taper with draft, so the top face
is looser at 0.3066 mm).

**The shoulder fillet had to shrink from R2.0 to R0.5.** The relief reaches
x = 6.091 at y = 74 and the probe edge is at x = 7.0, so there is 0.909 mm per
side for the fillet plus any flat. R2.0 and R1.0 are both impossible. R0.5 leaves
a 0.409 mm flat. Recovering R2.0 would need the probe narrowed to ~16.8 mm, which
leaves the 16 mm electrodes 0.4 mm of guard — not viable. See LAYOUT.md §9.

`ZoneB_GND` also needed its outline rebuilt: as a plain rectangle its fill came
within 0.2984 mm of the new arcs against the 0.3 mm edge rule. It now follows the
corners at R5.35.

The antenna-end reliefs are retained. The new AE1 radiator fits inside the
remaining central top tongue (LAYOUT.md §3). At the probe end they forced the LED cluster to move: D3/D4 and
R25/R26 shifted from y 108.5/111 up to y 99.5/102, clear of both the relief and
the bottom-right mounting hole.

Post pattern and post height are confirmed exactly as documented — (±27.50,
±12.50), a 55.00 × 25.00 pattern, 4.00 mm tall — and the mounting holes land on
them.

### 5. ~~Three enclosure openings, none sealed~~ — decided: the box is IP54, not IP68

**The IP68 rating is given up deliberately.** Write it on the drawing. Three
openings, one sealing method, and the target is splash resistance:

| Opening | Size | Seal |
|---|---|---|
| Probe slot, end wall | 20.2 × 1.8 mm | flexible RTV silicone bead, both faces |
| SHT45 jut-out slot, long side wall | 5.0 mm × board thickness, centred y = 20.6, 4.00–5.60 mm above the floor | same |

Hammond do factory milling for the first two.

**Why not keep IP68.** Three separate reasons, and the first one alone settles
it:

- **Any milling voids Hammond's rating anyway.** It is a rating on the
  enclosure as supplied, with its moulded gasket and captive lid screws. Once a
  slot is cut through a wall, the number on the datasheet describes a part that
  no longer exists, whatever is put in the slot afterwards.
- **The probe slot cannot be sealed rigidly.** The probe is an 81 mm cantilever
  that gets pushed into soil, and its shoulder fillet is already down to R0.5
  because the corner reliefs took the room (LAYOUT.md §9). A hard potting
  compound at the wall would make that shoulder the stress riser for every
  insertion. It has to be a flexible bead, and a flexible bead round a
  rectangular slot is not an immersion seal.
- **The threat model is watering splash, not immersion.** The box sits in a
  plant pot indoors. IP54 covers that. Nothing about the design contemplates
  the unit being under water, and if it were, the probe is a bare capacitive
  electrode in the soil regardless.

**What it would take to keep IP68**, recorded so the option is not
re-discovered: a moulded gasket around the probe rather than a bead, and the
SHT45 moved off its jut-out and behind a PTFE membrane vent. That is a
different enclosure, not a modification of this one.

**Two stale notes closed by this.** LAYOUT.md §10 said the SHT45 in a sealed
box "measures the box, not the room" and wanted a membrane vent in the lid —
that stopped being true when U4 moved onto the jut-out and left the box
entirely. The production enclosure has no board-mounted external power inlet.

---

### 2. X2's pad numbering was on the wrong diagonal — fixed, and it would have killed the 32 MHz oscillator

Found while lining the 3D models up. The model was right and the footprint was
wrong.

FA-128 datasheet page 1, "External dimensions" TOP VIEW with the 2.0 mm axis
horizontal, has **#4 top-left, #3 top-right, #1 bottom-left, #2 bottom-right**,
and the "Internal connection (TOP VIEW)" inset puts the resonator between
**#1 and #3** with the note *"#2 and #4 are connected to the cover. (Please
connect to ground)"*. So the crystal terminals are the BL–TR diagonal and the
cover pads are BR–TL.

Epson's recommended land on the same page is **1.45 mm wide × 2.00 mm tall** —
0.95 mm x-centres, 1.15 mm y-centres, 0.5 × 0.85 mm pads — which our footprint
copies exactly. That land seats the part with its **2.0 mm axis vertical**, so
the pinout rotates with it:

| | #1 | #2 | #3 | #4 | crystal on |
|---|---|---|---|---|---|
| 90° CW | TL | BL | BR | TR | TL–BR |
| 90° CCW | BR | TR | TL | BL | TL–BR |

Both give the same answer, because 180° maps a diagonal to itself: **with the
2.0 mm axis vertical the crystal terminals are always TL–BR.**

The footprint had **pad 1 at BL and pad 3 at TR — the cover diagonal.** The
schematic wires pad 1 to XC1 and pad 3 to XC2, so XC1 and XC2 would have landed
on the two grounded cover pads and the actual crystal terminals would have been
tied to GND through pads 2 and 4. The oscillator would not have started.

**Nothing in ERC or DRC could see it.** All four pads exist, all four are
connected, and the two ground pads are legitimately ground. It is only visible
against the datasheet drawing, or — as it happened — by noticing that the 3D
model's index mark refused to line up.

Fixed in `tools_fix_footprints.py`, applied to both the library `.kicad_mod`
and the placed instance: the numbering rotates one position so pad 1 is the
top-left corner, which keeps 1–3 and 2–4 diagonal as the part requires. The
silk pin-1 dot moved to match, and the F.Fab rectangle — drawn 2.0 × 1.6 where
its own pads say 1.6 × 2.0 — was transposed and given its chamfer on the new
pin-1 corner. `/XC1` and `/XC2` were re-routed to the corrected pads.

**Renaming a pad does not move its net.** The net follows the piece of copper,
so the first pass left GND on pads 1 and 3 — the same defect one corner round.
The script now states the schematic's pad→net binding explicitly and enforces
it.

### 3. 3D models — current fitted parts covered

`tools_3d_models.py` is the model-assignment table used by the repair tool.
Project footprints carry the same assignments, so updating footprints from the
library does not remove their models.

| | model | rotation | why |
|---|---|---|---|
| U1 | `lib/nordic/QFN48_6X6_NOR.step` | none | Nordic QFN48 model, already Z-up |
| U2 | KiCad `Texas_RSA_VQFN-16-1EP_4x4mm….step` | none | matches the selected QEAA QFN16: 4×4 mm, 0.65 mm pitch, 2.7 mm exposed pad |
| X1 | `lib/CM8V-T1A/….step` | (−90, 0, 0) | vendor model, height along +Y |
| X2 | `lib/FA-128 ….STEP` | (−90, 0, 90) | height along +Y; Z turn aligns its long axis |
| U4 | `lib/SHT45_AD1F_R2/SHT45-AD1F-R2.step` | (−90, 0, 0) | local vendor model replaces a missing KiCad-library reference |
| L10 | `lib/DFE201210U_2R2M_P2/IND_DFE201210U-2R2MP2_MUR.step` | none | supplied Murata model, already Z-up and centred |
| BT1 | `lib/CR2032-BS-6-1_C70377.step` | (0, 0, 180), Z offset +0.08 mm | Q&J visualization substitute; purchase Lian Xin CR2032-BS-6/C22363833 per the schematic and selected-holder drawing |

The similarly named downloaded nPM2100 bundle contained a 1.9×1.9 mm WLCSP
model and was removed. The selected `nPM2100-QEAA` is the 4×4 mm QFN; Nordic's
package code for the WLCSP is `CA`, not `QE`.

**The rule that makes this tractable:** KiCad's 3D frame is X = footprint X,
**Y = minus footprint Y**, Z = up. A pad at footprint local (lx, ly) sits at
3D (lx, −ly). The Nordic models confirm it — QFN48's pin-1 lead is at model
(−2.768, **+2.200**) and its pad 1 at local (−2.921, **−2.200**), the same
corner with y negated — which is why they need no rotation at all.

The two crystal models and the holder model are vendor exports with package
**height along +Y** instead of +Z, measured with cadquery rather than guessed:

```
FA-128     x -0.800..0.800 (1.600)   y 0.000..0.500 (0.500)   z -1.000..1.000 (2.000)
CM8V-T1A   x -1.000..1.000 (2.000)   y 0.000..0.600 (0.600)   z -0.600..0.600 (1.200)
BU2032     x -15.93..15.93 (31.86)   y 0.000..5.200 (5.200)   z -9.925..9.925 (19.85)
```

so they need one −90° turn about X to stand above the PCB. Verify with
`kicad-cli pcb render --side top --pivot …` rather than by eye in the GUI — it
is repeatable and it is how the FA-128 defect surfaced.

Still without models, all legitimately: J4 (Tag-Connect, no fitted body), NT1
and NT2 (net ties), and TP1–TP3 (bare pads).

---

## Verify before fab

- ~~Window-pane the QFN paste apertures~~ — **done.** Both lands were drawn
  oversize and pasted as one full-area aperture. Against the vendor package
  drawings (nRF54L15 Table 83: D2/E2 4.5/**4.6**/4.7 mm; nPM2100 Table 36:
  3.4/**3.5**/3.6 mm) the QFN48 land was at D2 max and the QFN32 land was
  3.6068 mm, i.e. *over* its 3.6 mm maximum. Both are now at D2 nominal with a
  3×3 aperture array — U1 1.25 mm on 1.675 mm pitch, U2 0.95 mm on 1.275 mm
  pitch, both 66 % coverage, inside IPC-7093's 50–80 %. Thermal paste volume
  drops 35.1 → 22.2 mm². Verified in the exported `F.Paste` gerber: 9 flashes
  each and no full-area aperture. Fixed in `lib/footprints.pretty/` and in the
  placed instances, so a re-import stays correct.
- ~~Add centre-pad vias under U1 pad 49 and U2 pad 33~~ — **done.** U1 gets
  Nordic's 4×4 grid at 1.2 mm pitch; U2 gets 3×3 at the same pitch, because
  4×4 at 1.0 mm would put the outer annulus past the 3.5 mm pad edge. 0.3 mm
  drill on 1.2 mm pitch is 0.9 mm hole-to-hole against the 0.5 mm minimum.
  **Order with vias tented** — the paste is window-paned to 66 % coverage and
  untented vias under a thermal pad wick solder out of the joint.
- **Confirm C0 for the FA-128 with Epson — still open, now confirmed unobtainable
  from the datasheet.** `FA-128_en.pdf` was re-read end to end: the Specifications
  table gives f_nom, T_stg, T_use, DL, f_tol, f_tem, C_L, R1 and f_age, and there
  is no C0 row at all. It is half of what the Figure 17 ESR curve checks, so this
  needs an email to Epson. ESR (60 Ω max at 26–54 MHz), drive level (200 µW max,
  10 µW recommended) and the land pattern are all confirmed — see BOM.md.
- **1551WK corner reliefs — measured, and the board does not fit.** See the
  BLOCKING entry below. `R4.42` from the drawing is confirmed exactly (4.4193 mm
  measured) and `62.00 × 22.00` is the flat edge span *between* corner reliefs,
  so the drawing was self-consistent all along — it was telling us the PCB needs
  scalloped corners. The `55.00 × 25.00` post pattern is confirmed exactly.
- ~~Get the DC-bias curve for L1 from Murata SimSurfing~~ — **closed by changing
  the part.** L1 is now the **TDK MLZ1608M4R7WT000**, which publishes I_sat
  (120 mA at 50 % L drop) and I_temp (350 mA typ). The Murata published neither —
  only a 620 mA temperature-rise figure — and saturation is what matters in a
  buck. Nordic's `4.7 µH / 120 mA / ±20 % / 650 mΩ` line turns out to be the TDK
  part's datasheet row verbatim, and the nRF54L15 publishes no DC/DC peak
  current at all (§11.14). Worst-case peak through L1 is ~60 mA at maximum TX
  power, ~2× under the 120 mA half-inductance point. See BOM.md.
- **Measure the CR2032 under realistic load.** Verify sleep current, the
  `+3V3_FDC_SW` gate, and the end-of-life voltage/pulse margin with the selected
  holder and enclosure. Record the measured capacity and leakage for the
  production cell; do not carry assumptions from a rechargeable pack into this
  board. See HARDWARE.md §3.

---

## Bring-up

### Only our board can do these

- **Tune AE1 with the enclosure, battery and realistic soil load.** Remove
  R27 for VNA isolation, trim the open end and select R27/C29 values. Verify
  radiated performance as well as S11 before freezing the geometry.
- **Check whether the jut-out perturbs the monopole.** It is an 8 mm cantilever
  5.8 mm from U1, within the antenna's near field. Unpowered FR4 with four thin
  traces, so probably very little, but measure rather than assume.
- **Trim INTCAP** on both oscillators. The register value excludes PCB stray,
  and the DK's stray is not ours — the DK is only good for rehearsing the
  procedure, not for a value.
- **Absolute sleep current** against the 500 mAh budget (§7). The DK carries
  loads we do not.

### On the nRF54L15 DK (PCA10156) — done, 2026-08-04

All four claims from HARDWARE.md §6 were exercised on the DK with a BME280 as
the bus target. Firmware, overlays and full results are in
[firmware/](firmware/README.md).

| Claim | Result |
|---|---|
| SDA and SCL must share a port (§8.8.3) | **confirmed** — `i2c22` cannot reach P0.04 |
| P0 can wake from System OFF (Table 40) | **confirmed** — real wake, `RESET_LOW_POWER_WAKE` |
| P2 cannot wake (Table 40) | **confirmed** — `-ENOTSUP`, the port will not arm |
| TWIM SCL needs a clock pin (Table 77) | **not reproducible** — see below |

**The pin assignment is unchanged.** Every rule we designed to held, so nothing
moves. The value is that three of them were previously "read a table and
believed it" and are now demonstrated — §8.8.3 especially, since a peripheral
that cannot reach its pin is not something ERC or DRC catches.

**The clock-pin rule could not be made to fail**, at 400 kHz or at 1 MHz, which
is the TWIM ceiling on this part. That is not evidence the rule is void: Table
77 is a timing-margin claim, and a room-temperature bench on jumper wire
consumes none of the margin. **P1.11 stays.** What we gained is knowing the
margin is large at our operating point, so deviating later would be a
deliberate low-risk choice rather than a blind one.

**Honest assessment of the exercise.** None of it changed the board. The prior
probability that Nordic's own tables were right was always high, and we had
already complied with all three rules, so the tests could only ever return
"yes, you were right". What it did buy, beyond the verification itself, is a
working container build, flash and console path, plus `pin-probe` for telling
`-ENODEV` apart from a loose wire — all of which real bring-up needs anyway,
and all cheaper to build against a known answer than an unknown one.

**Still to do on the DK, and not yet done:** set VDD:nRF to 3.3 V in Board
Configurator (default is 1.8 V) and take a System OFF current baseline on P6
with the PPK2. Leave SB9 closed so the external flash stays on VDD:IO and out
of the measurement. This will not give us our sleep figure — the DK carries
loads we do not — but it proves nothing is holding the SoC awake.

**Bench traps, both of which cost time here:**

- The **P1 header's 00-03 positions are parenthesized** on the silkscreen and
  are not connected without modification (P1.00/P1.01 need SB3-SB6, P1.02/P1.03
  are NFC1/NFC2 and need 0 Ω resistors). P0.00-P0.04 are not parenthesized.
  Wiring "03"/"04" on the P1 header instead of P0 lands on P1.03 (dead) and
  P1.04 (`uart20` TXD, the console).
- The **P6 jumper feeds VDD:nRF**. With it out the SoC is unpowered while the
  debugger stays alive on USB 5 V, and the failure surfaces as `nrfutil` saying
  "debug port unavailable" with no mention of power.
- Each GPIO header carries its own **`VDD:IO`** pin — buffered VDD:nRF, and a
  more convenient 3.3 V supply for a breakout than P6.
- The Zephyr console is **VCOM1**, not VCOM0.

### BTHome firmware on the DK — simulated data, 2026-08-05

The seven-task BTHome plan
([docs/superpowers/plans/2026-08-04-bthome-firmware.md](docs/superpowers/plans/2026-08-04-bthome-firmware.md))
is implemented and console-verified on the DK. Full detail, build/flash
instructions and packet layout: [firmware/bthome-sensor/README.md](firmware/bthome-sensor/README.md).

Console-verified: the product-default build (no `dev.conf`) reports
`sleeping 3600 s`; the dev build (`dev.conf`, 30 s cycle) repeats correctly
across multiple System OFF wakes, with `elapsed` climbing monotonically, the
BLE identity unchanged across resets, and `m1` reading four points above `m2`
on every cycle as the encoder's ordering test requires. The encoder's host
tests (`./tests/bthome/run.sh`) pass.

The **Button 0 escape hatch is confirmed**: held at boot it prints
`Button 0 held — staying awake so the board can be flashed.` and then stays
awake indefinitely, with no further cycles and the debug port answering on
every attempt — which a device in System OFF does not.

**Home Assistant discovery is confirmed** (2026-08-05, HA at 10.1.3.4). The
BTHome integration picked the beacon up on its own as one device, `Plant-1
6100`, at `E7:B4:88:36:61:00` — the same identity the console prints — with
five entities and no YAML:

| Entity | Reading |
|---|---|
| `sensor.plant_1_6100_battery` | 79 % |
| `sensor.plant_1_6100_humidity` | 38.75 % |
| `sensor.plant_1_6100_moisture` | 38.6 % |
| `sensor.plant_1_6100_moisture_2` | 34.6 % |
| `sensor.plant_1_6100_temperature` | 71.942 °F |

(HA also creates a sixth, disabled-by-default signal-strength entity.)

**The positional `_2` mapping lands the right way round.** The entity IDs
settle the question the device page's two identically-named "Moisture" rows
cannot: the higher reading is `…_moisture`, the lower is `…_moisture_2`, four
points apart, exactly as the encoder's ordering test requires.

Values match the console field for field. Consecutive console cycles read
`m1` 38.84 → 38.76 → 38.68 → 38.60 with `m2` pinned 4.00 below, and HA's
states tracked that same series one cycle at a time. Both moisture entities
decline monotonically across a session — `moisture_2` fell 50.6 % → 34.6 %
over the 17:00–18:45 window in a dense 30-second staircase, so HA is receiving
essentially every advertisement, not an occasional one.

That the whole session lives under a single HA device rather than accumulating
new ones is the identity work holding up across hundreds of System OFF wakes.

One trap worth knowing: **the Developer Tools → States table does not always
repaint on a websocket update.** It sat two cycles stale until the page was
reloaded, which reads exactly like missed advertisements. Reload before
concluding the beacon dropped out.

**What remains:**

- **Real sensor drivers** — needs our board. The DK has no soil-moisture,
  temperature or humidity sensors attached, so all five values stay simulated
  until then.
- **Encryption** — BTHome's packet ID becomes mandatory once encryption is
  turned on, and that counter needs to be persisted across cold-boot wakes to
  avoid rewinding on every cycle. No NVS/settings subsystem exists yet.
- **Real battery reporting** — needs an nPM2100 evaluation setup for the fuel
  gauge, plus the open question already in HARDWARE.md §5:
  confirm the NCS fuel gauge library's availability for nRF54L15 and its
  RAM/flash cost for a design that cold-boots hourly.

### PMIC bring-up — nPM2100

The nRF54L15 DK cannot validate the production PMIC path. Use an nPM2100-QEAA
evaluation setup with a CR2032-equivalent source to verify TWI access, 3.3 V
boost configuration, LDOSW gating, and the built-in active discharge of
`+3V3_FDC_SW`. Keep the I²C pull-ups on always-on `+3V3`; never gate them with
the FDC1004 supply, or the PMIC cannot be reached while the switch is off.

Before first power-on, verify R27 is fitted, C29 is initially DNP and AE1 has
no ground or other copper in its keepout. See LAYOUT.md §3 for antenna tuning.

Doing this before our board arrives also means first power-on is a hardware
bring-up rather than a hardware-and-firmware bring-up at the same time.

---

## Known loose ends

- **Split enclosure STEP files do not render in `kicad-cli`.** Geometry and
  assembly positions verified correct by bounding box; three export variants
  tried (AP214, AP203, both extensions, explicit MM units) and all load without
  error and draw nothing, while Hammond's combined file renders fine.
  `ENCL_SPLIT = False` is the default so the viewer works. Worth one try in the
  GUI 3D viewer — a different code path.
- **The enclosure 3D model does not show either milled slot**, so the fit check
  is less useful than it looks.
- **No 3D model for NT3.** It is a net tie and does not need one. X2's is now
  attached (`lib/FA-128 32.0000MF10Z-AJ0.STEP`) but its orientation has not been
  checked in the 3D viewer.
- **Legacy external-input nets are intentionally absent.** Do not restore
  `/SOLAR_PANEL`, USB, or charger connectivity to this coin-cell board.

---

## Toolchain traps worth remembering

- **`insideArea()` is true for a ZONE that merely OVERLAPS the area.** Not for
  the part that intersects — for the whole zone. A relaxing clearance rule
  conditioned on `A.insideArea('X')` therefore catches any pour that crosses X
  anywhere, and through it every item on the board. `ZoneB_GND_F` spans the
  electronics band and crosses six of the seven `FinePitchFanout` windows, so
  the first version of that rule dropped the ground pour's clearance to
  0.15 mm **everywhere** — 97 violations, all at coordinates nowhere near a
  QFN. The fix is `&& A.Type != 'Zone' && B.Type != 'Zone'`, and
  `tools_dru_test.py` now carries a `fanout_scope` case that fails if the
  exemption escapes its windows again.
- **A keepout masks the rule under test.** KiCad reports one
  `items_not_allowed` per item, so if injected geometry lands inside a rule
  area, the keepout fires and the rule you were testing never appears. Two
  fire-tests had been sitting inside `SHT45_Jut` doing nothing. Injection
  geometry has to be checked against the board it is injected into, and the
  board changes.

## Two more toolchain traps

- **DRU rules are last-match-wins.** This had silently disabled *every* width
  rule in the file — `Fab minimum track` matches every track at 0.127 mm and sat
  at the bottom, overriding `Power track width`, `Charge path width` and
  `Switch node width`. Caught by injecting a 0.3 mm track on a Power-class net
  and getting no violation. Fabrication floors now sit **above** the specific
  rules. Any new rule needs an injection test, not a read-through.
- **Both Nordic QFN footprints carry their pin-1 marker twice**, at identical
  coordinates on identical layers. The duplicate markers remain a documented
  library warning; the retired generator is not part of the production flow.

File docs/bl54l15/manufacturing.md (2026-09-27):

# Review manufacturing exports

Follow the repository's KiCad CLI export approach. The maintained schematic
and PCB are authoritative; the retired full-board generators must not be run.
`tools_export_bl54l15.py` automates the CLI commands and adds the two assembly
stages. It only writes the output directory, never the maintained design.

From the repository root, using KiCad 10.99 (file format 20260828):

```sh
export KICAD_CLI=/Applications/KiCad/KiCad.app/Contents/MacOS/kicad-cli
"$KICAD_CLI" sch erc --format json -o docs/bl54l15/erc.json moisture-sensor.kicad_sch
"$KICAD_CLI" pcb drc --refill-zones --save-board --schematic-parity --format json -o docs/bl54l15/drc.json moisture-sensor.kicad_pcb
python3 -m unittest discover -s tests -v
python3 tools_export_bl54l15.py
```

Default output is `production/bl54l15-routing-review/`, ignored by git as with
other manufacturing outputs. It contains:

| Output | Intended use |
|---|---|
| `fabrication-review/` | Four copper, two mask, two silk and Edge.Cuts Gerbers; separate PTH/NPTH Excellon drills and drill map |
| `product-bom.csv` | All 20 fitted product components, including U1 with DigiKey cut-tape order code |
| `jlc-bom.csv` | 19 candidate outsourced placements; excludes U1, includes procurement status |
| `jlc-upload-bom-REVIEW.csv` | JLC column format; unresolved parts remain blank/candidate |
| `jlc-positions-REVIEW.csv` | 19 placements, mm, KiCad origin/rotation; no U1 or bare PCB contacts |
| `jlc-paste/` | Derived board and F/B paste Gerbers with U1 omitted |
| `module-hand-fit-paste/` | Derived board and F/B paste Gerbers containing only U1's 39 LGA apertures |
| `schematic-review.pdf`, `layer-review/` | Schematic and layer drawings for inspection |
| `source-sha256.json`, `export-log.json` | Source identity and actual CLI invocations |

The source board keeps the U1 paste/mask/copper lands. A derived copy removes
U1 for JLC paste; another keeps only U1 for manual paste. Main fabrication files
contain no paste layers, avoiding accidental double application. Both paste
stages use the unchanged PCB coordinate origin. The module patch is a land
pattern, not a vendor-designed stencil frame; align from the placement drawing
and use the qualified local process. No iron-access assumption is made.

**These are review files, not a released order package:** 15 missing connections
remain deliberately. C23 bias qualification, C26/C27/C28 exact sourcing and BT1
assembly source remain open. Module supply ripple, clock trim, enclosure RF
clearance and hot-air attachment require physical validation. After routing,
refill, rerun ERC/DRC/parity, require zero unrouted, reconcile warnings, and
visually inspect final Gerbers and assembly rotations before issuing a release.
Do not upload or order this review package.

## Protection revision supersedes the counts above

The 2026-09-04 protection change adds 17 fitted parts, all on F.Cu. D1 sits
beside the positive battery contact in the revised holder courtyard; bottom
assembly/paste is not required for these additions. The exporter supports both
sides. Re-export into a fresh directory after final routing; old production
archives predate this revision. Stock/assembly availability remains open.
See [protection report](../protection/README.md).

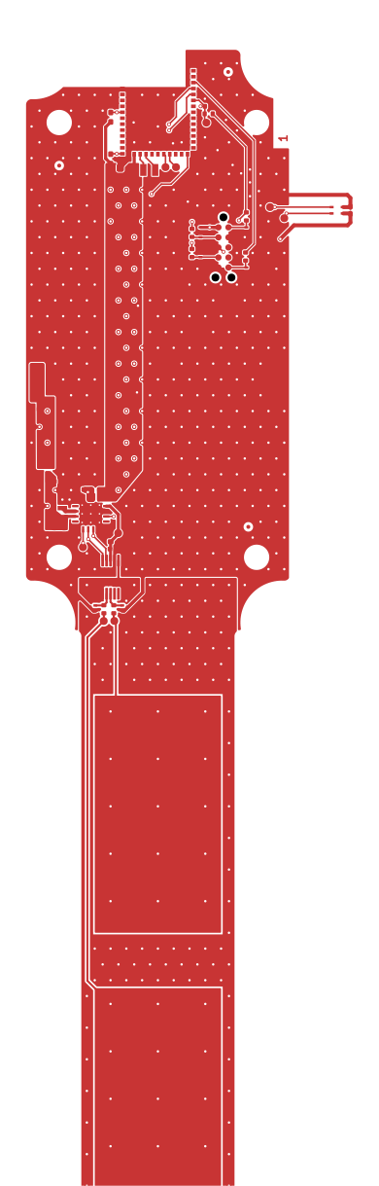
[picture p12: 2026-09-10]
docs/wiring-review-2026-09-09/F_Cu-board.png

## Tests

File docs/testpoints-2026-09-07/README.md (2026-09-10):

# Added test points — 7 September 2026

Added 14 front-side, 1 mm test pads (TP4–TP17) to the maintained PCB and schematic. TP1–TP3 remain SENSE1, SENSE2 and SHLD. All test pads are excluded from BOM and placement exports and have no paste opening.

[Assembled-board test-point map](assembled-head.png) · [front copper](front-head.png) · [inner routing](inner-head.png) · [schematic](schematic.svg)

Coordinates below are absolute KiCad board millimetres. The short names are printed on front silkscreen; reference designators and full net names remain on the fabrication layer.

| Reference | Board label | Net | X, Y (mm) |
|---|---|---|---|
| TP4 | 3V3 | `+3V3` | 73.775, 58.000 |
| TP5 | GND | `GND` | 71.575, 58.000 |
| TP6 | FDC | `+3V3_FDC_SW` | 74.500, 103.800 |
| TP7 | GND | `GND` | 76.700, 103.800 |
| TP8 | VBAT | `VBAT` | 62.200, 96.500 |
| TP9 | RAW | `/VBAT_RAW` | 62.800, 88.000 |
| TP10 | VINT | `/VINT` | 73.500, 95.000 |
| TP11 | GND | `GND` | 75.700, 95.000 |
| TP12 | SDA | `/SDA` | 79.500, 98.000 |
| TP13 | SCL | `/SCL` | 77.000, 98.000 |
| TP14 | INT | `/PMIC_INT` | 82.000, 98.000 |
| TP15 | RST | `/NRESET` | 85.800, 45.500 |
| TP16 | M1 | `/MARK1` | 68.450, 57.000 |
| TP17 | M2 | `/MARK2` | 66.000, 57.000 |

## Timing markers

- **TP16 / M1 / MARK1 = U1 pad 20, nRF P1.07** (`gpio1`, pin 7 in Zephyr).
- **TP17 / M2 / MARK2 = U1 pad 21, nRF P1.06** (`gpio1`, pin 6 in Zephyr).

These two previously unused GPIOs are reserved for firmware timing markers. Updated 2026-09-09: moved from pads 29/30 to bottom-edge pads 20/21 for outward escape without routing through the ground planes. Pads 29/30 and P0.01/P0.02 are unconnected. Both markers are left unrouted for manual routing. No firmware toggling is enabled by this hardware change. Configure these pins as outputs only when instrumenting firmware; retain the normal low-power state otherwise. Connect the logic-analyzer ground to TP5. The markers use the MCU supply voltage, which follows the main rail.

## Placement and routing

TP4/TP5 sit below C3 for local module-supply probing. TP6/TP7 sit beside the FDC bypass capacitors. TP8 samples protected VBAT after Q1; TP9 samples the raw battery near D1. TP10/TP11 are immediately right of the PMIC capacitor cluster. TP13/TP12/TP14 form the left-to-right SCL/SDA/INT row beside U2. TP15 observes NRESET on the MCU side of the reset filter.

Short local front routes serve VBAT, raw battery and module VDD. Diagnostic branches on In2 avoid disturbing the existing front power loops and bottom signal routes. Seven nearby ground stitching vias were repositioned to clear these branches; no existing functional track, component position, antenna rule area or sensing-zone outline was changed. The ground plane remains connected after refill. TP10 is a voltage-probing point only; VINT is not an external-load supply. Use a short probe ground spring for ripple measurements; the VINT/FDC branches do not replace probing directly across the bypass capacitor when investigating very high-frequency noise.

The 3D review includes the hand-fitted radio module and shows all new pads outside component bodies. The existing battery-holder STEP is a substitute, so final enclosure and actual-holder probe access still need physical confirmation.

## Verification

- Native KiCad DRC: zero errors, zero unconnected items, zero schematic parity issues; ten pre-existing library-footprint mismatch warnings.
- Native KiCad ERC: zero errors; ten pre-existing library-symbol warnings.
- Exported schematic netlist verifies every new test-point net and the two marker-to-module pin mappings.
- Historical validation of the initial 2026-09-07 implementation (superseded by the 2026-09-09 pin swap): comparing every original PCB pad net showed only U1.29/U1.30 changed, from unconnected to MARK1/MARK2. See [connectivity record](connectivity.json).
- Relevant repository checks: 10 tests and 21 subtests pass (module pinout/keepouts, assembly flags, ESD ground returns, PMIC topology, fiducials and fabrication archive). The VINT topology expectation now includes TP10 while still excluding any external load.
- Reviewed the schematic, copper layers and assembled top view.
- Refreshed `production/jlc-economic-quote`: 36 fitted components, 20 BOM groups, matching placement file and 13-file Gerber archive. No new purchased components.

[DRC report](drc.json) · [ERC report](erc.json)

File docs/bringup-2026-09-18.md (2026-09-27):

# Moisture board bring-up log — 2026-09-18

## Hardware and connection

- Ezurio BL54L15 / nRF54L15 module
- FDC1004 capacitance sensor
- nPM2100 PMIC
- SHT40
- Raspberry Pi Pico running debugprobe v2.3.1
- CMSIS-DAP UID: `E66130100F523134`
- Board power: CR2032; Pico 3V3 output not connected

## Firmware target

Source: `firmware/sensor`

Development configuration:

- 60-second measurement cycle
- Calibrated BTHome moisture objects
- SENSE1: 2655 fF dry / 5658 fF wet
- SENSE2: 2618 fF dry / 5571 fF wet
- Linear interpolation with 0–100% clamping
- 10-second BLE advertising window

Production configuration remains a 15-minute cycle with low-battery backoff.

## Failure investigation

An earlier RTT diagnostic capture reported `sensor_start rc=-116` during the
first PMIC/FDC startup attempt. The PMIC voltage readings were valid, and the
same path succeeded after retrying. A 250 ms post-battery settle delay plus up
to three retries for `-ETIMEDOUT` were added. Later cold-power diagnostics
completed initialization, measurement, and radio startup successfully.

The more persistent symptom was that a direct BLE scan sometimes saw no packet
after a battery power cycle. The firmware was using a slow advertising
interval while advertising for only two seconds. That window could expire
before the first advertisement event. Development advertising now uses the
fast interval.

## Direct BLE evidence

The device was observed as `Soil-402A` with service UUID FCD2. An 80-second
direct scan after flashing the fast-interval image found it 11 times. Example
calibrated BTHome service data:

```text
4002830803f8100c220b140000140000
```

A final 15-second scan found it four times:

```text
40027c080317110c220b140000140000
```

The packets contain temperature, humidity, voltage, and two calibrated
moisture objects. The old raw-capacitance packet format was not present in the
final image.

## Home Assistant evidence

Home Assistant was reachable at `10.1.3.4`. Its existing BTHome device is
still displayed as `ProbeQA 402A`, using BLE address `CA:D7:1C:65:40:2A`.
That is the cached Home Assistant name; the current packet format is
calibrated and the direct scanner identifies the device as `Soil-402A`.

Recorder history showed successful updates at mixed intervals: approximately
61 seconds, 124 seconds, 249 seconds, and occasional multi-minute gaps. This
is consistent with a 2-second battery-device advertising window being missed
by Home Assistant's distributed Bluetooth scanners. The direct Mac scanner,
which actively scans, observed repeated packets during the same firmware test.

The development advertising window is therefore increased from 2 seconds to
10 seconds. This increases the advertising portion of development energy by
about 5x in the simple window-length model, but does not change the 60-second
measurement cadence or production behavior. The radio sleeps between BLE
advertising events, so total battery impact is lower than a continuous-radio
5x assumption.

## Verification

- `/tmp/pyocd-venv/bin/pyocd list` recognized the Pico debug probe and nRF54L15.
- Final development image flashed successfully with pyOCD.
- Direct FCD2 scans observed `Soil-402A` packets.
- `sh firmware/sensor/tests/run.sh` passed measurements, CRC, range,
  bounded waits, and bus-fault cleanup.
- `git diff --check` passed.

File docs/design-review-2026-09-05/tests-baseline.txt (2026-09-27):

.....F................../Users/alex/moisture-sensor/tools_netcmp.py:58: ResourceWarning: unclosed file <_io.TextIOWrapper name='/var/folders/zw/cgylqvm121j60373883z5k200000gn/T/tmp5h7qb1mw.net' mode='r' encoding='UTF-8'>
  root = parse(open(tmp).read())
ResourceWarning: Enable tracemalloc to get the object allocation traceback
...F...F...........
======================================================================
FAIL: test_only_bare_copper_footprints_are_model_less (test_3d_models.ModelCoverageTest.test_only_bare_copper_footprints_are_model_less)
----------------------------------------------------------------------
Traceback (most recent call last):
  File "/Users/alex/moisture-sensor/tests/test_3d_models.py", line 103, in test_only_bare_copper_footprints_are_model_less
    self.assertEqual(missing, NO_MODEL_EXPECTED)
    ~~~~~~~~~~~~~~~~^^^^^^^^^^^^^^^^^^^^^^^^^^^^
AssertionError: Items in the first set but not the second:
'FID3'
'FID1'
'FID2'
'REF**'

======================================================================
FAIL: test_every_connected_net_has_an_explicit_class (test_pcb_routing_rules.PcbRoutingRulesTest.test_every_connected_net_has_an_explicit_class)
----------------------------------------------------------------------
Traceback (most recent call last):
  File "/Users/alex/moisture-sensor/tests/test_pcb_routing_rules.py", line 77, in test_every_connected_net_has_an_explicit_class
    self.assertEqual(self.assignments, expected)
    ~~~~~~~~~~~~~~~~^^^^^^^^^^^^^^^^^^^^^^^^^^^^
AssertionError: {'/ANT': 'RF', '/RF_50R': 'RF', '/RF_FILTER[574 chars]tal'} != {'+3V3': 'Power', '/NRESET': 'Control', '/P[507 chars]rol'}
Diff is 910 characters long. Set self.maxDiff to None to see it.

======================================================================
FAIL: test_routing_classes_use_production_safe_dimensions (test_pcb_routing_rules.PcbRoutingRulesTest.test_routing_classes_use_production_safe_dimensions)
----------------------------------------------------------------------
Traceback (most recent call last):
  File "/Users/alex/moisture-sensor/tests/test_pcb_routing_rules.py", line 36, in test_routing_classes_use_production_safe_dimensions
    self.assertEqual(set(self.classes), set(expected))
    ~~~~~~~~~~~~~~~~^^^^^^^^^^^^^^^^^^^^^^^^^^^^^^^^^^
AssertionError: Items in the first set but not the second:
'RF'

----------------------------------------------------------------------
Ran 43 tests in 1.991s

FAILED (failures=3)

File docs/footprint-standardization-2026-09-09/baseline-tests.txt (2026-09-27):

.....F...........F.................F.............
======================================================================
FAIL: test_only_bare_copper_footprints_are_model_less (test_3d_models.ModelCoverageTest.test_only_bare_copper_footprints_are_model_less)
----------------------------------------------------------------------
Traceback (most recent call last):
  File "/Users/alex/moisture-sensor/tests/test_3d_models.py", line 103, in test_only_bare_copper_footprints_are_model_less
    self.assertEqual(missing, NO_MODEL_EXPECTED)
    ~~~~~~~~~~~~~~~~^^^^^^^^^^^^^^^^^^^^^^^^^^^^
AssertionError: Items in the first set but not the second:
'TP9'
'TP13'
'TP7'
'TP8'
'TP12'
'TP5'
'TP4'
'TP6'
'TP14'
'TP15'
'TP10'
'TP11'
'TP17'
'TP16'

======================================================================
FAIL: test_probe_clamps_have_nearby_ground_vias_in_ground_plane (test_esd_return_planes.EsdReturnPlanes.test_probe_clamps_have_nearby_ground_vias_in_ground_plane)
----------------------------------------------------------------------
Traceback (most recent call last):
  File "/Users/alex/moisture-sensor/tests/test_esd_return_planes.py", line 32, in test_probe_clamps_have_nearby_ground_vias_in_ground_plane
    self.assertTrue(local, f'{ref}: no GND-plane via within 0.7 mm of clamp ground')
    ~~~~~~~~~~~~~~~^^^^^^^^^^^^^^^^^^^^^^^^^^^^^^^^^^^^^^^^^^^^^^^^^^^^^^^^^^^^^^^^^
AssertionError: [] is not true : D8: no GND-plane via within 0.7 mm of clamp ground

======================================================================
FAIL: test_routing_classes_use_production_safe_dimensions (test_pcb_routing_rules.PcbRoutingRulesTest.test_routing_classes_use_production_safe_dimensions) (netclass='SENSE')
----------------------------------------------------------------------
Traceback (most recent call last):
  File "/Users/alex/moisture-sensor/tests/test_pcb_routing_rules.py", line 46, in test_routing_classes_use_production_safe_dimensions
    self.assertEqual(actual, dimensions)
    ~~~~~~~~~~~~~~~~^^^^^^^^^^^^^^^^^^^^
AssertionError: Tuples differ: (0.25, 0.6, 0.5, 0.2) != (0.25, 0.2, 0.5, 0.2)

First differing element 1:
0.6
0.2

- (0.25, 0.6, 0.5, 0.2)
?          ^

+ (0.25, 0.2, 0.5, 0.2)
?          ^

----------------------------------------------------------------------
Ran 49 tests in 4.649s

FAILED (failures=3)

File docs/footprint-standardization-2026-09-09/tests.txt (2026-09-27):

/Users/alex/moisture-sensor/tools_netcmp.py:58: ResourceWarning: unclosed file <_io.TextIOWrapper name='/var/folders/zw/cgylqvm121j60373883z5k200000gn/T/tmpgwdfkwp3.net' mode='r' encoding='UTF-8'>
  root = parse(open(tmp).read())
ResourceWarning: Enable tracemalloc to get the object allocation traceback
/Users/alex/moisture-sensor/tools_netcmp.py:58: ResourceWarning: unclosed file <_io.TextIOWrapper name='/var/folders/zw/cgylqvm121j60373883z5k200000gn/T/tmpxpvolilg.net' mode='r' encoding='UTF-8'>
  root = parse(open(tmp).read())
ResourceWarning: Enable tracemalloc to get the object allocation traceback
======================================================================
FAIL: test_only_bare_copper_footprints_are_model_less (test_3d_models.ModelCoverageTest.test_only_bare_copper_footprints_are_model_less)
----------------------------------------------------------------------
Traceback (most recent call last):
  File "/Users/alex/moisture-sensor/tests/test_3d_models.py", line 103, in test_only_bare_copper_footprints_are_model_less
    self.assertEqual(missing, NO_MODEL_EXPECTED)
    ~~~~~~~~~~~~~~~~^^^^^^^^^^^^^^^^^^^^^^^^^^^^
AssertionError: Items in the first set but not the second:
'TP9'
'TP5'
'TP10'
'TP15'
'TP12'
'TP16'
'TP8'
'TP4'
'TP7'
'TP17'
'TP14'
'TP6'
'TP13'
'TP11'

======================================================================
FAIL: test_probe_clamps_have_nearby_ground_vias_in_ground_plane (test_esd_return_planes.EsdReturnPlanes.test_probe_clamps_have_nearby_ground_vias_in_ground_plane)
----------------------------------------------------------------------
Traceback (most recent call last):
  File "/Users/alex/moisture-sensor/tests/test_esd_return_planes.py", line 32, in test_probe_clamps_have_nearby_ground_vias_in_ground_plane
    self.assertTrue(local, f'{ref}: no GND-plane via within 0.7 mm of clamp ground')
    ~~~~~~~~~~~~~~~^^^^^^^^^^^^^^^^^^^^^^^^^^^^^^^^^^^^^^^^^^^^^^^^^^^^^^^^^^^^^^^^^
AssertionError: [] is not true : D8: no GND-plane via within 0.7 mm of clamp ground

======================================================================
FAIL: test_routing_classes_use_production_safe_dimensions (test_pcb_routing_rules.PcbRoutingRulesTest.test_routing_classes_use_production_safe_dimensions) (netclass='SENSE')
----------------------------------------------------------------------
Traceback (most recent call last):
  File "/Users/alex/moisture-sensor/tests/test_pcb_routing_rules.py", line 46, in test_routing_classes_use_production_safe_dimensions
    self.assertEqual(actual, dimensions)
    ~~~~~~~~~~~~~~~~^^^^^^^^^^^^^^^^^^^^
AssertionError: Tuples differ: (0.25, 0.6, 0.5, 0.2) != (0.25, 0.2, 0.5, 0.2)

First differing element 1:
0.6
0.2

- (0.25, 0.6, 0.5, 0.2)
?          ^

+ (0.25, 0.2, 0.5, 0.2)
?          ^

----------------------------------------------------------------------
Ran 49 tests in 4.807s

FAILED (failures=3)

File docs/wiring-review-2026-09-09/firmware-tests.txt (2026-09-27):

sensor: measurements, CRC, range, bounded waits and bus-fault cleanup passed

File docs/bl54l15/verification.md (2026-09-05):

# Verification — BL54L15 routing handoff

Checked 2026-09-04 using KiCad CLI 10.99, file format 20260828, with the
repository's existing ERC/DRC configuration. Zones were refilled and saved
before checking and exporting. No new rule exclusions were added to hide
violations. This is a routing handoff at Alex's request, **not a fabrication
release**. No boards or components were ordered.

## Check results

| Check | Snapshot before migration | BL54L15 handoff |
|---|---:|---:|
| ERC errors | 0 | **0** |
| ERC warnings | 24 | **11** |
| Physical DRC errors | 13: 9 width, 4 clearance | **0** |
| Unconnected items (DRC errors) | 6 | **15**, deliberate routing handoff |
| PCB warnings | 49 | **18** |
| Schematic/PCB parity differences | 0 | **0** |
| Repository tests | — | **34 passed** |

Reports: [ERC](erc.json), [DRC with each missing endpoint](drc.json),
[baseline ERC](baseline-erc.json), [baseline DRC](baseline-drc.json),
[test output](tests.txt), [preservation checks](preservation.json).
Earlier audit/checklist counts refer to different intermediate board states;
the baseline above was taken from the actual dirty working tree immediately
before this migration.

All 11 ERC warnings are retained library-symbol differences (C3, C13,
C21–C28 and U2), present in the baseline. The tiny dangling schematic wire and
its orphan label were removed. Current PCB warnings comprise 11 retained
footprint-library differences, the preexisting R22/R23 silkscreen clearance,
and six newly exposed dangling route anchors from disconnecting the old MCU
fanout, intentionally retained for hand routing. New
module silkscreen clipping/overlap warnings were resolved. There are no new
physical DRC errors; the outstanding error category is unrouted connections.

The project already disables missing courtyard, off-center track/via,
tuning-profile geometry, footprint-filter and footprint-type checks. ERC also
has its preexisting single-global-label, four-way-junction, simulation and
footprint-filter checks disabled. These settings are listed in the JSON
reports and were preserved; a zero error count is under those project rules.
U1 itself has a courtyard and its LGA land pattern is explicitly checked.

## Connectivity and preservation

- Verified every used U1 pad against the Ezurio pin table: 26 VDD;
  1/16/27/39 GND; 25/24 XL1/XL2; 35/28 SCL/SDA; 17 PMIC_INT;
  4 SWO; 5/6 SWDIO/SWDCLK; 7 nRESET. Other 25 module GPIO pads are NC.
- Preserved all firmware GPIO assignments and reset/programming topology.
- Netlist comparison removes only the retired parts and replaced U1 from each
  snapshot, then compares complete remaining node groups: **26 groups identical**.
- **19 retained footprint placements** and **all 40 outline primitives** match
  the starting PCB. Only U1, C3, X1, R1 and C13 were replaced/repositioned.
- Current netlist fingerprint has **51 entries**, including explicit NC pins.
  Obsolete RF, DCC/DECD/DECA and XC1/XC2 nets are absent.
- Tests check all 39 land centers, pad size/layers, assigned signal pads,
  deletion of obsolete components, four-layer antenna rule areas, JLC exclusion,
  separate paste stages, full-product DigiKey metadata, and retained project
  power/sensing/routing/model/generator-safety invariants.

## Visual inspection

Inspected actual KiCad-generated front copper and all three other copper layers
around U1: no host copper in the antenna rule areas, continuous In1 ground under
the electronics and pin-1 land strip, nearby ground vias, local X1/C3 wiring and
no new courtyard/clearance violations. Reviewed module pin labels, common GND
connection, external-support notes, DNP assembly-stage note and the updated
schematic drawing. The module body/keepout annotation in the placement image is
derived from the actual board geometry; the underlying copper is KiCad output.

- [Annotated final placement](placement.png)
- [Front mask — only intended lands exposed under U1](F_Mask.png)
- [Front copper](F_Cu.png), [In1 ground](GND.png), [In2 power](PWR-SHLD.png), [back copper](B_Cu.png)
- [Schematic module detail](schematic-module.png)

The footprint's 3D model is a nominal 14 × 10 × 1.6 mm envelope, not detailed
vendor geometry. Enclosure RF performance and thermal process cannot be
established from these drawings. Existing SHT45/holder positions and enclosure
outline were preserved; no physical assembly was performed.

## Remaining work

Finish the 15 connections and remove unused route anchors. Refill and require
zero unconnected items; reconcile library warnings and R22/R23 silk before fab.
Qualify the module supply's 10 mV noise/ripple limit, total effective converter
load capacitance, X1/HFXO trim/startup, timed System OFF wake, and hot-air LGA
attachment. The fixed battery/enclosure geometry does not meet all preferred
manufacturer metal-separation distances; closed-enclosure radiated testing or
a mechanical revision remains necessary. C23 bias and C26/C27/C28 order codes,
plus exact BT1 assembly sourcing, are retained open BOM issues.

The review manufacturing output is regenerated by
[tools_export_bl54l15.py](../../tools_export_bl54l15.py), with source hashes in
`production/bl54l15-routing-review/source-sha256.json`. U1 is included in the
20-component product BOM, excluded from the 19-placement JLC BOM/CPL and JLC
paste, and present as 39 apertures in the separate manual-paste stage.

## Current unconnected endpoints

| From | To |
|---|---|
| Pad 1 [/NRESET] of C13 on F.Cu (82.800, 56.980 mm) | Pad 1 [/NRESET] of R1 on F.Cu (83.990, 55.500 mm) |
| Pad 1 [/NRESET] of R1 on F.Cu (83.990, 55.500 mm) | Pad 7 [/NRESET] of U1 on F.Cu (81.497, 46.700 mm) |
| Pad 2 [/SWD_RST] of R1 on F.Cu (85.010, 55.500 mm) | Track [/SWD_RST] on F.Cu, length 2.0640 mm (85.040, 58.725 mm) |
| Pad 1 [+3V3] of R22 on F.Cu (68.403, 60.000 mm) | Pad 1 [+3V3] of R23 on F.Cu (68.403, 61.000 mm) |
| Pad 1 [+3V3] of R22 on F.Cu (68.403, 60.000 mm) | Track [+3V3] on F.Cu, length 2.9345 mm (74.000, 54.425 mm) |
| Pad 1 [+3V3] of R23 on F.Cu (68.403, 61.000 mm) | Track [+3V3] on F.Cu, length 1.3975 mm (67.832, 68.200 mm) |
| Via [+3V3] on F.Cu - B.Cu (91.800, 63.282 mm) | Pad 1 [+3V3] of J4 on F.Cu (84.665, 62.760 mm) |
| Pad 2 [/SCL] of R23 on F.Cu (69.597, 61.000 mm) | Track [/SCL] on B.Cu, length 3.1070 mm (72.197, 68.803 mm) |
| Pad 2 [/SCL] of R23 on F.Cu (69.597, 61.000 mm) | Pad 35 [/SCL] of U1 on F.Cu (72.503, 48.200 mm) |
| Pad 2 [/SDA] of R22 on F.Cu (69.597, 60.000 mm) | Track [/SDA] on B.Cu, length 2.4042 mm (71.100, 68.500 mm) |
| Pad 28 [/SDA] of U1 on F.Cu (72.503, 53.450 mm) | Pad 2 [/SDA] of R22 on F.Cu (69.597, 60.000 mm) |
| Pad 5 [/SWDIO] of U1 on F.Cu (81.497, 45.200 mm) | Pad 2 [/SWDIO] of J4 on F.Cu (84.665, 64.030 mm) |
| Pad 6 [/SWDCLK] of U1 on F.Cu (81.497, 45.950 mm) | Pad 4 [/SWDCLK] of J4 on F.Cu (84.665, 66.570 mm) |
| Pad 4 [/P2.07_SWO] of U1 on F.Cu (81.497, 44.450 mm) | Pad 6 [/P2.07_SWO] of J4 on F.Cu (85.935, 67.840 mm) |
| Track [/PMIC_INT] on B.Cu, length 26.3750 mm (80.300, 87.775 mm) | Pad 17 [/PMIC_INT] of U1 on F.Cu (80.750, 53.500 mm) |

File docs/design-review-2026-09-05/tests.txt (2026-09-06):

...........................................                                                         [100%]
43 passed, 261 subtests passed in 1.92s

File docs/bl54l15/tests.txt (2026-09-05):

test_all_referenced_model_files_exist (test_3d_models.ModelCoverageTest.test_all_referenced_model_files_exist) ... ok
test_custom_footprints_keep_their_models (test_3d_models.ModelCoverageTest.test_custom_footprints_keep_their_models) ... ok
test_incompatible_downloaded_packages_are_not_kept (test_3d_models.ModelCoverageTest.test_incompatible_downloaded_packages_are_not_kept) ... ok
test_model_tools_do_not_reference_retired_packages (test_3d_models.ModelCoverageTest.test_model_tools_do_not_reference_retired_packages) ... ok
test_only_bare_copper_footprints_are_model_less (test_3d_models.ModelCoverageTest.test_only_bare_copper_footprints_are_model_less) ... ok
test_selected_models_are_on_the_component_side (test_3d_models.ModelCoverageTest.test_selected_models_are_on_the_component_side) ... ok
test_selected_parts_use_one_expected_model_each (test_3d_models.ModelCoverageTest.test_selected_parts_use_one_expected_model_each) ... ok
test_symbol_library_table_only_lists_current_project_libraries (test_3d_models.ModelCoverageTest.test_symbol_library_table_only_lists_current_project_libraries) ... ok
test_all_land_centers_and_antenna_rules (test_bl54l15.BL54L15Test.test_all_land_centers_and_antenna_rules) ... ok
test_module_pads_preserve_product_signals (test_bl54l15.BL54L15Test.test_module_pads_preserve_product_signals) ... ok
test_vendor_land_pattern (test_bl54l15.BL54L15Test.test_vendor_land_pattern) ... ok
test_paste_stages_are_disjoint (test_bl54l15_exports.ModuleAssemblyExportTest.test_paste_stages_are_disjoint) ... ok
test_product_bom_retains_separately_ordered_module (test_bl54l15_exports.ModuleAssemblyExportTest.test_product_bom_retains_separately_ordered_module) ... ok
test_leaves_already_clean_segment_unchanged (test_clean_track_angles.CleanTrackAnglesTests.test_leaves_already_clean_segment_unchanged) ... ok
test_splits_off_angle_segment_into_axial_and_diagonal_legs (test_clean_track_angles.CleanTrackAnglesTests.test_splits_off_angle_segment_into_axial_and_diagonal_legs) ... ok
test_all_route_legs_are_axial_or_45_degrees (test_finish_routes.FinishRoutesTests.test_all_route_legs_are_axial_or_45_degrees) ... ok
test_insertion_is_idempotent (test_finish_routes.FinishRoutesTests.test_insertion_is_idempotent) ... ok
test_retired_board_helpers_exit_without_modifying_the_board (test_generator_safety.GeneratorSafetyTest.test_retired_board_helpers_exit_without_modifying_the_board) ... ok
test_retired_schematic_generator_exits_without_modifying_schematic (test_generator_safety.GeneratorSafetyTest.test_retired_schematic_generator_exits_without_modifying_schematic) ... ok
test_generated_bom_omits_non_purchasable_footprints (test_jlc_bom.JlcBomTest.test_generated_bom_omits_non_purchasable_footprints) ... ok
test_bare_copper_footprints_are_excluded_from_assembly_outputs (test_pcb_assembly_flags.PcbAssemblyFlagsTest.test_bare_copper_footprints_are_excluded_from_assembly_outputs) ... ok
test_retired_board_generator_exits_without_modifying_the_board (test_pcb_assembly_flags.PcbAssemblyFlagsTest.test_retired_board_generator_exits_without_modifying_the_board) ... ok
test_every_connected_net_has_an_explicit_class (test_pcb_routing_rules.PcbRoutingRulesTest.test_every_connected_net_has_an_explicit_class) ... ok
test_hole_spacing_matches_jlcpcb_four_layer_capability (test_pcb_routing_rules.PcbRoutingRulesTest.test_hole_spacing_matches_jlcpcb_four_layer_capability) ... ok
test_retired_power_nets_are_not_assigned (test_pcb_routing_rules.PcbRoutingRulesTest.test_retired_power_nets_are_not_assigned) ... ok
test_router_does_not_reference_retired_switch_net (test_pcb_routing_rules.PcbRoutingRulesTest.test_router_does_not_reference_retired_switch_net) ... ok
test_routing_classes_use_production_safe_dimensions (test_pcb_routing_rules.PcbRoutingRulesTest.test_routing_classes_use_production_safe_dimensions) ... ok
test_keeps_routes_protected_by_default (test_prepare_freerouting.PrepareFreeroutingTests.test_keeps_routes_protected_by_default) ... ok
test_removes_exported_polygon_wires (test_prepare_freerouting.PrepareFreeroutingTests.test_removes_exported_polygon_wires) ... ok
test_unlocks_only_noncritical_routes (test_prepare_freerouting.PrepareFreeroutingTests.test_unlocks_only_noncritical_routes) ... ok
test_legacy_net_names_are_absent_from_design_sources (test_rf_design.RfDesignTest.test_legacy_net_names_are_absent_from_design_sources) ... ok
test_new_net_names_observe_kicad_root_sheet_scope (test_rf_design.RfDesignTest.test_new_net_names_observe_kicad_root_sheet_scope) ... ok
test_orderable_jlc3313_stackup_is_recorded_exactly (test_rf_design.RfDesignTest.test_orderable_jlc3313_stackup_is_recorded_exactly) ... ok
test_switched_fdc_rail_and_i2c_pullups (test_rf_design.RfDesignTest.test_switched_fdc_rail_and_i2c_pullups) ... ok

----------------------------------------------------------------------
Ran 34 tests in 0.901s

OK

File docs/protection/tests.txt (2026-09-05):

......................................
----------------------------------------------------------------------
Ran 38 tests in 0.954s

OK

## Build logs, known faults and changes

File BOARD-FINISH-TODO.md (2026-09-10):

> 2026-09-09 cost revision: U4 is now Sensirion SHT40-AD1F-R2. The existing SHT4x footprint, membrane handling, geometry, and legacy SHT45-named model/rule areas are retained. See [cost revision](docs/cost-reduction-2026-09-09/README.md).

# nRF Moisture Sensor — completion checklist

Current fabrication handoff: [2026-09-09 verified files and order notes](production/fab-2026-09-09/README.md).
Routing has zero unconnected items, zero unaccepted DRC errors and zero parity issues.
The user accepted the two +3V3 vias in the GND-via exclusion corridor. Fresh
Gerbers, drills, BOM/CPL, separate manual-module stencil and assembly drawings
are in that handoff directory. No order has been placed.
C26–C28 order codes are populated; C21/C23 effective-capacitance qualification remains open.
The older routing handoff below is retained as history; the current review takes precedence.

# Board completion checklist — BL54L15 routing handoff

Current source is the actual KiCad schematic/PCB. Use CLI or GUI as appropriate,
as authorized by Alex. Do not run the retired full-board/schematic generators.
Preserve unrelated edits. The previous checklist is preserved in
[history](docs/bl54l15/history/BOARD-FINISH-before.md).

- [x] Replace bare U1 with Ezurio 453-00001R, verified 39-pad symbol/land pattern.
- [x] Remove obsolete RF, DCDC and 32 MHz host parts/nets; retain external X1.
- [x] Preserve GPIO assignments, nPM2100, CR2032, FDC1004, SHT45 and J4.
- [x] Place module on board edge; implement all-layer antenna keepouts and grounds.
- [x] Separate complete-product BOM from JLC DNP/position/paste outputs.
- [x] Run ERC, physical DRC, parity, repository checks and visual review; see
      [the current results](docs/bl54l15/verification.md).
- [x] Finish remaining digital/power routing and remove abandoned anchors.
      Preserve X1/C3 local routes and antenna keepouts. Refill; require zero
      unconnected items and no new physical DRC errors.
- [ ] Reconcile existing library mismatch warnings and R22/R23 silk overlap.
- [ ] Qualify C21/C23 effective capacitance and module VOUT loading. C26–C28 and BT1 now have source selections.
- [ ] Implement production firmware clock configuration and HP-mode radio windows.
- [ ] Qualify ≤10 mV module VDD ripple/noise, total effective VOUT capacitance,
      cold start, low-battery bursts, clock startup/trim and timed System OFF wake.
- [ ] Validate module hot-air assembly profile without overheating SHT45/PTFE.
- [ ] Resolve or qualify the enclosure metal-spacing shortfall through radiated
      testing with installed battery and lid; DRC does not establish RF compliance.
- [ ] Complete probe insertion mark, capillary barrier, coating mask and sealing;
      preserve the IP54 target, sensor opening and battery removal access.
- [x] Re-export and visually approve final Gerbers/drills/BOM/positions/stencils,
      source hashes and assembly drawings after routing. Do not order automatically.
- [ ] Measure current/life, coated-probe calibration, humidity response and ingress.

## Protection revision

- [x] Q1 reverse-battery PMOS; battery/debug/probe ESD clamps and series isolation.
- [x] Zero new physical DRC errors and zero parity issues; original 15 missing module connections remain.
- [ ] Qualify ESD/leakage, low-cell startup, SWD and sensing with the new parts.
- [x] Move D1 to front PCBA; refine holder courtyard and install TI diode STEP model.
- [ ] Do not claim sustained OVP or a battery fuse; neither is fitted.

See [protection report](docs/protection/README.md) for current details.

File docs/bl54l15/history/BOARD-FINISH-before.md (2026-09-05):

# Board completion checklist

Work through in order; update results after each verified batch. Design edits use
KiCad's live GUI. Shell/CLI use is for read-only analysis, backups, checks and
documentation. Never run the retired board/schematic generators. Save in KiCad
before running checks; synchronize schematic changes through Update PCB from
Schematic. Preserve the existing dirty working tree.

## 1. Parts and reference baseline — in progress

- [ ] Confirm nRF54L15-QFAA-R7 production reference/silicon compatibility.
- [ ] Confirm exact footprint sizes for Nordic support components.
- [x] Record current backups and initial ERC/DRC/parity.

## 2. Local nRF placement

- [x] Restore standard 0201 C1/C2/C4/C5/C7/C8/C10/C12/C13 and FB1/R1 footprints;
      standard 0402 C3 and 0603 L1. Update schematic assignments first.
- [ ] Move C1 next to DECD, C2/C12/FB1 next to DECA, C5 next to DECRF,
      and C10 next to VDD47/48; provide short ground returns.
- [x] Move I2C pull-ups out of the local power/oscillator placement area as needed.
- [ ] Re-place X2 for short single-layer XC1/XC2 routing with grounded case pads.
- [x] Check courtyards, clearances, netlist identity and schematic/PCB parity.
      These checks pass at handoff; placement still needs routing validation.

## 3. Route critical local connections

- [x] Configure GUI interactive router for shove/walk-around and H/V/45 routing.
- [ ] Route nRF internal power/filter nets first; minimize loops and vias.
- [ ] Route XC1/XC2 on F.Cu without signal vias; preserve crystal pin numbering.
- [ ] Refill planes and pass DRC/connectivity after the local batch.

## 4. RF review

- [ ] Compare matching geometry and inner-plane cutouts against the selected reference.
- [ ] Preserve C6 → VSS_PA and C9 bottom-only grounding.
- [ ] Verify C11 local ground and controlled-impedance R27/AE1 feed and all-layer antenna keepout.
- [ ] Confirm fab stack/impedance geometry and enclosure antenna/coax clearance.

## 5. Remaining routing

- [ ] Improve PMIC VINT/PVSS capacitor loop if placement permits.
- [ ] Clean up digital routes with the interactive router: avoid unnecessary vias,
      acute corners, short jogs and detours; keep the In1 reference intact.
- [ ] Preserve driven shielding and separation around sensing routes.
- [ ] Verify SHT45 and FDC bypass routing and thermal/copper keepouts.

## 6. Manufacturing checks

- [ ] Reconcile library symbol and footprint differences deliberately.
- [ ] Remove dangling schematic wire and repair silkscreen warnings.
- [ ] Verify all 3D models, courtyards, battery removal and programming access.
- [ ] Final ERC, DRC, zero unrouted, zero parity, netlist fingerprint and repo checks.

## 7. BOM and release package

- [ ] Lock critical capacitor/inductor MPNs and effective capacitance at bias/temperature.
- [ ] Finish insertion mark/stop, probe edge sealing, coating mask and assembly notes.
- [ ] Validate mechanical enclosure/antenna fit.
- [ ] Generate and visually review Gerbers, drills, position files, BOM and assembly drawings.
- [ ] Record final source hashes and release status; do not order automatically.

## 8. Physical prototype validation

- [ ] Verify boot/PMIC sequencing and low-battery radio bursts with aged-cell impedance.
- [ ] Measure sleep/active current and estimate life from measured duty cycle.
- [ ] Check oscillator startup/trim and RF performance in the final enclosure.
- [ ] Calibrate the coated probe in representative soil; check range and shield loading.
- [ ] Verify humidity response, moisture ingress and long-term stability.

## Session log

- 2026-09-04: Starting from the completed audit bypass corrections. Baseline copied
  to `tmp/board-finish/baseline/`. Previous check: 0 DRC errors, 18 warnings,
  0 unrouted, 0 parity, 0 ERC errors, 23 ERC warnings, 35 repository checks passed.
- 2026-09-04 handoff: GUI routing stopped after unreliable canvas interaction made
  precise routing impractical. Saved and refilled in KiCad. Current DRC: 7
  track-width errors, 3 missing connections, 47 warnings; no courtyard overlaps,
  shorts or clearance errors reported. Netlist identity (62 nets), schematic/PCB
  parity and all 35 repository checks pass. This is an incomplete routing state,
  not a fabrication release. Finish the exact routes and cleanup in
  [the routing handoff](docs/board-routing-handoff-2026-09-04.md) before continuing
  with RF review and the remaining checklist. Placement changes are provisional
  until those routes pass DRC.

- [ ] Tune AE1/R27/C29 in the assembled enclosure; approve radiated performance
  and changed radiator-to-battery spacing. See LAYOUT.md §3.

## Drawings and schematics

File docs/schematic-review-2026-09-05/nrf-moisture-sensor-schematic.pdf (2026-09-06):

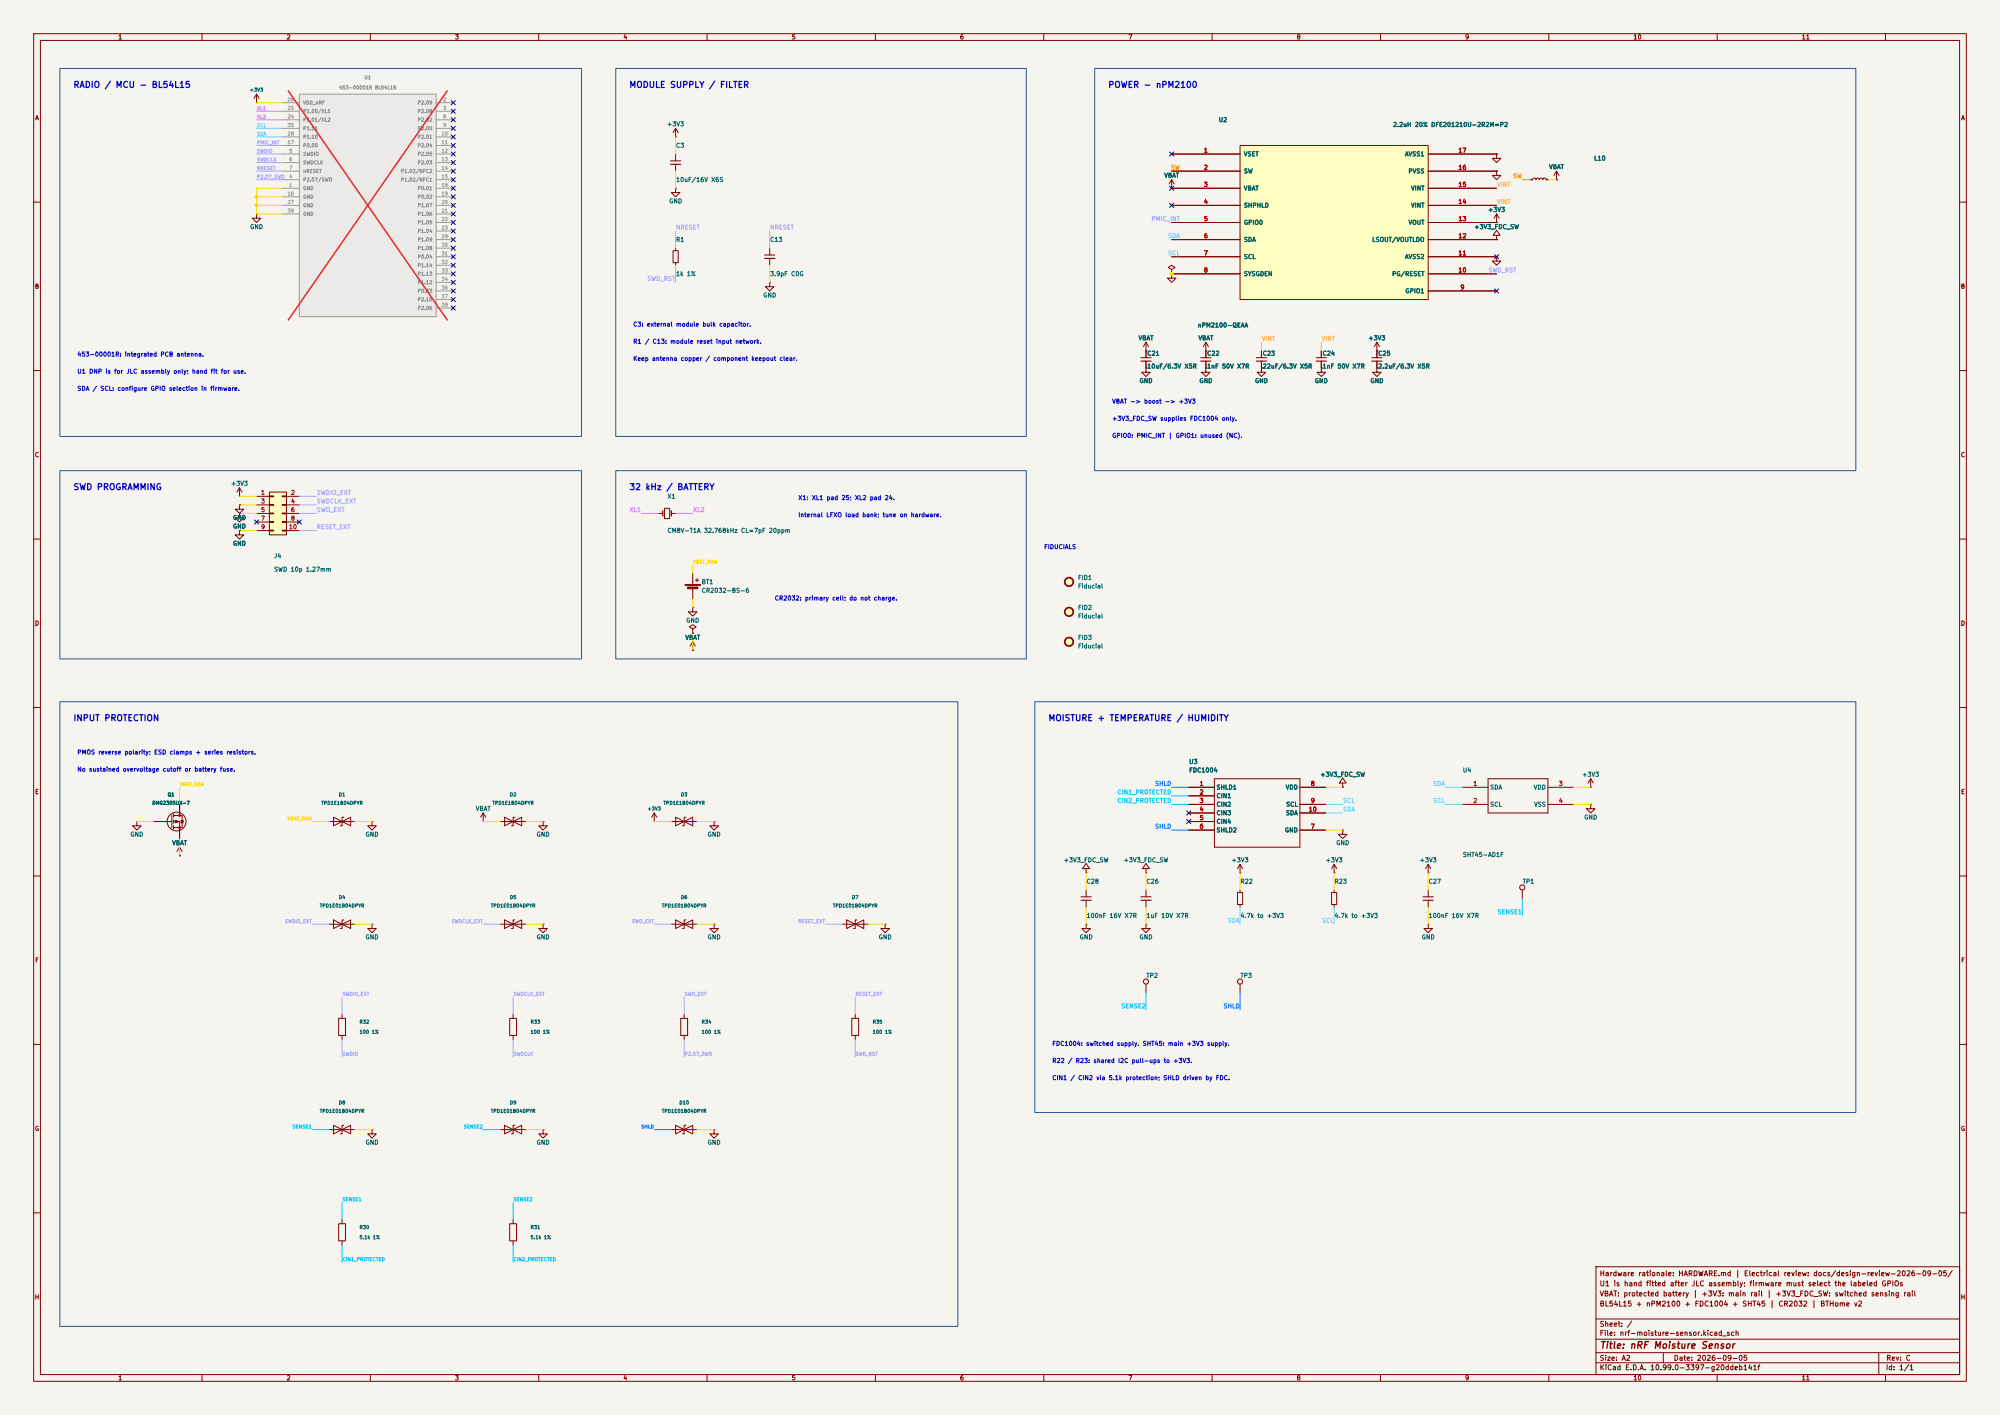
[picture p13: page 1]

SDA / SCL: configure GPIO selection in firmware. No sustained overvoltage cutoff or battery fuse.

U1 DNP is for JLC assembly only; hand fit for use. SWD PROGRAMMING

GPIO0: PMIC_INT | GPIO1: unused (NC). +3V3_FDC_SW supplies FDC1004 only. VBAT -> boost -> +3V3

Internal LFXO load bank; tune on hardware. X1: XL1 pad 25; XL2 pad 24. CR2032: primary cell; do not charge.

Hardware rationale: HARDWARE.md | Electrical review: docs/design-review-2026-09-05/
U1 is hand fitted after JLC assembly; firmware must select the labeled GPIOs
VBAT: protected battery | +3V3: main rail | +3V3_FDC_SW: switched sensing rail
BL54L15 + nPM2100 + FDC1004 + SHT45 | CR2032 | BTHome v2

Sheet: /
File: nrf-moisture-sensor.kicad_sch
Title: nRF Moisture Sensor

Size: A2 | Rev: C
KiCad E.D.A. 10.99.0-3397-g20ddeb141f | Id: 1/1

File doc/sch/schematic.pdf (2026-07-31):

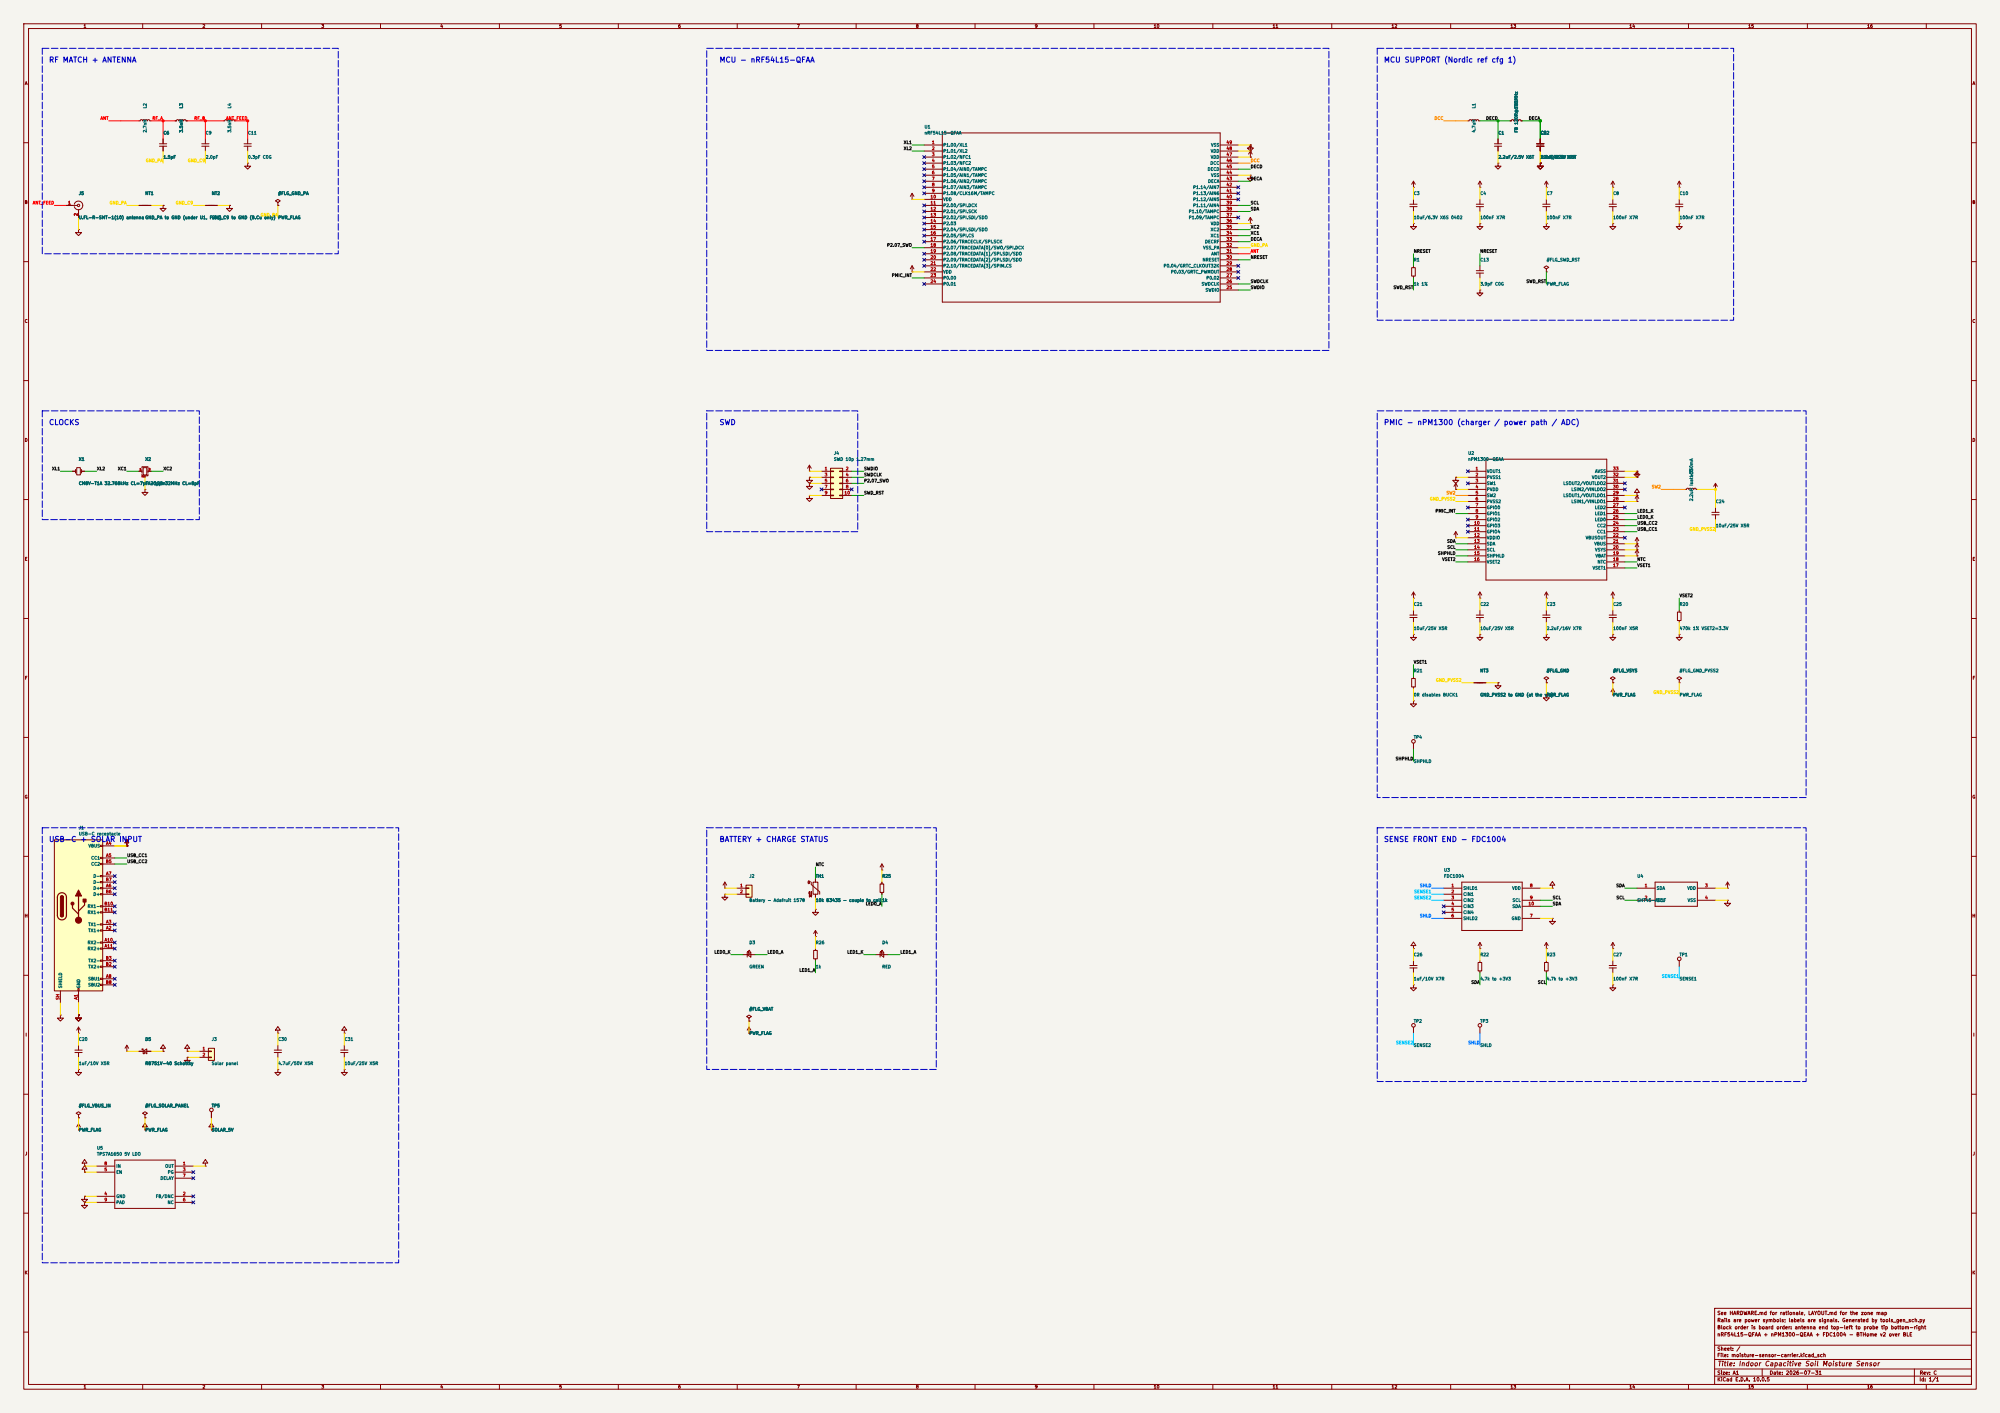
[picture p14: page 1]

2 NT1 GND_PA to GND (under U1, F.Cu) NT2 GND_C9 to GND (B.Cu only)

3.9pF C0G NT2 GND_C9 to GND (B.Cu only)

PWR_FLAG NT3 GND_PVSS2 to GND (at the via)

NT3 GND_PVSS2 to GND (at the via)

See HARDWARE.md for rationale, LAYOUT.md for the zone map
Rails are power symbols; labels are signals. Generated by tools_gen_sch.py
Block order is board order: antenna end top-left to probe tip bottom-right
nRF54L15-QFAA + nPM1300-QEAA + FDC1004 - BTHome v2 over BLE

Sheet: /
File: moisture-sensor-carrier.kicad_sch
Title: Indoor Capacitive Soil Moisture Sensor

Size: A1 | Rev: C
KiCad E.D.A. 10.0.5 | Id: 1/1

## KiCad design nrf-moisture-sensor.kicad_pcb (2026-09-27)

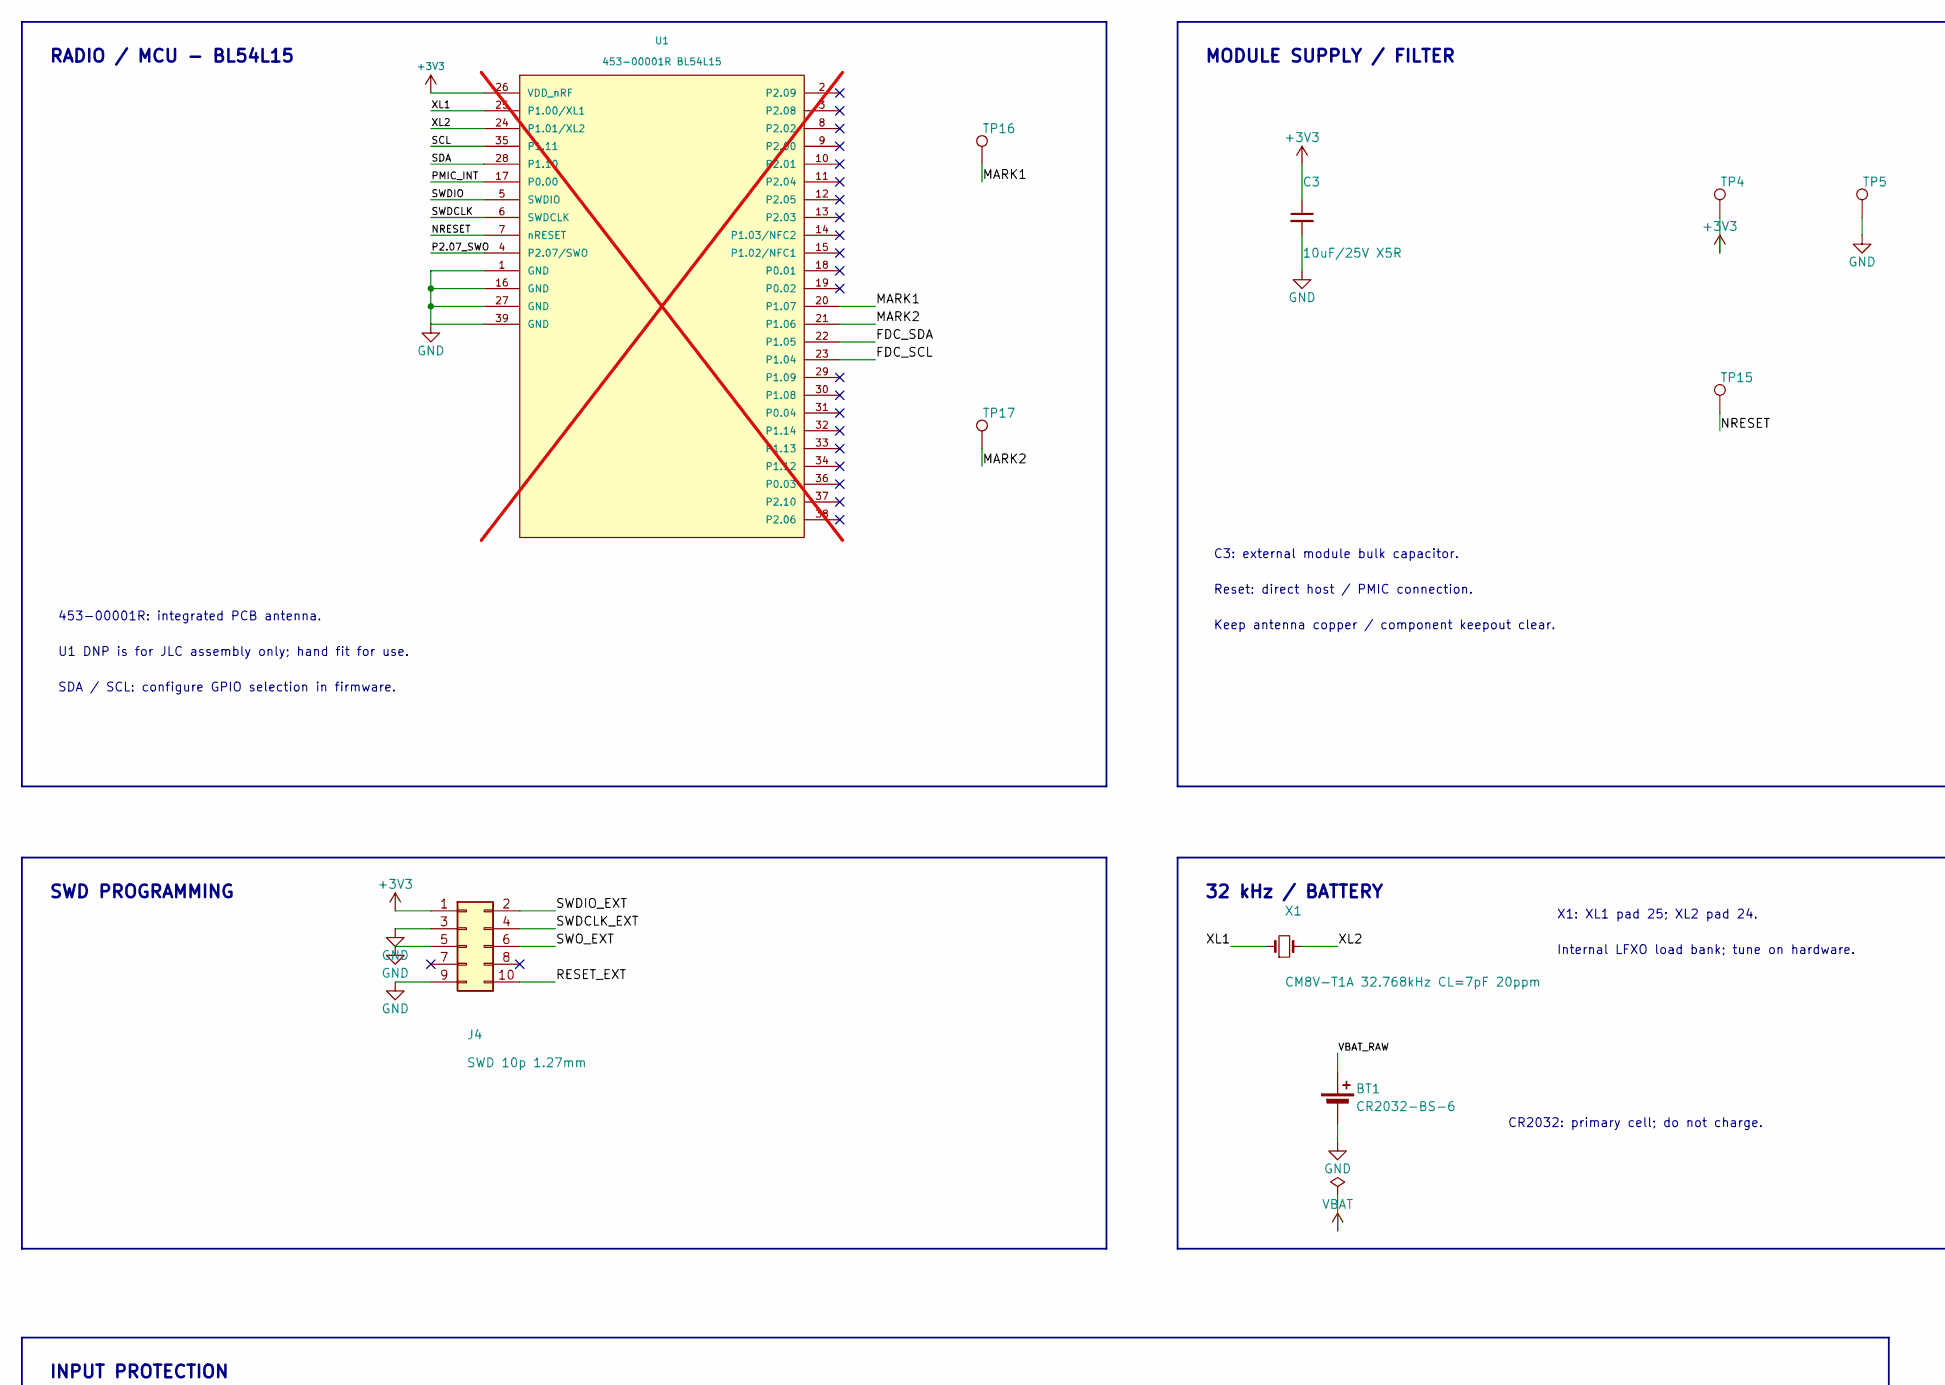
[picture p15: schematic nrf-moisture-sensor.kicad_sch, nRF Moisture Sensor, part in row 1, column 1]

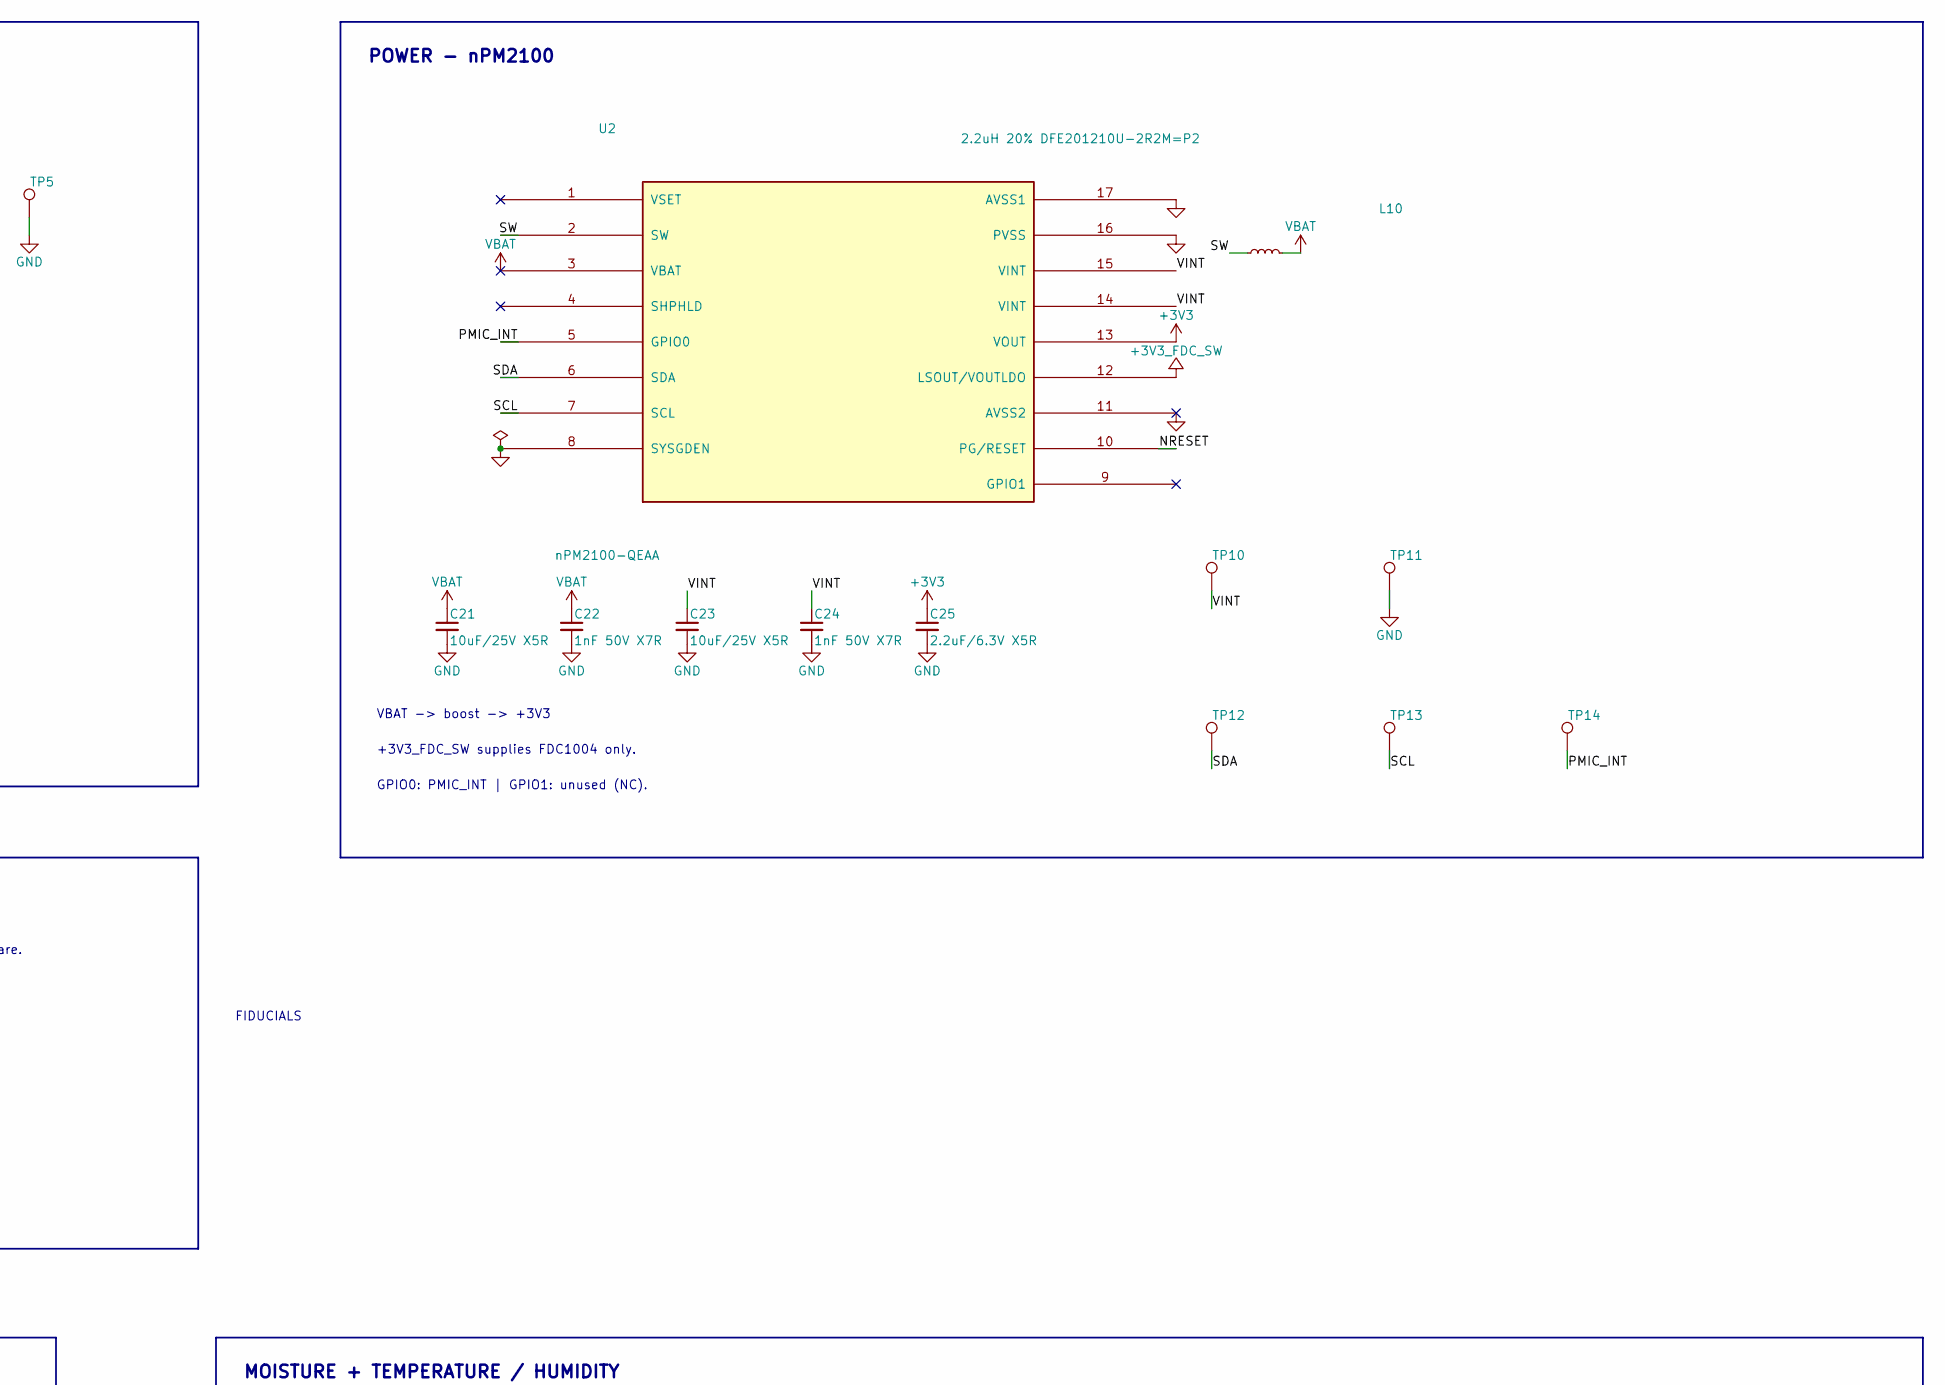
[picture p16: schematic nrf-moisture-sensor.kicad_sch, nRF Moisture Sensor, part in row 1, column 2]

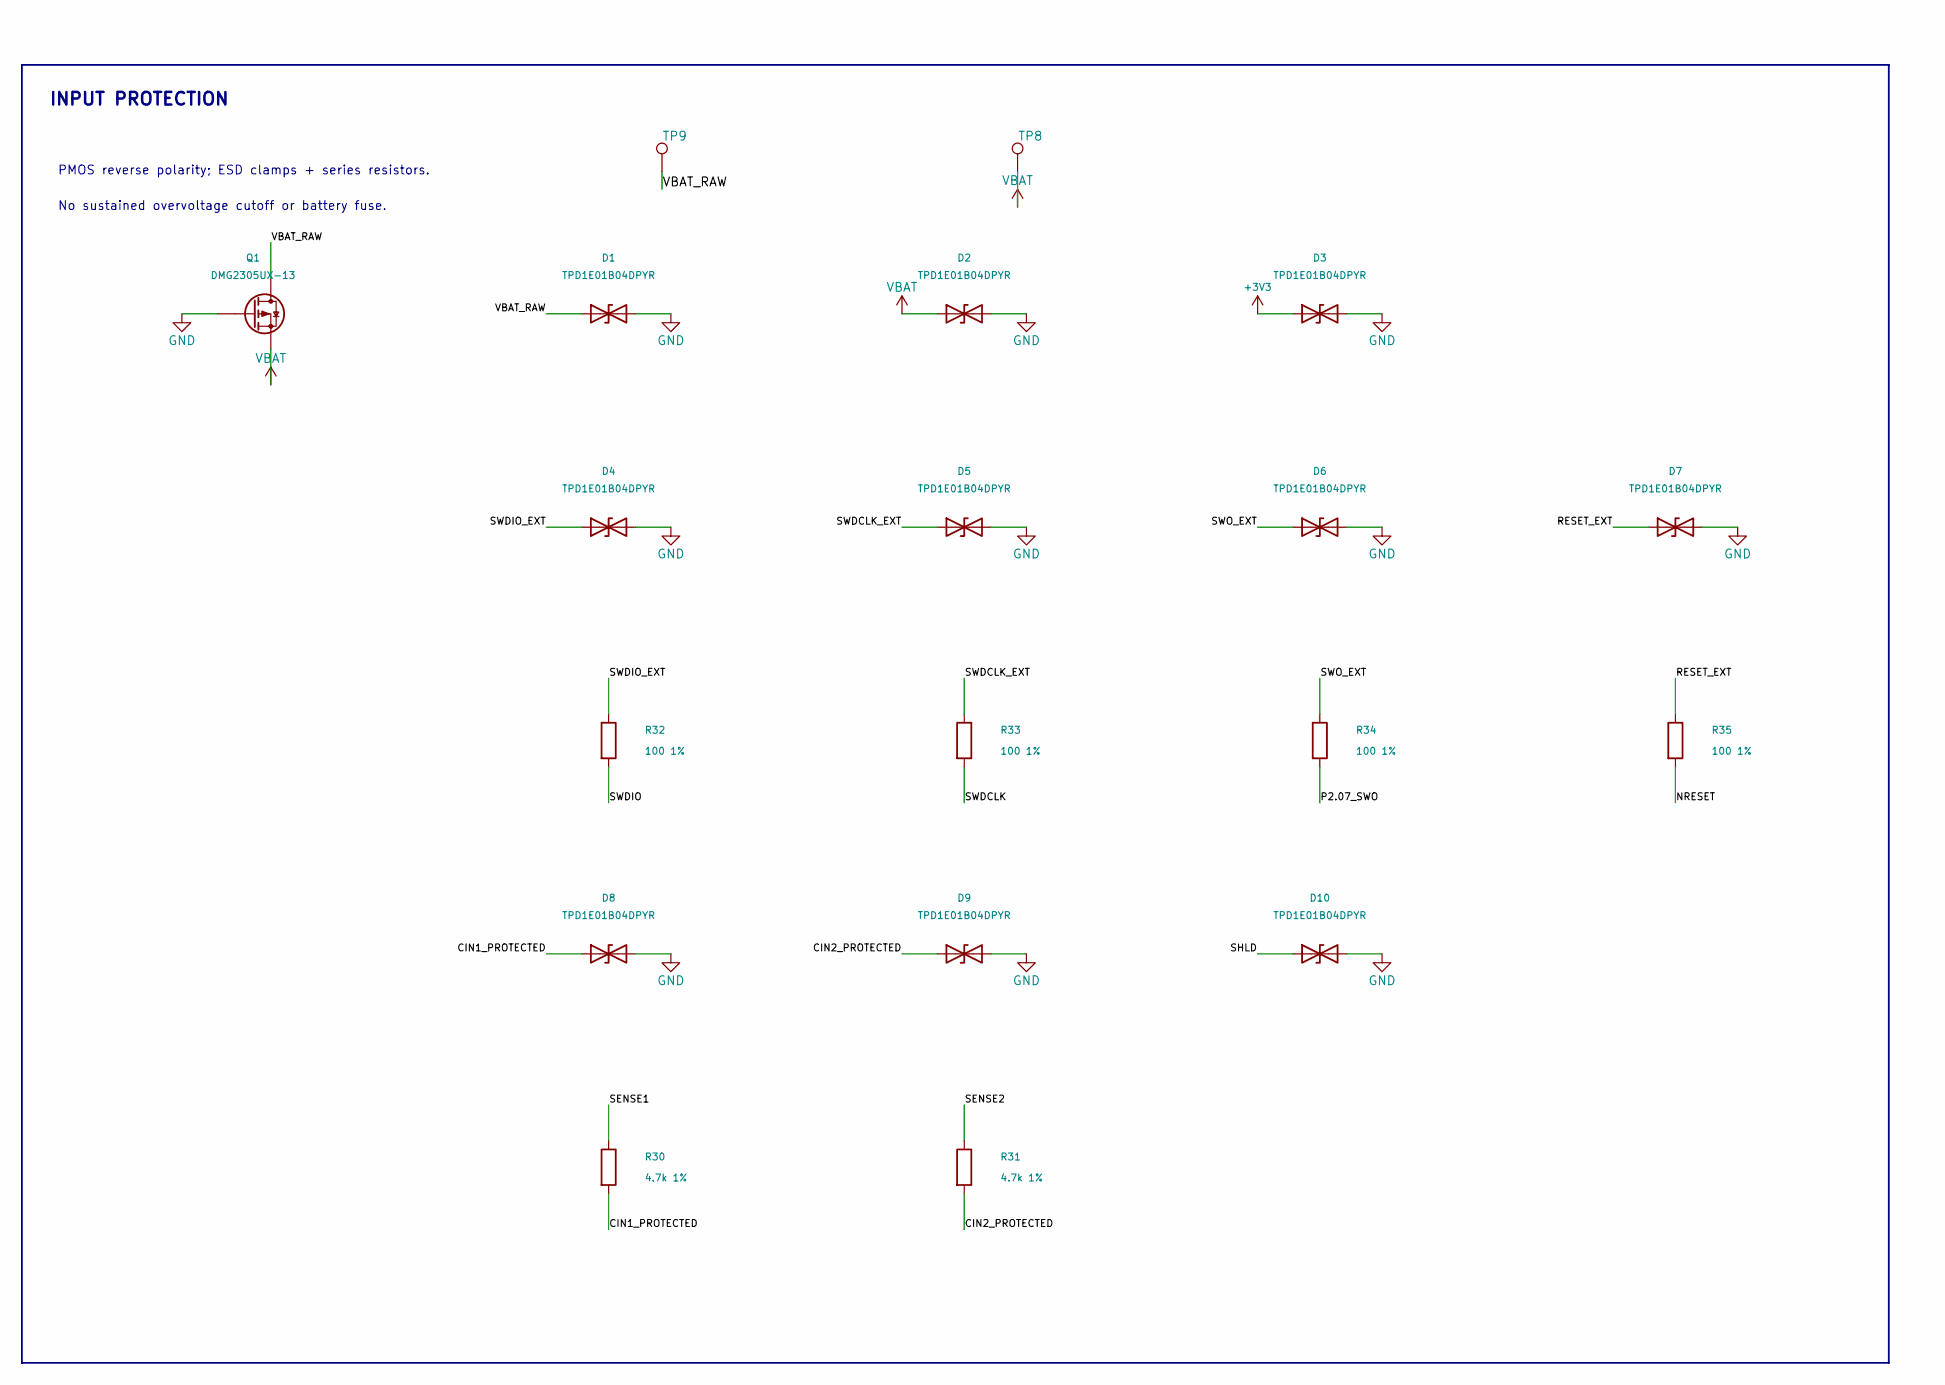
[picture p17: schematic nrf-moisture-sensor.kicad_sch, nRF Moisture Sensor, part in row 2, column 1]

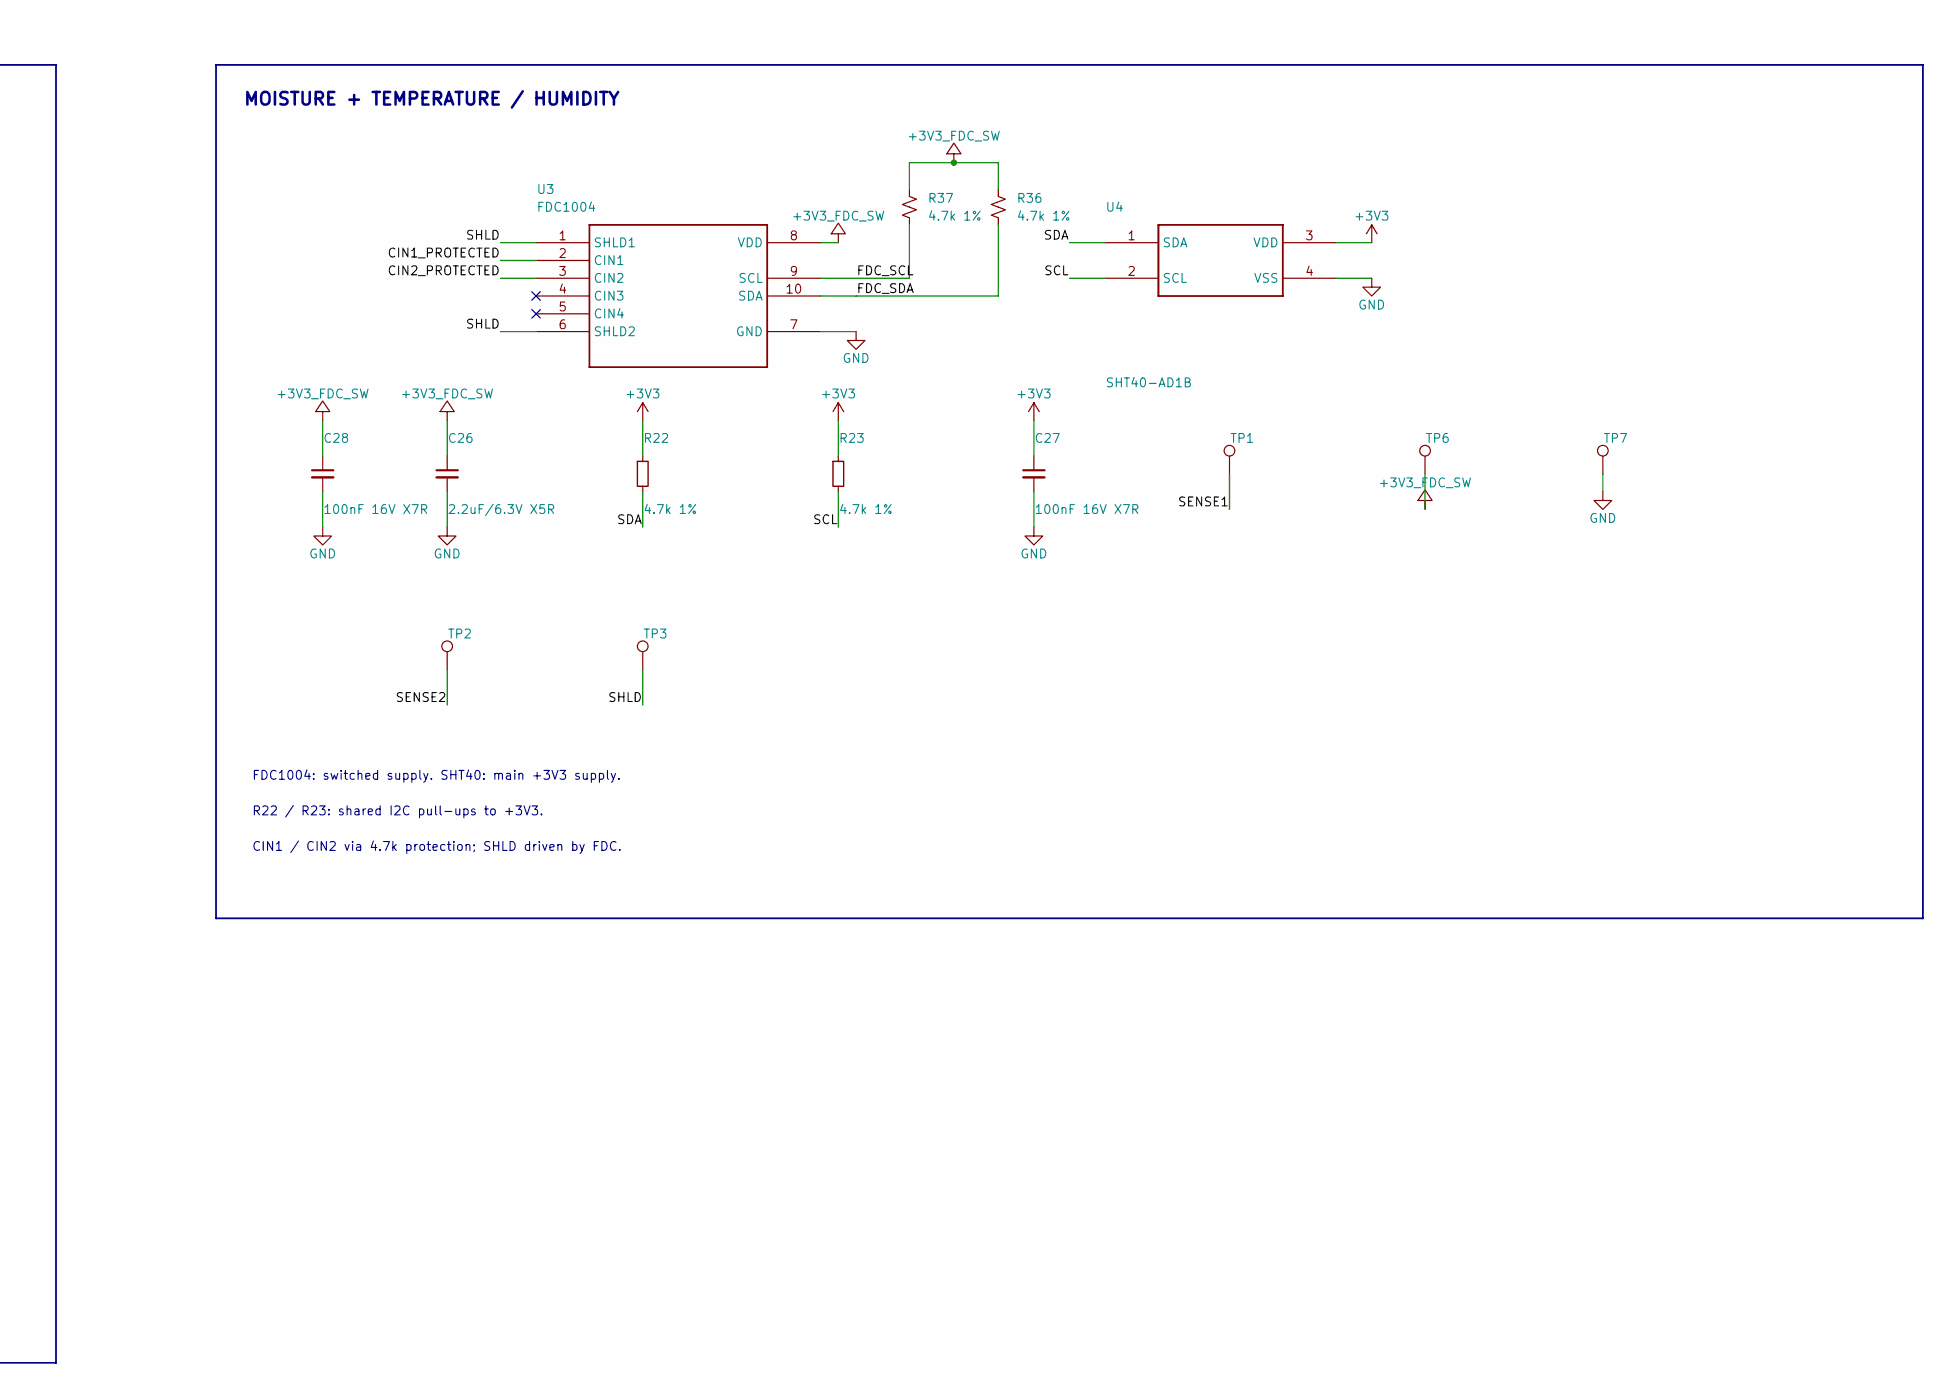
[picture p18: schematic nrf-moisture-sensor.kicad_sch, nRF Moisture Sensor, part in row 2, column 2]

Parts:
BT1: CR2032-BS-6; BatteryHolder_LianXin_CR2032-BS-6; MPN CR2032-BS-6; LCSC C22363833
C3, C21, C23: 10uF/25V X5R; C_0603_1608Metric; MPN CL10A106MA8NRNC; LCSC C96446
C22, C24: 1nF 50V X7R; C_0402_1005Metric; MPN 0402B102K500NT; LCSC C1523
C25, C26: 2.2uF/6.3V X5R; C_0402_1005Metric; MPN CL05A225MQ5NSNC; LCSC C12530
C27, C28: 100nF 16V X7R; C_0402_1005Metric; MPN CL05B104KO5NNNC; LCSC C1525
D1, D2, D3, D4, D5, D6, D7, D8, D9, D10: TPD1E01B04DPYR; Texas_DPY0002A_0.6x1mm_P0.65mm; MPN TPD1E01B04DPYR; LCSC C779389
J4: SWD 10p 1.27mm; Tag-Connect_TC2050-IDC-NL_2x05_P1.27mm_Vertical
L10: 2.2uH 20% DFE201210U-2R2M=P2; IND_Murata_DFE201210U; MPN DFE201210U-2R2M=P2; LCSC C2049745
Q1: DMG2305UX-13; SOT-23; MPN DMG2305UX-13; LCSC C144153
R22, R23, R30, R31, R36, R37: 4.7k 1%; R_0402_1005Metric; MPN 0402WGF4701TCE; LCSC C25900
R32, R33, R34, R35: 100 1%; R_0402_1005Metric; MPN 0402WGF1000TCE; LCSC C25076
TP1: SENSE1; TestPoint_Pad_D1.0mm
TP2: SENSE2; TestPoint_Pad_D1.0mm
TP3: SHLD; TestPoint_Pad_D1.0mm
TP4: +3V3; TestPoint_Pad_D1.0mm
TP5, TP7, TP11: GND; TestPoint_Pad_D1.0mm
TP6: +3V3_FDC_SW; TestPoint_Pad_D1.0mm
TP8: VBAT; TestPoint_Pad_D1.0mm
TP9: VBAT_RAW; TestPoint_Pad_D1.0mm
TP10: VINT; TestPoint_Pad_D1.0mm
TP12: SDA; TestPoint_Pad_D1.0mm
TP13: SCL; TestPoint_Pad_D1.0mm
TP14: PMIC_INT; TestPoint_Pad_D1.0mm
TP15: NRESET; TestPoint_Pad_D1.0mm
TP16: MARK1; TestPoint_Pad_D1.0mm
TP17: MARK2; TestPoint_Pad_D1.0mm
U1: 453-00001R BL54L15; Ezurio_BL54L15_453-00001; MPN 453-00001R; DigiKey 776-453-00001RCT-ND; not fitted
U2: nPM2100-QEAA; QFN-16-1EP_4x4mm_P0.65mm_EP2.7x2.7mm_ThermalVias; MPN NPM2100-QEAA-R7; LCSC C46968654
U3: FDC1004; MSOP-10_3x3mm_P0.5mm; MPN FDC1004DGSR; LCSC C2865994
U4: SHT40-AD1B; Sensirion_DFN-4_1.5x1.5mm_P0.8mm_SHT4x_NoCentralPad; MPN SHT40-AD1B-R2; LCSC C2909890
X1: CM8V-T1A 32.768kHz CL=7pF 20ppm; XTAL_CM8V-T1A_2012; MPN CM8V-T1A-32.768KHZ-7PF-20PPM-TA-QC; LCSC C5136974

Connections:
+3V3: C3.1, C25.1, C27.1, D3.1 (A1), J4.1, R22.1, R23.1, TP4.1 (1_1), U1.26 (VDD_nRF), U2.13 (VOUT), U4.3 (VDD)
+3V3_FDC_SW: C26.1, C28.1, R36.1, R37.1, TP6.1 (1_1), U2.12 (LSOUT/VOUTLDO), U3.8 (VDD)
/CIN1_PROTECTED: D8.1 (A1), R30.2, U3.2 (CIN1)
/CIN2_PROTECTED: D9.1 (A1), R31.2, U3.3 (CIN2)
/FDC_SCL: R37.2, U1.23 (P1.04), U3.9 (SCL)
/FDC_SDA: R36.2, U1.22 (P1.05), U3.10 (SDA)
/MARK1: TP16.1 (1_1), U1.20 (P1.07)
/MARK2: TP17.1 (1_1), U1.21 (P1.06)
/NRESET: R35.2, TP15.1 (1_1), U1.7 (nRESET), U2.10 (PG/RESET)
/P2.07_SWO: R34.2, U1.4 (P2.07/SWO)
/PMIC_INT: TP14.1 (1_1), U1.17 (P0.00), U2.5 (GPIO0)
/RESET_EXT: D7.1 (A1), J4.10, R35.1
/SCL: R23.2, TP13.1 (1_1), U1.35 (P1.11), U2.7 (SCL), U4.2 (SCL)
/SDA: R22.2, TP12.1 (1_1), U1.28 (P1.10), U2.6 (SDA), U4.1 (SDA)
/SENSE1: R30.1, TP1.1 (1_1)
/SENSE2: R31.1, TP2.1 (1_1)
/SHLD: D10.1 (A1), TP3.1 (1_1), U3.1 (SHLD1), U3.6 (SHLD2)
/SW: L10.1, U2.2 (SW)
/SWDCLK: R33.2, U1.6 (SWDCLK)
/SWDCLK_EXT: D5.1 (A1), J4.4, R33.1
/SWDIO: R32.2, U1.5 (SWDIO)
/SWDIO_EXT: D4.1 (A1), J4.2, R32.1
/SWO_EXT: D6.1 (A1), J4.6, R34.1
/VBAT_RAW: BT1.1 (+), D1.1 (A1), Q1.3 (D), TP9.1 (1_1)
/VINT: C23.1, C24.1, TP10.1 (1_1), U2.14 (VINT), U2.15 (VINT)
/XL1: U1.25 (P1.00/XL1), X1.1
/XL2: U1.24 (P1.01/XL2), X1.2
GND: BT1.2 (-), C3.2, C21.2, C22.2, C23.2, C24.2, C25.2, C26.2, C27.2, C28.2, D1.2 (A2), D2.2 (A2), D3.2 (A2), D4.2 (A2), D5.2 (A2), D6.2 (A2), D7.2 (A2), D8.2 (A2), D9.2 (A2), D10.2 (A2), J4.3, J4.5, J4.9, Q1.1 (G), TP5.1 (1_1), TP7.1 (1_1), TP11.1 (1_1), U1.1 (GND), U1.16 (GND), U1.27 (GND), U1.39 (GND), U2.8 (SYSGDEN), U2.11 (AVSS2), U2.16 (PVSS), U2.17 (AVSS1), U3.7 (GND), U4.4 (VSS)
VBAT: C21.1, C22.1, D2.1 (A1), L10.2, Q1.2 (S), TP8.1 (1_1), U2.3 (VBAT)

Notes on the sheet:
RADIO / MCU - BL54L15
MODULE SUPPLY / FILTER
SWD PROGRAMMING
32 kHz / BATTERY
POWER - nPM2100
INPUT PROTECTION
MOISTURE + TEMPERATURE / HUMIDITY
453-00001R: integrated PCB antenna.
U1 DNP is for JLC assembly only; hand fit for use.
SDA / SCL: configure GPIO selection in firmware.
C3: external module bulk capacitor.
Reset: direct host / PMIC connection.
Keep antenna copper / component keepout clear.
X1: XL1 pad 25; XL2 pad 24.
Internal LFXO load bank; tune on hardware.
CR2032: primary cell; do not charge.
VBAT -> boost -> +3V3
+3V3_FDC_SW supplies FDC1004 only.
GPIO0: PMIC_INT | GPIO1: unused (NC).
PMOS reverse polarity; ESD clamps + series resistors.
No sustained overvoltage cutoff or battery fuse.
FDC1004: switched supply. SHT40: main +3V3 supply.
R22 / R23: shared I2C pull-ups to +3V3.
CIN1 / CIN2 via 4.7k protection; SHLD driven by FDC.
FIDUCIALS

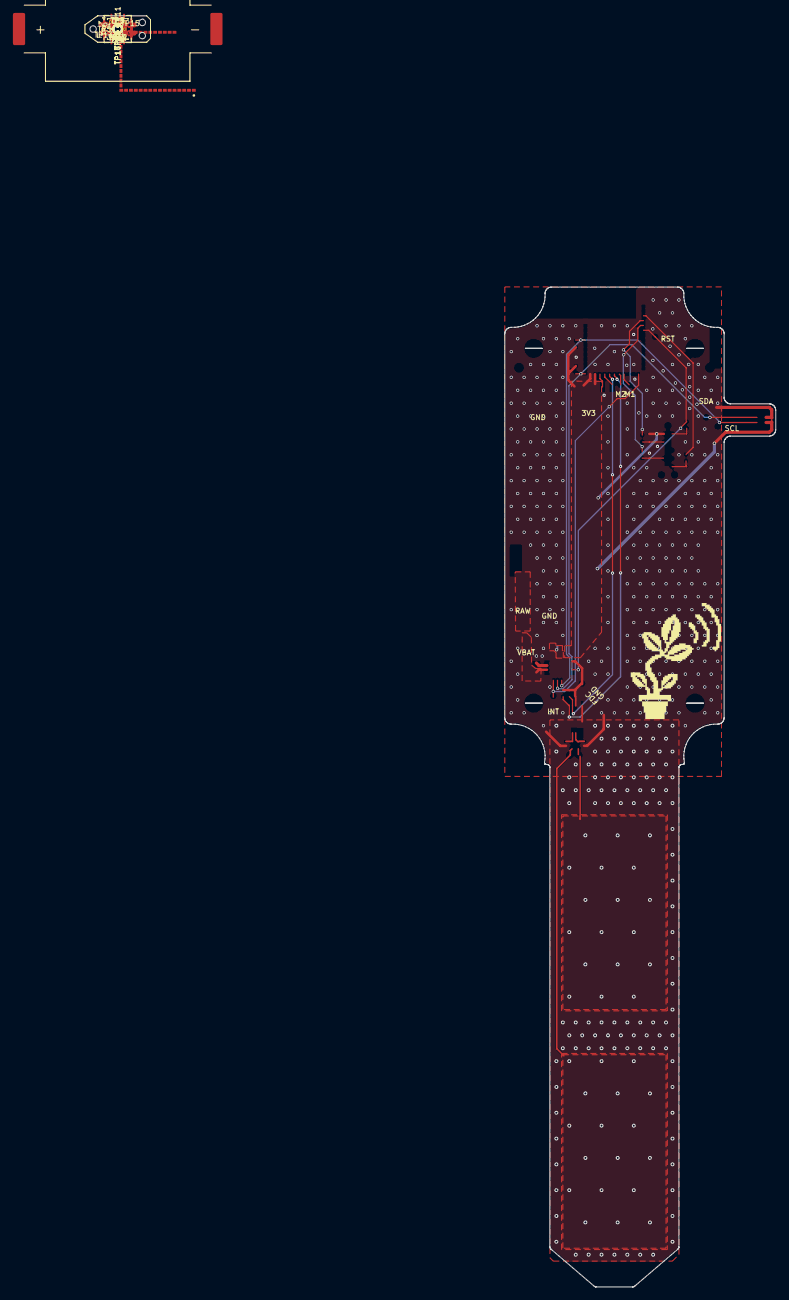
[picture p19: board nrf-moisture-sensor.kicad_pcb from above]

Board: 4 copper layers, 42.0 x 155.0 mm, 58 parts (1 on the bottom side), 29 nets.

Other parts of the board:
TH1, TH2, TH3: ToolingHole_JLC_1.152mm

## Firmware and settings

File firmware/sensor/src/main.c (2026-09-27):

/* Real battery-powered sensor image. One cold boot per cycle. */
#include "sensor.h"
#include "bthome.h"
#include "config_service.h"
#include <string.h>
#include <zephyr/bluetooth/bluetooth.h>
#include <zephyr/bluetooth/conn.h>
#include <zephyr/mgmt/mcumgr/transport/smp_bt.h>
#include <zephyr/dfu/mcuboot.h>
#include <zephyr/drivers/hwinfo.h>
#include <zephyr/drivers/i2c.h>
#include <zephyr/drivers/timer/nrf_grtc_timer.h>
#include <zephyr/drivers/watchdog.h>
#include <zephyr/kernel.h>
#include <zephyr/pm/device.h>
#include <zephyr/pm/device_runtime.h>
#include <zephyr/sys/poweroff.h>
#include <zephyr/sys/reboot.h>

struct sensor_boot_trace {
    uint32_t magic;
    uint32_t boots;
    uint32_t stage;
    int32_t error;
    uint32_t last_failure_stage;
    int32_t last_failure_error;
    struct sensor_fault fault;
    struct sensor_sample sample;
    uint32_t wake_seconds;
};

static struct sensor_boot_trace sensor_trace __attribute__((section(".noinit")));
static struct sensor_fault cycle_fault;
static const struct sensor_bus *trace_bus;
static uint32_t reset_cause;
static uint8_t pmic_reset = 0xff, previous_stage = 0xff;

static void pmic_trace(uint8_t stage)
{
    if (trace_bus)
        (void)sensor_retained_stage(trace_bus, stage);
}

static void trace_boot(void)
{
    /* A new layout/magic must never interpret old or power-on SRAM as errors. */
    if (sensor_trace.magic != 0x53454e54u)
        sensor_trace = (struct sensor_boot_trace){.magic = 0x53454e54u};
    sensor_trace.boots++;
}

static void trace_stage(uint32_t stage, int error)
{
    pmic_trace(stage);
    sensor_trace.stage = stage;
    sensor_trace.error = error;
}

static void trace_failure(uint32_t stage, int error)
{
    trace_stage(stage, error);
    sensor_trace.last_failure_stage = stage;
    sensor_trace.last_failure_error = error;
    sensor_trace.fault = cycle_fault;
    printk("sensor failure stage=%u error=%d addr=0x%02x reg=0x%02x "
           "observed=0x%04x mask=0x%04x expected=0x%04x\n",
           (unsigned)stage, error, cycle_fault.address, cycle_fault.reg,
           cycle_fault.observed, cycle_fault.mask, cycle_fault.expected);
}

static uint16_t diagnostic_error(void)
{
    int64_t error = sensor_trace.last_failure_error;

    if (error < 0)
        error = -error;
    return error > UINT16_MAX ? UINT16_MAX : (uint16_t)error;
}

#if !CONFIG_SENSOR_OTA
static const struct device *sensor_wdt;
#endif

struct sensor_devices {
    const struct device *main;
    const struct device *fdc;
};

/* Runtime PM applies the no-pull, disconnected sleep pinctrl state. */
static int fdc_bus_is_asleep(const struct device *dev) {
    enum pm_device_state state;
    int rc = pm_device_state_get(dev, &state);
    if (rc)
        return rc;
    return pm_device_runtime_is_enabled(dev) && state == PM_DEVICE_STATE_SUSPENDED ? 0 : -EBUSY;
}

static int transfer(void *ctx, uint8_t address, const uint8_t *w, size_t nw, uint8_t *r,
                    size_t nr) {
    const struct sensor_devices *devices = ctx;
    const struct device *dev = address == 0x50 ? devices->fdc : devices->main;
    if (nw && nr)
        return i2c_write_read(dev, address, w, nw, r, nr);
    if (nw)
        return i2c_write(dev, w, nw, address);
    return i2c_read(dev, r, nr, address);
}
static void delay(void *ctx, unsigned ms) {
    (void)ctx;
    k_msleep(ms);
}
static char hex_digit(uint8_t v) {
    return v < 10 ? (char)('0' + v) : (char)('A' + v - 10);
}
static uint8_t battery_percent(uint16_t millivolts) {
    /* Provisional voltage-only estimate for the CR2032 prototype. */
    if (millivolts <= 2200)
        return 0;
    if (millivolts >= 3000)
        return 100;
    return (uint8_t)(((uint32_t)(millivolts - 2200) * 100U) / 800U);
}
#if !CONFIG_SENSOR_OTA
static int arm_watchdog(void) {
    const struct device *dev = DEVICE_DT_GET(DT_NODELABEL(wdt31));
    struct wdt_timeout_cfg cfg = {.window = {0, 15000}, .flags = WDT_FLAG_RESET_SOC};
    if (!device_is_ready(dev))
        return -ENODEV;
    int rc = wdt_install_timeout(dev, &cfg);
    if (rc < 0)
        return rc;
    rc = wdt_setup(dev, WDT_OPT_PAUSE_HALTED_BY_DBG);
    if (!rc)
        sensor_wdt = dev;
    return rc;
}

static void feed_watchdog(void)
{
    if (sensor_wdt)
        (void)wdt_feed(sensor_wdt, 0);
}
#else
static void feed_watchdog(void) { }
#endif
static int radio_window(const struct sensor_bus *bus, const struct sensor_sample *sample) {
    struct sensor_config config;
    sensor_settings_get(&config);
    trace_stage(70, 0);
    int rc = sensor_radio_start(bus);
    if (rc) {
        trace_failure(70, rc);
        return rc;
    }
    uint8_t id[16];
    bt_addr_le_t addr = {.type = BT_ADDR_LE_RANDOM};
    ssize_t n = hwinfo_get_device_id(id, sizeof(id));
    if (n < 6) {
        trace_failure(71, -EIO);
        return -EIO;
    }
    for (ssize_t i = 0; i < n; i++)
        addr.a.val[i % 6] ^= id[i];
    addr.a.val[5] |= 0xc0;
    rc = bt_id_create(&addr, NULL);
    if (rc < 0) {
        trace_failure(72, rc);
        return rc;
    }
    rc = bt_enable(NULL);
    if (rc) {
        trace_failure(73, rc);
        return rc;
    }
    char name[] = {
        'S', 'o', 'i', 'l', '-',
        hex_digit(addr.a.val[1] >> 4), hex_digit(addr.a.val[1] & 0x0f),
        hex_digit(addr.a.val[0] >> 4), hex_digit(addr.a.val[0] & 0x0f), 0,
    };
    const char *device_name = config.name[0] ? config.name : name;
    rc = bt_set_name(device_name);
    if (rc) return rc;
    /* BTHome v2 service data uses UUID FCD2, standard object IDs, and the
     * calibrated moisture values configured below. */
    uint8_t bthome[BOARD_BTHOME_PAYLOAD_LEN];
    struct board_bthome_values values = {
        .temperature_cc = sample->temperature_cc,
        .humidity_cpct = sample->humidity_cpct,
        .battery_pct = battery_percent(sample->battery_mv),
        .battery_mv = sample->battery_mv,
        .moisture1_cpct = sensor_moisture(sample->capacitance_ff[0], config.dry[0], config.wet[0]),
        .moisture2_cpct = sensor_moisture(sample->capacitance_ff[1], config.dry[1], config.wet[1]),
        .omit_moisture = !config.calibrated,
    };
    int payload_len = board_bthome_encode(&values, bthome, sizeof bthome);
    if (payload_len < 0) {
        trace_failure(74, -EINVAL);
        return -EINVAL;
    }
    const struct bt_data ad[] = {
        BT_DATA_BYTES(BT_DATA_FLAGS, BT_LE_AD_GENERAL | BT_LE_AD_NO_BREDR),
        BT_DATA(0x16, bthome, payload_len),
    };
    const struct bt_data sd[] = {
        BT_DATA(BT_DATA_NAME_COMPLETE, device_name, strlen(device_name)),
        /* SMP is in scan response; BTHome remains in the primary packet. */
        BT_DATA_BYTES(BT_DATA_UUID128_ALL, SMP_BT_SVC_UUID_VAL),
    };
    rc = bt_le_adv_start(BT_LE_ADV_PARAM(BT_LE_ADV_OPT_USE_IDENTITY |
                                         BT_LE_ADV_OPT_SCANNABLE |
                                         BT_LE_ADV_OPT_CONN,
                                         config.adv_ms * 8 / 5, config.adv_ms * 8 / 5,
                                         NULL),
                         ad, ARRAY_SIZE(ad), sd, ARRAY_SIZE(sd));
    if (rc) {
        trace_failure(75, rc);
        return rc;
    }
    trace_stage(76, sample->battery_mv);
    int64_t deadline = k_uptime_get() + config.window_ms;
    bool had_connection = false;
    while (k_uptime_get() < deadline || sensor_session_connected()) {
        uint16_t radio_battery_mv;
        rc = sensor_battery_read(bus, &radio_battery_mv);
        if (!rc && radio_battery_mv < SENSOR_MIN_BATTERY_MV)
            rc = -ERANGE;
        if (!rc)
            rc = sensor_watchdog_feed(bus);
        if (rc) {
            trace_failure(78, rc);
            sensor_session_disconnect();
            (void)bt_le_adv_stop();
            return rc;
        }
        feed_watchdog();
        sensor_settings_process();
        if (sensor_session_expired()) {
            sensor_session_disconnect();
            break;
        }
        if (sensor_session_connected()) had_connection = true;
        else if (had_connection) break;
        if (sensor_sample_requested()) {
            /* Foreground only; callbacks never touch I2C. Sampling remains
             * bounded by both watchdogs, with the FDC rail off afterwards. */
            struct sensor_sample fresh = {0};
            int measured = sensor_start(bus, &fresh);
            if (!measured) measured = sensor_measure(bus, &fresh);
            const struct sensor_devices *devices = bus->ctx;
            int off = fdc_bus_is_asleep(devices->fdc);
            if (!off && !measured) off = sensor_radio_start(bus);
            sensor_status_sample(&fresh, measured ? measured : off);
            if (off) {
                trace_failure(80, off);
                return off;
            }
            if (measured) {
                trace_failure(61, measured);
                sensor_session_disconnect();
                (void)bt_le_adv_stop();
                return measured;
            }
        }
        int64_t remaining = deadline - k_uptime_get();
        sensor_session_wait(sensor_session_connected() ? 1000 :
                            remaining > 1000 ? 1000 : remaining > 0 ? remaining : 0);
    }
    /* Finish an accepted save even if the client has just disconnected. */
    sensor_settings_process();
    feed_watchdog();
    rc = bt_le_adv_stop();
    if (rc != -EALREADY && rc)
        trace_failure(77, rc);
    else
        trace_stage(77, 0);
    return rc == -EALREADY ? 0 : rc;
}

#if CONFIG_SENSOR_OTA
static const struct bt_data ota_ad[] = {
    BT_DATA_BYTES(BT_DATA_FLAGS, BT_LE_AD_GENERAL | BT_LE_AD_NO_BREDR),
    BT_DATA_BYTES(BT_DATA_UUID128_ALL, SMP_BT_SVC_UUID_VAL),
};
static const struct bt_data ota_sd[] = {
    BT_DATA(BT_DATA_NAME_COMPLETE, CONFIG_BT_DEVICE_NAME,
            sizeof(CONFIG_BT_DEVICE_NAME) - 1),
};
static void ota_advertise(void) {
    int rc = bt_le_adv_start(BT_LE_ADV_CONN_FAST_1, ota_ad, ARRAY_SIZE(ota_ad),
                             ota_sd, ARRAY_SIZE(ota_sd));
    if (rc)
        printk("OTA advertising failed (%d)\n", rc);
    else
        printk("OTA ready: connect over BLE using MCUmgr/SMP\n");
}
static void ota_disconnected(struct bt_conn *conn, uint8_t reason) {
    ARG_UNUSED(conn);
    printk("OTA disconnected (reason 0x%02x)\n", reason);
    ota_advertise();
}
BT_CONN_CB_DEFINE(sensor_ota_conn_callbacks) = {
    .disconnected = ota_disconnected,
};
static int ota_identity(void) {
    uint8_t id[16];
    bt_addr_le_t addr = {.type = BT_ADDR_LE_RANDOM};
    ssize_t n = hwinfo_get_device_id(id, sizeof(id));
    if (n < 6)
        return -EIO;
    for (ssize_t i = 0; i < n; i++)
        addr.a.val[i % 6] ^= id[i];
    addr.a.val[5] |= 0xc0;
    return bt_id_create(&addr, NULL) < 0 ? -EIO : 0;
}
static int ota_run(const struct sensor_bus *bus) {
    int rc = sensor_ota_start(bus);
    if (rc)
        return rc;
    rc = ota_identity();
    if (rc)
        return rc;
    rc = bt_enable(NULL);
    if (rc)
        return rc;
    rc = boot_write_img_confirmed();
    if (rc)
        return rc;
    ota_advertise();
    printk("OTA maintenance active\n");
    for (;;) {
        sensor_settings_process();
        if (sensor_session_expired()) sensor_session_disconnect();
        sensor_session_wait(1000);
    }
    return 0;
}
#endif
static void power_backoff(const struct sensor_bus *bus, int error)
{
    /* Keep the failing operation in SCRATCHB across Hibernate. Replacing it
     * with the generic backoff stage would hide sensing and radio failures
     * when the PMIC removes power from the MCU's retained RAM. */
    if (sensor_trace.last_failure_stage != sensor_trace.stage ||
        sensor_trace.last_failure_error != error)
        trace_failure(84, error);
    sensor_trace.wake_seconds = CONFIG_SENSOR_UV_RETRY_SECONDS;
    /* Preserve the watchdog origin across the hibernate power cut so the
     * first recovery advertisement/status can distinguish these paths. */
    if (trace_bus && (reset_cause & RESET_WATCHDOG))
        (void)sensor_retained_stage(bus, 0xe1);
    else if (trace_bus && ((pmic_reset >> 1) & 15) == 5)
        (void)sensor_retained_stage(bus, 0xe2);
    int rc = trace_bus ? sensor_hibernate(bus, CONFIG_SENSOR_UV_RETRY_SECONDS) : -ENODEV;
    /* Normally VOUT disappears during the task write. If I2C failed or the
     * rail did not turn off, use the MCU's timed System OFF as a fallback.
     * Retained BLOCKED prevents sensor/radio attempts on a watchdog reset.
     * A PMIC that cannot be reached cannot be guaranteed to stop its timer. */
    k_msleep(20);
    if (trace_bus)
        (void)sensor_stop(bus);
    trace_stage(85, rc);
    int wake = z_nrf_grtc_wakeup_prepare((uint64_t)CONFIG_SENSOR_UV_RETRY_SECONDS *
                                       USEC_PER_SEC);
    if (wake) {
        sensor_trace.stage = 86;
        sensor_trace.error = wake;
    }
    /* Even if timed wake preparation fails, stay off instead of feeding a
     * reset loop. Recovery then requires an external wake or power cycle.
     * No timeout-dependent work is safe after GRTC preparation. */
    sys_poweroff();
}

int main(void) {
    trace_boot();
    trace_stage(1, 0);
    struct sensor_devices devices = {
        .main = DEVICE_DT_GET(DT_NODELABEL(i2c22)),
        .fdc = DEVICE_DT_GET(DT_NODELABEL(i2c20)),
    };
    struct sensor_bus bus = {&devices, transfer, delay, &cycle_fault};
    struct sensor_sample sample = {0};
    int rc = 0;
    if (!device_is_ready(devices.main) || !device_is_ready(devices.fdc))
        rc = -ENODEV;
    if (!rc)
        rc = fdc_bus_is_asleep(devices.fdc);
    if (device_is_ready(devices.main))
        trace_bus = &bus;
    if (rc)
        power_backoff(&bus, rc);

    uint8_t retained = 0;
    rc = sensor_retained_read(&bus, &retained, &previous_stage, &pmic_reset);
    if (!rc)
        rc = sensor_power_probe(&bus, &sample.battery_mv);
    (void)hwinfo_get_reset_cause(&reset_cause);
    (void)hwinfo_clear_reset_cause();
    sensor_status_diagnostics(reset_cause, pmic_reset, previous_stage,
                              sensor_trace.last_failure_stage, diagnostic_error());
    /* An interrupted attempt gets a full quiet interval even after voltage
     * rebounds. Once BLOCKED, use a higher voltage for recovery. SMP's explicit
     * software reboot at a healthy supply must still allow an OTA test boot;
     * normal error paths below never request immediate software reboots. */
    bool planned_reboot = (reset_cause & RESET_SOFTWARE) &&
                          sample.battery_mv >= SENSOR_RECOVER_BATTERY_MV;
    if (rc || (retained == SENSOR_POWER_ATTEMPT && !planned_reboot) ||
        !sensor_power_allowed(sample.battery_mv, retained))
        power_backoff(&bus, rc ? rc : -EAGAIN);
    rc = sensor_retained_state(&bus, SENSOR_POWER_ATTEMPT);
    if (rc)
        power_backoff(&bus, rc);
    uint8_t clear[] = {0xd1, 1};
    (void)transfer(&devices, 0x74, clear, 2, NULL, 0);
#if !CONFIG_SENSOR_OTA
    rc = arm_watchdog();
    if (rc)
        power_backoff(&bus, rc);
#endif
    int settings_rc = sensor_settings_init();
    if (settings_rc)
        printk("configuration load failed (%d); using build defaults\n", settings_rc);
#if CONFIG_SENSOR_OTA
    rc = ota_run(&bus);
    power_backoff(&bus, rc);
    return 0;
#else
    trace_stage(2, 0);
#endif
    trace_stage(40, 0);
    rc = sensor_start(&bus, &sample);
    bool power_ready = rc == 0;
    trace_stage(50, rc);
    if (rc)
        trace_failure(50, rc);
    if (!rc) {
        trace_stage(60, 0);
        rc = sensor_measure(&bus, &sample);
        if (rc)
            trace_failure(61, rc);
    }
    sensor_trace.sample = sample;
    sensor_status_sample(&sample, rc);
    int stop = fdc_bus_is_asleep(devices.fdc);
    if (!stop)
        stop = sensor_sensors_off(&bus);
    if (stop)
        power_backoff(&bus, stop);
    bool low_battery = sample.battery_mv < SENSOR_MIN_BATTERY_MV;
    if (rc || low_battery)
        power_backoff(&bus, rc ? rc : -ERANGE);
    if (power_ready) {
        rc = radio_window(&bus, &sample);
        if (rc)
            power_backoff(&bus, rc);
    }
    stop = sensor_stop(&bus);
    if (stop)
        power_backoff(&bus, stop);
    struct sensor_config config;
    sensor_settings_get(&config);
    uint32_t cycle_seconds = sensor_sleep_seconds(&config,
        sample.battery_mv < config.low_mv, k_uptime_get());
    sensor_trace.wake_seconds = cycle_seconds;
#if !CONFIG_SENSOR_OTA && defined(CONFIG_BOOTLOADER_MCUBOOT)
    if (!settings_rc && boot_write_img_confirmed())
        power_backoff(&bus, -EIO);
#endif
    rc = sensor_retained_state(&bus, SENSOR_POWER_CLEAN);
    if (rc)
        power_backoff(&bus, rc);
    trace_stage(83, 0);
    k_msleep(20);
    /* GRTC preparation disables kernel compare channels. Nothing that uses
     * I2C, delays, logging, or any kernel timeout may follow it. */
    int wake = z_nrf_grtc_wakeup_prepare((uint64_t)cycle_seconds * USEC_PER_SEC);
    if (wake) {
        sensor_trace.stage = 81;
        sensor_trace.error = wake;
        /* Fail closed: an external wake may be needed if no timer was armed. */
    }
    sys_poweroff();
    return 0;
}

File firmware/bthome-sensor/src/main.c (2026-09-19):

/*
 * BTHome soil sensor — nRF54L15 DK, simulated data.
 *
 * One cold boot is one cycle: wake, generate, advertise, System OFF. Waking
 * from System OFF resets the device, so there is no loop and no state to
 * carry between cycles.
 */

#include <zephyr/kernel.h>
#include <zephyr/bluetooth/bluetooth.h>
#include <zephyr/sys/printk.h>

#include <string.h>

#include <zephyr/drivers/hwinfo.h>
#include <zephyr/drivers/timer/nrf_grtc_timer.h>
#include <zephyr/drivers/gpio.h>
#include <zephyr/drivers/watchdog.h>
#include <zephyr/sys/poweroff.h>
#include <zephyr/sys/reboot.h>

#ifdef CONFIG_SENSOR_OTA
#include <zephyr/bluetooth/conn.h>
#include <zephyr/dfu/mcuboot.h>
#include <zephyr/mgmt/mcumgr/transport/smp_bt.h>
#endif

#include "bthome.h"

/*
 * The BLE identity must be identical on every cold boot. Zephyr generates one
 * when none is configured — the LBS sample logs "No ID address" and does
 * exactly that — and a fresh address each hour would make Home Assistant
 * register a new device every hour.
 *
 * Deriving it from the chip's own ID keeps it stable with no settings
 * subsystem, no NVS, and no flash wear.
 */
static int set_stable_identity(void)
{
	bt_addr_le_t addr = { .type = BT_ADDR_LE_RANDOM };
	uint8_t hwid[16];
	ssize_t n;
	int err;

	n = hwinfo_get_device_id(hwid, sizeof(hwid));
	if (n < 6) {
		printk("hwinfo_get_device_id returned %d\n", (int)n);
		return -1;
	}

	/* Fold every byte of the device id into six so none of it is ignored. */
	memset(addr.a.val, 0, sizeof(addr.a.val));
	for (ssize_t i = 0; i < n; i++) {
		addr.a.val[i % 6] ^= hwid[i];
	}

	/* A static random address must have its two most significant bits set. */
	addr.a.val[5] |= 0xC0;

	err = bt_id_create(&addr, NULL);
	if (err < 0) {
		printk("bt_id_create failed (%d)\n", err);
		return err;
	}

	printk("identity: %02X:%02X:%02X:%02X:%02X:%02X\n",
	       addr.a.val[5], addr.a.val[4], addr.a.val[3],
	       addr.a.val[2], addr.a.val[1], addr.a.val[0]);

	return 0;
}

/* One wet-to-dry sweep, then it repeats, so the curve is visible in a session. */
#define SIM_DRY_PERIOD_MS   (6ULL * 60 * 60 * 1000)
#define SIM_MOIST_WET_CPCT  8000U   /* 80.00 % */
#define SIM_MOIST_DRY_CPCT  2500U   /* 25.00 % */

/* SENSE2 reads four points below SENSE1 so that a positional mix-up between
 * the two entities is obvious in Home Assistant rather than invisible. */
#define SIM_SENSE2_OFFSET   400U

/*
 * GRTC SYSCOUNTER survives System OFF — the datasheet is explicit that
 * SYSCOUNTERL/H are restored on wakeup even though the rest of GRTC resets.
 * That makes it the one clock that measures total elapsed time across cold
 * boots, which is why the simulation can be a pure function of it and needs no
 * stored state.
 *
 * The counter runs at sys_clock_hw_cycles_per_sec(), not a fixed 1 MHz, so
 * convert rather than assume.
 */
static uint64_t elapsed_ms(void)
{
	uint64_t ticks = z_nrf_grtc_timer_read();

	return (ticks * 1000ULL) / (uint64_t)sys_clock_hw_cycles_per_sec();
}

/* Triangle wave in [-amplitude, +amplitude], integer only. */
static int32_t triangle(uint64_t t_ms, uint32_t period_ms, int32_t amplitude)
{
	uint32_t phase = (uint32_t)(t_ms % period_ms);
	uint32_t half = period_ms / 2U;
	uint32_t up = (phase < half) ? phase : (period_ms - phase);

	return ((int32_t)up * 2 * amplitude) / (int32_t)half - amplitude;
}

static struct bthome_values sim_values(uint64_t t_ms)
{
	uint64_t phase = t_ms % SIM_DRY_PERIOD_MS;
	uint32_t span = SIM_MOIST_WET_CPCT - SIM_MOIST_DRY_CPCT;
	uint16_t m1 = (uint16_t)(SIM_MOIST_WET_CPCT -
				 (uint64_t)span * phase / SIM_DRY_PERIOD_MS);
	uint64_t drained = t_ms / (30ULL * 60 * 1000);   /* 1 % per 30 min */

	struct bthome_values v = {
		.battery_pct = (drained >= 99) ? 1U : (uint8_t)(100U - drained),
		.temperature_cc =
			(int16_t)(2100 + triangle(t_ms, 20U * 60 * 1000, 150)),
		.humidity_cpct =
			(uint16_t)(4500 + triangle(t_ms, 37U * 60 * 1000, 800)),
		.moisture1_cpct = m1,
		.moisture2_cpct = (m1 > SIM_SENSE2_OFFSET)
					  ? (uint16_t)(m1 - SIM_SENSE2_OFFSET)
					  : 0U,
	};

	return v;
}

/* The advertisement is exactly 31 of 31 bytes with a 7-character name; a
 * longer CONFIG_SENSOR_DEVICE_NAME makes bt_le_adv_start() fail at runtime,
 * and the device silently stops advertising every cycle while the console
 * still looks healthy. */
BUILD_ASSERT(sizeof(CONFIG_SENSOR_DEVICE_NAME) - 1 <= 7,
	     "BLE name must fit the 9 spare AD bytes");

static void advertise(const uint8_t *svc_data)
{
	const struct bt_data ad[] = {
		BT_DATA_BYTES(BT_DATA_FLAGS, BT_LE_AD_GENERAL | BT_LE_AD_NO_BREDR),
		BT_DATA(BT_DATA_SVC_DATA16, svc_data, BTHOME_ADV_DATA_LEN),
		BT_DATA(BT_DATA_NAME_COMPLETE, CONFIG_SENSOR_DEVICE_NAME,
			sizeof(CONFIG_SENSOR_DEVICE_NAME) - 1),
	};
	int err;

	if (set_stable_identity() < 0) {
		printk("continuing with the stack's own identity\n");
	}

	err = bt_enable(NULL);
	if (err) {
		printk("bt_enable failed (%d)\n", err);
		return;
	}

	/*
	 * Ask the stack what identity it actually holds, rather than trusting
	 * the address we handed bt_id_create().
	 *
	 * The earlier version printed our own computed buffer, which is a
	 * deterministic function of the chip id — so it printed the same six
	 * bytes whether bt_id_create() had succeeded, failed, or been ignored.
	 * That made "stable across resets" a tautology and hid a real bug for
	 * the whole build. This line is the only one that can contradict us.
	 */
	{
		bt_addr_le_t ids[CONFIG_BT_ID_MAX];
		size_t count = ARRAY_SIZE(ids);

		bt_id_get(ids, &count);
		if (count > 0) {
			printk("stack identity: %02X:%02X:%02X:%02X:%02X:%02X (type %u, %u id%s)\n",
			       ids[0].a.val[5], ids[0].a.val[4], ids[0].a.val[3],
			       ids[0].a.val[2], ids[0].a.val[1], ids[0].a.val[0],
			       ids[0].type, (unsigned)count, count == 1 ? "" : "s");
		} else {
			printk("stack identity: NONE — bt_id_create() did not take\n");
		}
	}
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

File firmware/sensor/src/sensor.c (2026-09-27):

#include "sensor.h"
#include <errno.h>
static int fault(const struct sensor_bus *b, int error, uint8_t address, uint8_t reg,
                 uint16_t observed, uint16_t mask, uint16_t expected) {
    if (b->fault && !b->fault->error)
        *b->fault = (struct sensor_fault){error, address, reg, observed, mask, expected};
    return error;
}

static int transfer(const struct sensor_bus *b, uint8_t address, const uint8_t *w,
                    size_t nw, uint8_t *r, size_t nr) {
    int rc = b->transfer(b->ctx, address, w, nw, r, nr);
    if (rc < 0)
        return fault(b, rc, address, nw ? w[0] : 0, 0, 0, 0);
    return rc;
}
uint8_t sensor_crc(const uint8_t *d, size_t n) {
    uint8_t crc = 0xff;
    for (size_t i = 0; i < n; i++) {
        crc ^= d[i];
        for (int j = 0; j < 8; j++)
            crc = (crc & 0x80) ? (crc << 1) ^ 0x31 : crc << 1;
    }
    return crc;
}
#define TRY(expr)                                                                                  \
    do {                                                                                           \
        int rc = (expr);                                                                           \
        if (rc < 0)                                                                                \
            return rc;                                                                             \
    } while (0)
static int wr(const struct sensor_bus *b, uint8_t reg, uint8_t value) {
    uint8_t w[] = {reg, value};
    return transfer(b, 0x74, w, 2, 0, 0);
}
static int rd(const struct sensor_bus *b, uint8_t reg, uint8_t *value) {
    return transfer(b, 0x74, &reg, 1, value, 1);
}
static int checked(const struct sensor_bus *b, uint8_t reg, uint8_t value) {
    uint8_t v;
    TRY(wr(b, reg, value));
    TRY(rd(b, reg, &v));
    return v == value ? 0 : fault(b, -EIO, 0x74, reg, v, 0xff, value);
}
static int wait_pm(const struct sensor_bus *b, uint8_t reg, uint8_t mask, uint8_t value) {
    uint8_t v = 0;
    for (int i = 0; i < 30; i++) {
        TRY(rd(b, reg, &v));
        if ((v & mask) == value)
            return 0;
        b->delay_ms(b->ctx, 1);
    }
    return fault(b, -ETIMEDOUT, 0x74, reg, v, mask, value);
}
static int adc(const struct sensor_bus *b, uint8_t mode, uint16_t *mv) {
    uint8_t v, bit = mode == 4 ? 8 : 1;
    /* nPM2100 DS 7.1: a new conversion may only start when ADC is ready. */
    TRY(wait_pm(b, 0x9d, 3, 0));
    TRY(wr(b, 0x06, bit)); /* Clear stale ADC ready event before triggering. */
    TRY(checked(b, 0x91, mode));
    TRY(wr(b, 0x90, 1));
    TRY(wait_pm(b, 0x01, bit, bit));
    TRY(rd(b, mode == 4 ? 0x99 : 0x96, &v));
    *mv = mode == 4 ? 1800 + (1500 * (unsigned)v) / 256 : (3200 * (unsigned)v) / 256;
    return 0;
}
int sensor_watchdog_start(const struct sensor_bus *b, uint32_t seconds) {
    if (!seconds || seconds > 262144)
        return -EINVAL;
    TRY(wr(b, 0xb1, 1));
    TRY(wait_pm(b, 0xb7, 0xff, 0));
    TRY(checked(b, 0xd6, 1)); /* Also disable LDOSW on watchdog reset. */
    uint32_t ticks = seconds * 64 - 1;
    TRY(checked(b, 0xb4, ticks >> 16));
    TRY(checked(b, 0xb5, ticks >> 8));
    TRY(checked(b, 0xb6, ticks));
    TRY(checked(b, 0xb3, 2));
    return wr(b, 0xb0, 1);
}
int sensor_start(const struct sensor_bus *b, struct sensor_sample *s) {
    /* nPM2100 remains powered across MCU System OFF and watchdog resets. */
    TRY(sensor_sensors_off(b));
    TRY(sensor_watchdog_start(b, 20));
    TRY(adc(b, 0, &s->battery_mv));
    if (s->battery_mv < SENSOR_MIN_BATTERY_MV)
        return -ERANGE; /* Board input floor; no cell-capacity claim. */
    TRY(checked(b, 0x22, 30));
    TRY(checked(b, 0x23, 1)); /* 3.3 V */
    TRY(checked(b, 0x24, 1)); /* Force HP for sensor conversion accuracy. */
    TRY(wait_pm(b, 0x34, 7, 0)); /* Confirm actual converter state is HP. */
    b->delay_ms(b->ctx, 5);
    TRY(adc(b, 4, &s->output_mv));
    if (s->output_mv < 3150)
        return -ERANGE;
    TRY(checked(b, 0x6a, 5));    /* Load switch, forced HP, not default LDO. */
    TRY(checked(b, 0x6f, 0x14)); /* 40 mA load-switch OCP, retain LDO default. */
    TRY(checked(b, 0x6c, 1));
    TRY(checked(b, 0x69, 1));
    TRY(wait_pm(b, 0x6e, 0x16, 6));
    b->delay_ms(b->ctx, 5);
    return 0;
}
int sensor_ota_start(const struct sensor_bus *b) {
    /* OTA can last minutes: do not arm the 20-second PMIC watchdog or
     * enable the switched sensor rail. Keep only the radio supply on. */
    TRY(sensor_sensors_off(b));
    TRY(wr(b, 0xb1, 1));
    TRY(wait_pm(b, 0xb7, 0xff, 0));
    TRY(checked(b, 0x22, 30));
    TRY(checked(b, 0x23, 1));
    TRY(checked(b, 0x24, 1));
    TRY(wait_pm(b, 0x34, 7, 0));
    return 0;
}
static int fdc_read(const struct sensor_bus *b, uint8_t reg, uint16_t *v) {
    uint8_t r[2];
    TRY(transfer(b, 0x50, &reg, 1, r, 2));
    *v = ((uint16_t)r[0] << 8) | r[1];
    return 0;
}
static int fdc_write(const struct sensor_bus *b, uint8_t reg, uint16_t v) {
    uint8_t w[] = {reg, v >> 8, v};
    return transfer(b, 0x50, w, 3, 0, 0);
}
static int capacitance(const struct sensor_bus *b, unsigned ch, int32_t *ff, uint8_t *dac) {
    /* Only single-ended CAPDAC mode: this PCB physically ties SHLD1 to SHLD2. */
    for (unsigned d = 0; d < 32; d++) {
        TRY(fdc_write(b, 8, (ch << 13) | (4 << 10) | (d << 5)));
        TRY(fdc_write(b, 12, 0x480)); /* One measurement, 100 sps, no repeat. */
        unsigned i;
        uint16_t status = 0;
        for (i = 0; i < 30; i++) {
            TRY(fdc_read(b, 12, &status));
            if (status & 8)
                break;
            b->delay_ms(b->ctx, 1);
        }
        if (i == 30)
            return fault(b, -ETIMEDOUT, 0x50, 12, status, 8, 8);
        uint16_t hi, lo;
        TRY(fdc_read(b, 0, &hi));
        TRY(fdc_read(b, 1, &lo));
        uint32_t u = ((uint32_t)hi << 8) | (lo >> 8);
        int32_t raw = u & 0x800000 ? (int32_t)u - 0x1000000 : (int32_t)u;
        /* Keep 2 pF margin from the +/-15 pF specified measurement limits. */
        int32_t residual = (int64_t)raw * 1000 / 524288;
        if (residual > 13000)
            continue;
        if (residual < -13000)
            return -ERANGE;
        *ff = residual + (int32_t)d * 3125;
        *dac = d;
        return 0;
    }
    return -ERANGE;
}
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

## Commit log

2026-07-30 Rework board for nRF54L15 + nPM1300 + FDC1004
    Replaces the abandoned XIAO ESP32-C6 / MAX17222 / analog-probe design.
    Hardware:
    - nRF54L15-QFAA (QFN48 6x6, 0.4mm pitch), Nordic reference circuit config 1
    - nPM1300-QEAA PMIC (QFN32) for charge, power path, ADC and fuel gauge,
    replacing BQ25185 + TPS7A02
    - FDC1004 capacitive front end, VSSOP-10, gated by nPM1300 LOADSW1
    - USB-C plus solar input via a 5V pre-regulator (part still TBD)
    Design decisions verified against datasheets, not vendor libraries:
    - 3.3V rail must come from BUCK2: R_VSET1 tops out at 2.7V (Table 17),
    only R_VSET2 reaches 3.3V (Table 18). BUCK1 disabled by grounding VSET1.
    - I2C pull-ups on always-on +3V3, NOT on the sw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
    [moisture-sensor-carrier.kicad_pcb, moisture-sensor-carrier.kicad_sch]
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2026-07-30 Add SHT45-AD1F ambient RH/T sensor
    Primarily a compensation input, not a feature: water permittivity falls
    ~0.4 %/C, which on a 5-15 pF soil reading is 20-60 fF/C - about 100x the
    FDC1004's own 0.28 fF/C offset drift. Without ambient temperature you
    cannot separate wetter soil from a warmer room.
    That makes T accuracy the deciding spec, so SHT45 (+/-0.1 C) over SHT40/41
    (+/-0.2 C) and definitely over SHT43 (+/-0.48 C, which would make
    temperature the dominant moisture error). RH accuracy is near-irrelevant
    by comparison.
    Sits on always-on +3V3, NOT the gated FDC_VDD: Table 6 rates every pin at
    VSS-0.3..VDD+0.3 with no independent I/O rating, so gating it while the
    bus pull-ups are high vio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
    [moisture-sensor-carrier.kicad_sch]
2026-07-30 Add RF/layout constraints, 4-layer stackup, design rules
    Stackup (moisture-sensor-carrier.kicad_pcb): JLC04161H-7628 equivalent,
    4 layer 1.6mm. The 0.2104mm top prepreg is what makes a sane-width 50 ohm
    microstrip possible, so RF references In1.Cu.
    Impedance: W = 0.38mm, derived with the Hammerstad thickness correction.
    Note er falls to ~4.2 at 2.4GHz from the datasheet's 4.4 at 1MHz -
    designing to 4.4 gives a trace that is too narrow. DRU allows 0.34-0.42.
    Antenna: PCB inverted-F recommended, copied from Nordic's reference. The
    deciding argument is that the matching network already in the schematic is
    Nordic's and is only valid for their antenna geometry - a chip antenna
    means discarding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
    [moisture-sensor-carrier.kicad_pcb]
2026-07-30 Correct MCU support circuit against Nordic QFAA reference layout 0.8
    The reference layout package exposed four real errors in the support
    circuitry, all of which were plausible-looking but wrong:
    - DCC -> L1 -> DECD, then DECD -> FB1 -> DECA. I had L1 feeding VDD and
    FB1 in series with the supply rail. Different circuit entirely.
    - DECRF (33) is the SAME NET as DECA (43), not separately decoupled. The
    C14 100nF I had invented is not in Nordic's BOM.
    - C13 3.9pF is the RESET filter cap, not an RF matching component. It is
    drawn next to the matching network on Nordic's sheet, which is how it
    ended up in the RF chain. The chain ends at the C11 shunt.
    - C5 2.2nF belongs on DECA, not on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
    [moisture-sensor-carrier.kicad_pcb, moisture-sensor-carrier.kicad_sch]
2026-07-30 Fix pin assignment against nRF54L15 datasheet; NTC now fitted
    Datasheet v1.0 invalidated two of the three signal assignments:
    - TWIM SCL MUST be on a dedicated clock pin (Table 77). P1.09 is not one.
    Moved SCL to P1.11 (pin 39); QFAA clock pins are P0.03/04, P1.03/04/08/
    11/12, P2.01/06. SDA moved to the physically adjacent pin 38 because the
    datasheet requires the data signal near the clock pin for delay matching.
    - PMIC_INT was on P2.00, but Table 40 says P2 cannot wake the system and
    has no SENSE/DETECT or GPIOTE - it could never have woken the MCU from
    System OFF. Moved to P0.00 in the low-power domain.
    - Also: peripherals cannot mix pins across ports, so SDA/SCL are both P1.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
    [moisture-sensor-carrier.kicad_sch]
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2026-07-30 Assign footprints to all 54 components; add BOM.md
    Hand-solder variants throughout, except the RF matching network (L2/L3/L4/
    C6/C9/C11) which stays 0201 standard - Nordic's values are matched to their
    reference land pattern and hand-solder pads shift a 0.3pF cap at 2.4GHz.
    MCU support passives moved from Nordic's 0201 to 0402 for assembly.
    Two symbol corrections found while assigning:
    - X1 was a 4-pin Crystal_GND24_Small, but 32.768kHz 2012 parts are 2-pin
    and only 2-pin 2012 footprints exist. Now Crystal_Small.
    - J1 was the 24-pin USB_C_Receptacle; swapped to USB_C_Receptacle_USB2.0_16P
    to match the HRO TYPE-C-31-M-12 footprint.
    Crystal constraints from datasheet 11.9.1/11.9.2: C_L i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
    [moisture-sensor-carrier.kicad_sch]
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2026-07-30 Draw board outline, zoning and PCB antenna
    Board is 34.0 x 155.0 mm: a 74 x 34 mm section inside a Hammond 1551WK
    (IP68 polycarbonate, 74.50 x 34.50 max PCB, 17.30 mm internal) with a
    20 mm probe protruding through the end wall. Soil line at y=115 puts the
    antenna 112 mm clear of it; insert depth 40 mm.
    Generated by tools_gen_pcb.py, which self-checks and aborts rather than
    emitting broken geometry. DRC 0 violations.
    The Nordic QFAA reference layout 0.8 contains no PCB antenna - it is a
    15 x 13 mm MCU support board that terminates the RF chain at an edge pad.
    The IFA is therefore designed for this board rather than copied, and the
    matching network values are a starting point rather than a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
    [moisture-sensor-carrier.kicad_pcb]
2026-07-30 Net-tie the RF grounds; swap J2/J3/J4 for the height budget
    Both changes land in tools_gen_sch.py. ERC 0/0, DRC 0/0.
    RF grounding. Nordic requires C6 to ground only at pin 32 (VSS_PA) on the
    top layer with pin 32 reaching pin 49 only under the package, and C9 to
    ground only on the bottom layer. Electrically one node, so invisible in a
    netlist. Split into /GND_PA (C6.2, U1.32) and /GND_C9 (C9.2), rejoined by
    NT1 and NT2. Three DRU rules enforce the routing half - verified by
    injecting illegal geometry and confirming each fires. The placement half
    (NT1 under U1 on F.Cu, NT2 on B.Cu) goes in tools_gen_pcb.py.
    /GND_PA carries a PWR_FLAG: U1 pin 32 is a power input and splitting it
    off GND left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
    [moisture-sensor-carrier.kicad_pcb, moisture-sensor-carrier.kicad_sch]
2026-07-30 Place all 56 components; probe electrodes; USB-C edge mount
    ERC 0/0. DRC: 0 errors, 4 isolated-copper warnings and 128 unconnected
    items, all of which are "nothing is routed yet".
    tools_gen_pcb.py now imports the exported netlist and places from a table,
    so the board cannot drift from the schematic. It asserts and aborts on:
    courtyard overlap, board-edge clearance, mounting-screw clearance, nothing
    but AE1 in Zone A, both net-tie placement rules, and SENSE-to-SWITCH
    separation. Six real collisions were caught and fixed this way.
    Zoning per LAYOUT.md 4 and 6: RF chain in a column at x=16.8 straight up
    from U1 pin 31 to the antenna feed, U1 rotated 90 so ANT faces Zone A,
    nPM1300 SW2 loop at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
    [moisture-sensor-carrier.kicad_pcb, moisture-sensor-carrier.kicad_sch]
2026-07-30 Wire up the Nordic QFN 3D models; report 3D coverage
    Both Nordic STEP files were already in lib/nordic but neither vendor
    footprint referenced them. Extracted their bounding boxes to confirm the
    convention matches KiCad's before trusting them: centred on origin,
    +/-2.997 and +/-2.502 in x/y, z running 0 to 0.892 up from the board. No
    offset or rotation needed.
    tools_gen_pcb.py now reports 3D coverage instead of letting it drift:
    which references have no model, and which point at files not on disk.
    Not fatal - a missing model changes no copper - but it does block
    checking the enclosure fit in 3D.
    Still absent from this KiCad install: USB_C_Receptacle_HRO_TYPE-C-31-M-12,
    the SHT4x DFN-4, and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
    [moisture-sensor-carrier.kicad_pcb]
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2026-07-30 X1 = CM8V-T1A 7pF; horizontal connectors; 3D models and enclosure
    X1 selected: Micro Crystal CM8V-T1A 32.768 kHz, CL 7 pF, +/-20 ppm.
    Checked against every line of the nRF54L15 LFXO table (11.9.2): CL 7 pF
    in a 6-9 window, C0 1.2 against typ 1.0 max 2.0, RS 55/70 kOhm against
    typ 60 max 100, drive 0.5 uW exactly matched, tolerance +/-20 ppm against
    a +/-500 ppm BLE requirement. 7 pF beats the 9 pF the reference BOM
    suggested - 9 sits at the hard maximum, 7 sits mid-window with room for
    PCB stray either side.
    Using Micro Crystal's own land pattern. KiCad's generic 2012 footprints
    do not match the datasheet: handsolder is 1.05 mm pads on 1.85 mm centres
    and nominal is 0.6 on 1.4, against the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
    [moisture-sensor-carrier.kicad_pcb, moisture-sensor-carrier.kicad_sch]
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2026-07-30 Flip the enclosure model; make it hideable on its own
    Hammond's STEP has its screw side facing the board, so the rotation goes
    to +90 about X rather than -90, with the Z offset retuned to 14.7 so the
    box interior floor lands 5.60 mm below the board top face.
    Two ways to get it out of the way now. The footprint deliberately carries
    no smd/through_hole attribute, so KiCad's 3D viewer files it under Other
    and it can be switched off on its own without hiding real parts; and
    SHOW_ENCLOSURE at the top of tools_gen_pcb.py drops it entirely.
    ENCL_ROT and ENCL_Z are named constants so the fit can be tuned without
    hunting through the file.
    [moisture-sensor-carrier.kicad_pcb]
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2026-07-30 D5 = Panjit RB751V-40; X2 = Epson FA-128 8 pF
    D5: 370 mV at 1 mA, 300 mA, 40 V reverse, 500 nA leakage, SOD-323,
    $0.14. Chosen over BAT201M3, which has a lower drop (290 mV at 10 mA)
    and 1 A rating but only 20 V reverse - thin against the 22 V VBUS abs max
    that HARDWARE.md section 4 leans on - and 50 uA leakage. Recorded two
    traps from the same search: RB751V-40WS and RB751V-40X share the 370 mV
    figure but are rated 30 mA not 300, and BAS70WS/BAT42WS/BAT43WS all quote
    1 V forward.
    X2: 2016 was never a requirement, only Nordic's reference BOM. The
    datasheet characterises 2.0x1.6 and 1.2x1.0 and mandates neither - the
    small one passes at 100 ohm ESR because its C0 is 0.42 pF. C0 and ESR
    trade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
    [moisture-sensor-carrier.kicad_pcb, moisture-sensor-carrier.kicad_sch]
2026-07-30 Cell = Adafruit 258 (1200 mAh); confirm L1 against Murata's product page
    Cell: 34.0 x 62.0 x 5.0 mm, 1200 mAh, $9.95, in stock. Beats the 503450
    this design was sized around - same thickness and width, 20% more
    capacity, and a stocked catalogue part. Runtime 3.45 yr; power budget
    tables in HARDWARE.md section 7 rescaled to 1200 mAh.
    Everything else in the Adafruit range either exceeds the 34.92 mm box
    interior (2011 at 36 mm, 328 at 50 mm) or the height budget (3898 at
    8.2 mm leaves 3.5 mm and fouls the connectors). Full fit table in BOM.md.
    Two things flagged before ordering: the width margin is 0.92 mm total and
    the datasheet filename says 503562 - a 35 mm nominal cell would not fit,
    so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
    [moisture-sensor-carrier.kicad_pcb, moisture-sensor-carrier.kicad_sch]
2026-07-30 Cell = Adafruit 1578 (500 mAh); J2 = 2-pin JST PH
    Cell drops from the 258 to the 1578 for fit margin. The 258 is 34.0 mm
    across a 34.92 mm interior and its part code (503562) implies a 35 mm
    nominal cell that would not go in at all; pouch cells also swell. 1578 is
    29 mm across, 6 mm of slack, at a cost of 0.5 years (2.9 vs 3.45).
    J2 becomes a 2-pin JST PH so an Adafruit cell plugs straight in. Drops the
    pack-NTC pin, which costs nothing - Adafruit cells are 2-wire with no
    thermistor, so the NTC path was always TH1.
    PH is 8 mm against 6.90 mm of clearance under the cell, so tools_gen_pcb.py
    now models the cell footprint and asserts that anything in COMPONENT_HEIGHTS
    taller than the gap sits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
    [moisture-sensor-carrier.kicad_pcb, moisture-sensor-carrier.kicad_sch]
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2026-07-30 SHT45 on a routed thermal island; move it out of the cell shadow
    Sensirion's design guide section 3 says the dominant error path is
    conduction through the PCB and the fix is milled slits around the sensor
    (Figures 8b and 11b). U4 now sits on a peninsula formed by a C-shaped
    1.0 mm routed slot, joined to the board by a single 2.8 mm neck. Not a
    closed ring - the traces have to reach the pads, and Sensirion's own
    figures show a neck.
    This exposed a placement problem: U4 was at (30.0, 34.5), inside the cell
    footprint. The cell is the largest thermal mass on the assembly and warms
    while charging at 500 mA, so the sensor was sitting under the worst
    possible thing. Moved to (29.5, 23.0) - 6.9 mm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
    [moisture-sensor-carrier.kicad_pcb]
2026-07-30 Circular SHT peninsula; fold in the corrected USB-C 3D orientation
    The SHT45 island is now a 2.2 mm radius circle cut by an annular 1.0 mm
    slot with a 60 degree opening, giving a 2.7 mm neck. Round rather than
    rectangular: no stress-raising inside corners, and the island edge is a
    smooth arc.
    More importantly the slot now clears the board edge by 2.2 mm. The
    rectangular version left 0.6 mm - a fragile sliver of FR4 exactly where
    the box wall sits. The generator asserts a 2.0 mm minimum, and separately
    that U4's furthest corner is inside the island radius and that the slot
    does not encroach on the antenna keepout.
    J1's 3D model orientation, corrected by hand in the viewer, is folded into
    MO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
    [moisture-sensor-carrier.kicad_pcb]
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2026-07-30 PVSS2 net tie; fix DRU ordering that had disabled every width rule
    Nordic's reference schematic (nPM1300 PS 9.3.2) annotates PVSS1 'Net tie'
    and 'Via to GND-layer'. Pin 6 is BUCK2 power ground, not a general ground
    pin. Split to /GND_PVSS2 carrying C24.2 and U2.6, rejoined by NT3 at the
    via. C24 returns to it so the SW2 -> L10 -> C24 -> PVSS2 loop closes
    locally rather than through the plane. PVSS1 stays on GND - BUCK1 is
    disabled and carries nothing.
    NT3 uses a new compact net tie: the stock 0.5 mm one does not fit the
    0.69 mm gap between C24 and U2.
    Separately, and more important: verifying the new width rule uncovered
    that ORDERING had silently disabled every width rule in the file. 'Fa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
    [moisture-sensor-carrier.kicad_pcb, moisture-sensor-carrier.kicad_sch]
2026-07-30 Re-export enclosure parts as AP203; default to the combined model
    Second attempt at the split-model rendering. Tried AP214 (default), AP203,
    both .step and .stp extensions, and explicit MM units. Every variant loads
    without error and draws nothing, while Hammond's combined .stp renders
    fine. Not resolved - defaulting ENCL_SPLIT to False so the viewer works,
    with the split files kept for the GUI 3D viewer, which is a different code
    path from kicad-cli.
    [moisture-sensor-carrier.kicad_pcb]
2026-07-30 SHT45 on a jut-out through the enclosure wall
    The sensor now leaves the box entirely on a 5.0 mm wide tab through the
    long side wall, so it reads outside air instead of the inside of a sealed
    enclosure. Replaces the routed thermal island, which isolated the sensor
    from the board but left it breathing the box.
    Board is 34.0 wide centred in a 34.92 interior, so the wall runs
    34.46 -> 37.00. The tab reaches x = 42.0 and U4 sits at (39.8, 20.6),
    1.58 mm proud of the wall outer face. The generator asserts U4 clears
    37.00 - otherwise the sensor sits in the wall rather than outside it.
    Board overall goes to 42.0 x 155.0 mm; verified against the exported SVG
    viewBox at 41.99 x 154.99.
    Needs a mill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
    [moisture-sensor-carrier.kicad_pcb]
2026-07-30 Hand-fillet the jut-out corners; freeze the PCB generator
    Manual gr_arc fillets on the Edge.Cuts corners of the SHT45 jut-out.
    Outline still closes, extent unchanged at 41.99 x 154.99 mm, DRC still
    0 errors with the same 4 isolated-copper warnings.
    tools_gen_pcb.py is now marked superseded for geometry. main() strips
    every drawing and redraws from scratch, so re-running it would silently
    destroy the fillets. Kept for reference: the constants document every
    dimension and the self-checks record what has to stay true.
    [moisture-sensor-carrier.kicad_pcb]
2026-07-31 Fix three defects in the DRU that had disabled most of the rule file
    None of these were visible by reading the file; all three were found by
    injecting geometry that should trip a rule and seeing what actually fired.
    1. "Fab minimum clearance" had the same last-match-wins problem that had
    already been found and fixed in the track_width family. It matches every
    pair of items and sat at the bottom, so it was overriding every specific
    clearance rule: the RF 0.5 mm rule and all four sense/shield rules. It also
    overrode the netclass clearances. Hoisted above the specific rules, next to
    "Fab minimum track".
    2. "Charge path width" used A.Net, which is not a valid property. It parses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
    [moisture-sensor-carrier.kicad_pcb]
2026-07-31 Route the RF path; add tools_route.py
    RF chain routed U1 pin 31 -> L2 -> C6 -> L3 -> C9 -> L4 -> C11 -> AE1 feed,
    entirely on F.Cu, no vias on any RF net. 18 segments, 3 vias. Unconnected items
    127 -> 116. DRC: 0 errors, the same 4 isolated-copper warnings as before.
    Verified: RF widths are 0.2032 and 0.38 mm only, all RF copper is on F.Cu, zero
    vias on RF nets, /GND_PA is F.Cu-only with no vias (Nordic rule 1), /GND_C9
    touches F.Cu and B.Cu only (Nordic rule 2). Board graphics, all 59 footprint
    positions and all zone outlines are bit-identical to before routing.
    NT1 needs no copper: its pads physically overlap U1 pad 32 and pad 49, so the
    tie is made by the land pattern. That is what the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
    [moisture-sensor-carrier.kicad_pcb]
2026-07-31 Restore fab-layer refdes; attach the X2 3D model; strip duplicate QFN markers
    Your GUI session did two good things - it gave every footprint its proper
    library prefix (Capacitor_SMD:, footprints:, ...) instead of the bare names the
    generator emitted, and it brought in the new Epson-specific X2 land pattern. It
    also reset text fields to library defaults as a side effect, which put 55 of 59
    reference designators on F.SilkS instead of F.Fab and produced 68 silkscreen
    warnings on a board full of 0402s. References are back on the fab layer, which
    is what tools_gen_pcb.py intended. Values stay visible on F.Fab as the GUI left
    them - they are not on silkscreen so they cost nothing.
    X2 checks out: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
    [moisture-sensor-carrier.kicad_pcb]
2026-07-31 Correct the stackup: order plain JLC04161H-7628, not 7628D. Remove J5.
    Stackup, re-read against JLCPCB's own published list (Controlled Impedance PCB
    Layer Stackup, filtered to 1.6 mm / 1oz outer / 0.5oz inner):
    LAYOUT.md said 7628D was the ONLY 4-layer 7628 variant with a single 0.21040 mm
    prepreg under the top layer. That is wrong - THREE of the eighteen entries have
    it: the default "No requirement Stackup", plain JLC04161H-7628, and 7628D. The
    first two have a 1.065 mm core and sum to 1.586 mm, a real 1.6 mm board. 7628D
    has a 1.265 mm core and sums to 1.786 mm.
    That is exactly what the open "confirm the total thickness" question in
    NEXT-STEPS.md was detecting - 7628D was never going to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
    [moisture-sensor-carrier.kicad_pcb, moisture-sensor-carrier.kicad_sch]
2026-07-31 Regenerate the schematic - J5 had come back
    The .kicad_sch had been reverted to a pre-removal state: J5's symbol and the
    Connector_Generic:Conn_01x01 library symbol were both back, with heavy
    reformatting, which is the signature of eeschema saving an older in-memory copy
    over the generated file. tools_gen_sch.py itself was untouched and still had J5
    removed, so re-running it was the whole fix.
    Verified: 0 J5 references in the schematic, ERC 0 violations, schematic 56
    components against 58 board footprints - the two board-only entries are AE1 and
    MP1, which have no schematic symbols by design. /ANT_FEED is C11.1 + L4.2 in the
    netlist plus AE1.1 on the board. No eeschema is running on this pr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
    [moisture-sensor-carrier.kicad_sch]
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2026-07-31 Select the solar panel and 5 V pre-regulator
    Panel: 2 x Panasonic AM-1815CA in series (16 a-Si cells). V_OC 10.0 V and
    loaded 6.0 V - 45.7 uA at FL 200 lx, from Panasonic's Amorton brochure, which
    publishes both per-cell and per-part figures at that illuminance. Cell count
    read off the part number via the brochure's own decoder and cross-checked
    against 0.63 V/cell.
    Pre-regulator: U5 = TI TPS7A1650 (fixed 5.0 V LDO, HVSSOP-8), C30/C31 =
    10 uF/25 V X5R 0603, the same part as C21/C22/C24. No inductor, no feedback
    network.
    The LDO wins on input rating, not efficiency. The panel's cold bright V_OC is
    15.8 V (0.89 V/cell at AM1.5, -0.45 %/C, 0 C), so the 1.5x rule needs 23.7 V.
    TPS62122 is 2-15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
    [moisture-sensor-carrier.kicad_sch]
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2026-07-31 Replace the PCB inverted-F with a U.FL connector; the board now fits the box
    AE1 is gone. J5 is a Hirose U.FL-R-SMT-1(10) receptacle feeding an external
    adhesive antenna mounted inside the enclosure on a pigtail.
    This fixes two problems at once.
    MECHANICAL. The 1551WK's four corner bosses need PCB corner reliefs, and at the
    antenna end those reliefs cut straight through the IFA's radiating arm. With the
    IFA gone, all four reliefs go in: concave R4.669 arcs centred on each boss, a
    0.25 mm margin, meeting the board edge 5.749 mm in from each corner. At the probe
    end the relief runs straight into the R2.0 shoulder fillet with no straight
    segment between them, so the two 0.5 mm stubs at y=114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
    [moisture-sensor-carrier.kicad_pcb, moisture-sensor-carrier.kicad_sch]
2026-07-31 Corner reliefs were too small - R4.669 interfered. Now R5.0, with diagrams
    You were right that the cutouts looked off. They were.
    The R4.669 relief was solved against the corner BOSS CIRCLE alone. That is not
    the whole cavity corner: an R1.0 blend joins each wall to the boss, and it
    intrudes slightly further than the boss circle. Checked against the actual
    measured cavity boundary rather than the idealised circle:
    R4.669 cut-back 5.749 clearance -0.0278 mm <- interferes
    R5.000 cut-back 6.091 clearance +0.2624 mm <- now used
    R5.500 cut-back 6.606 clearance +0.5348 mm (saturates at the 0.545 side gap)
    Sampling the whole outline had previously only been done agains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
    [moisture-sensor-carrier.kicad_pcb]
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2026-07-31 Place U5/C30/C31 in the solar reserve; solar is populated on every board
    Two changes.
    SOLAR_DNP is now False. It was briefly DNP-by-default on the theory that most
    units ship without a panel, but the parts are three passives and an LDO sitting
    in space that was already reserved for them, and a populated board is upgraded by
    plugging a panel in rather than by reworking one. J3, D5, U5, C30 and C31 are all
    populated; nothing in the schematic carries a DNP flag.
    U5, C30 and C31 are placed in the reserve below J3, in the Power-in band:
    U5 board x 24.37..30.63 y 50.75..54.25 HVSSOP-8, 6.26 x 3.50 courtyard
    C31 board x 23.85..27.15 y 48.27..49.73 output cap, nearest pin 1 (OUT)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
    [moisture-sensor-carrier.kicad_pcb, moisture-sensor-carrier.kicad_sch]
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
